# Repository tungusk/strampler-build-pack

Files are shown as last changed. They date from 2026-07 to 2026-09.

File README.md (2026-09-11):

# Strämpler Build Pack

Everything you need to **build your own [CTAG Strämpler](https://github.com/ctag-fh-kiel/ctag-straempler)** —
the open-source ESP32 eurorack sample-streaming module — in its compact
**18 HP Antumbra redesign**. Board files in both Eagle *and* KiCad, complete
BOMs with 2026 sourcing fixes, a ready-to-upload fab/assembly package, and
per-kit ordering guides.

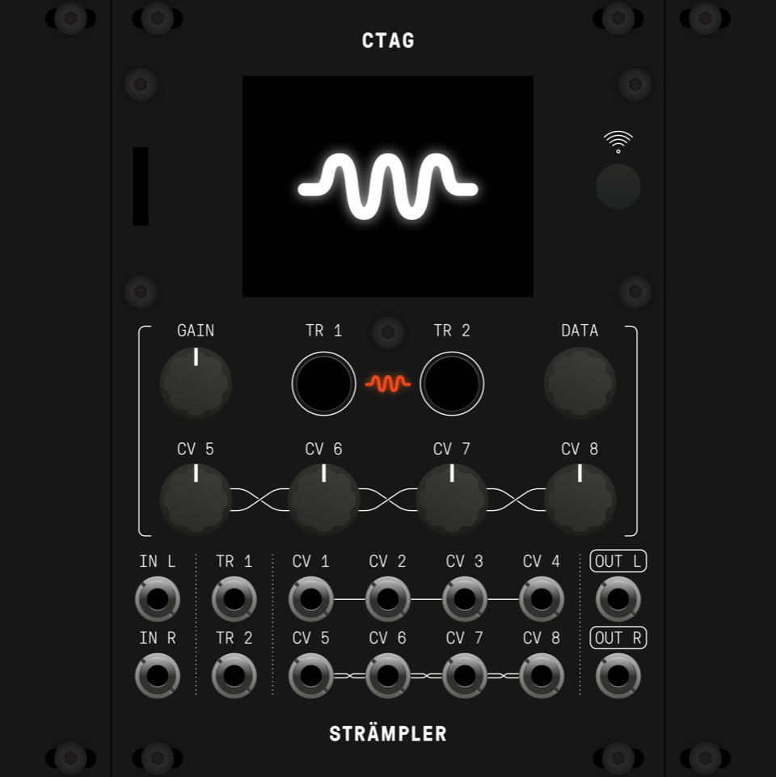
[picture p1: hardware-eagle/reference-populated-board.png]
Antumbra Strämpler


## Why this repo exists

The original design files live inside the firmware repo and are in **Eagle
format — a dead tool** (Autodesk sunset Eagle in 2026). The ready-made
panel/PCB sets that used to be sold are delisted. Several key parts of the
2019 BOM have gone EOL. This pack collects the originals, converts them to
a living format, and documents what it actually takes to build one today.

## What's here

| Path | Contents |
|---|---|
| `hardware-eagle/` | The designer's original Eagle 7.3 files: main board + schematic + FR4 panel (untouched) |
| `hardware-kicad/` | **KiCad 10 conversion** — full linked project (schematic + board + symbol lib), converted panel, 3D verification renders, schematic PDF |
| `bom/` | Official Antumbra BOM (Mouser refs), a schematic-derived cross-check BOM, a **Mouser BOM-tool upload file for one kit**, the non-Mouser parts list, and the CTAG RevD reference BOM |
| `assembly-pcbway/` | Ready-to-upload turnkey assembly package: fab BOM, pick-and-place (CPL), order guide, price estimate |
| `KIT-GUIDE.md` | Ordering bare boards + parts as DIY kits, per-kit costs, build order, licensing |
| `KNOB-OPTIONS-20260911.md` | Knob-cap shopping: what is fitted, the panel's 19.27 mm row gap that caps knob diameter, and the Thonk / AliExpress options screened against it |

## 2026 sourcing notes (the important bits)

- **WM8731 codec: obsolete.** Broker stock only (Rochester Electronics for
  genuine EOL parts). The assembly package marks it DNP for hand-soldering.
- **ESP32-WROVER-B: NRND** → use **ESP32-WROVER-IE** (the **-I**/IPEX
  external-antenna variant is required — the module lives behind a metal panel).
- Jacks/pots/SD from [Thonk](https://thonk.co.uk); TFT + antenna from AliExpress.
- Rough costs: **~$160–195/kit** DIY, **~$350–420** for a fab-assembled build.
  Details in `KIT-GUIDE.md` and `assembly-pcbway/PRICE-ESTIMATE.md`.

## Firmware

- Upstream: [ctag-fh-kiel/ctag-straempler](https://github.com/ctag-fh-kiel/ctag-straempler) (GPL 3.0)
- Extended fork with the multi-machine firmware (drum sampler, looper,
  slicer, granular, glitch, Freesound browser, web teleremote):
  [tungusk/ctag-straempler](https://github.com/tungusk/ctag-straempler), branch `v09-machines`
- Flash with `--flash_size detect`; see the firmware repos for build docs.

## Licensing — read before selling anything

- **Hardware: CC BY-NC-SA 4.0** (unchanged from upstream — see `LICENSE.md`).
  Build for yourself, share these files, remix them: all encouraged.
  **Selling boards/kits/modules requires permission** from the rights
  holders (CTAG and Antumbra). Modifications you distribute must carry the
  same license.
- **Firmware: GPL 3.0** — commercial use allowed with source provision.

## Provenance & changes

Original design © 2019 Robert Manzke, Phillip Lamp, Niklas Wantrupp
([CTAG, Kiel UAS](https://www.creative-technologies.de)); PCB redesign by
David Szebenyi ([Antumbra](https://antumbra.eu)). This pack adds (2026-07,
CC BY-NC-SA 4.0): the KiCad 10.0.4 conversion (`kicad-cli pcb import` for the
boards, GUI Eagle-project import for the schematic; auto-matched layers,
KiCad layer names), generated CPL and fab BOMs, the Mouser kit BOM with EOL
substitutions, verification renders/PDF, and the ordering/cost documentation.
Not affiliated with or endorsed by CTAG or Antumbra — errors are ours, not
theirs. Verify footprints against the Eagle originals before fabbing
modified boards.

## Experimental: E-mu-format panel (2026-09)

`panel-emu/` — a 6" × 6" E-mu Modular style front panel for the main board
with 1/4" Switchcraft jacks, bus-normalled CV/trigger inputs, and a ±12 V
regulator sub-board for the E-mu ±15 V bus. Parametric generator + SVG/DXF
cut and art files + README (BOM, wiring, E-mu conventions). One-off for a
hackerspace system; slow burn.

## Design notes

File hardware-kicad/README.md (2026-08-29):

# Editing the boards (KiCad 10+)

- **Main board + schematic**: open `project/Strampler_redesign_v2_2.kicad_pro`
  — a full linked project (schematic, board, and the Eagle-imported symbol
  library). Footprints are embedded in the board, so it is self-contained.
- **Panel**: open `strampler_panel_v2_2.kicad_pcb` directly in the PCB
  Editor. The artwork is ~34k filled polygons on F.Silkscreen; the copper
  pours are filled zones. It is heavy but edits fine.

After editing, regenerate all fab outputs (gerber zips + centroid) with:

```
./make-fab-files.sh
```

Both gerber sets passed PCBWay audit (2026-07) as generated by that script's
commands.

## Provenance & pitfalls

These files were converted from the Eagle 7.3 originals (`../hardware-eagle/`)
with KiCad 10.0.4. Two importer pitfalls are already fixed here — beware if
you ever re-import from Eagle instead of editing these files:

1. The importer creates **unfilled zones**, which plot as EMPTY gerber
   layers (missing copper, mask and artwork). Fixed by filling copper zones
   and converting non-copper zones to filled `gr_poly` shapes.
2. The importer maps Eagle's t/bRestrict layers to layer `"UNDEFINED"`,
   which KiCad's own parser then refuses to load. The first fix remapped
   them to `User.1` — **which was itself a bug**: `User.1` is not a copper
   layer, so the 1876 tiny restrict rectangles did nothing and the copper
   pours filled straight under the LED light window. The 2026-07 panel run
   came back with a **copper wave** where the original has bare FR4 (found
   2026-08-28 at first-module assembly). **Fixed 2026-08-28:** the 938
   unique rectangles (identical to the F/B.Mask window polygons) were merged
   into one polygon and replaced by a single **keep-out rule area on
   F.Cu + B.Cu** (`copperpour not_allowed`, named "LED light window");
   zones refilled; panel gerbers regenerated. Verified: filled copper ∩
   window = 0 on both layers.

## Main-board audit (2026-08-28) — keep-outs OK, one mask sliver restored

After the panel bug, the main board was checked for the same class of
loss. Eagle's `tRestrict`/`bRestrict` circles (mounting holes of P3 TFT,
jacks, PCB screws) and the `vRestrict` under the crystal all survived as
proper rule areas inside the footprints (`copperpour not_allowed` on
F.Cu/B.Cu; via keep-out on both). Verified with pcbnew: filled copper ∩
every keep-out = 0 (64 pairs). The only dropped item was a 0.15 × 1.3 mm
`tStop` sliver in the `SJ` (solder jumper) package — the mask opening
between SJ1's two pads that makes it bridgeable. Restored as an `fp_rect`
on B.Mask (SJ1 is on the bottom); main gerbers regenerated. The fabbed
2026-07 main boards lack that sliver: SJ1 can still be bridged, it just
takes a blob over the ~0.1 mm mask web. SJ1 joins ESP32 IO19 to TFT
connector pin 9.

## Panel v2_3 (2026-08-29) — M7 pot holes

`strampler_panel_v2_3.kicad_pcb` is the current panel: v2_2 plus the four
CV pot holes and POT1's hole resized 9.2/8.2 → 7.2 mm for M7-bushing pots
(Same Sky PTN091/PTN092 — see build-pack COMPLETION-SHOPPING §POT2–5).
The other 8.2 mm hole is the ENCODER's — deliberately unchanged.
`make-fab-files.sh` builds v2_3; v2_2 is kept as the pre-M7 version
matching the five fabbed (LED-window-defective) panels.

## Refilling zones from the command line

`kicad-cli` has no zone-fill command. After editing a board outside the
GUI (e.g. scripted changes), refill with the bundled Python before
running `make-fab-files.sh`:

```
PY=~/Applications/KiCad/KiCad.app/Contents/Frameworks/Python.framework/Versions/Current/bin/python3
$PY -c "import pcbnew; b=pcbnew.LoadBoard('strampler_panel_v2_2.kicad_pcb'); \
  pcbnew.ZONE_FILLER(b).Fill(b.Zones()); pcbnew.SaveBoard('strampler_panel_v2_2.kicad_pcb', b)"
```

(`SaveBoard` drops a stray `.kicad_pro` next to the panel — delete it.)

Verify against the Eagle originals and the `render-main-*.png` references
before fabbing modified boards. License: CC BY-NC-SA 4.0 (see ../LICENSE.md).

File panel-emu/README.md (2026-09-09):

# E-mu format front panel (experimental, one-off) — 6" × 6", 1/4" jacks

A vintage E-mu Modular style panel for the Strämpler main board, for the
local hackerspace's E-mu system. Not a board-house part: cut it from
aluminum on the mill or from plastic on the laser, then mark or engrave
the artwork. Generated by `gen_emu_panel.py` (parametric — edit the CONFIG
block, rerun, all files regenerate).

| file | what |
|---|---|
| `emu_panel.svg` | true-scale (mm), two groups: `CUT` (red hairline) and `ART` (black text, blue rules) |
| `emu_panel_cut.dxf` | outline + every hole, layer `CUT` — the file for the mill / laser |
| `emu_panel_art.dxf` | text + lines, layer `ART` — for engraving / laser-marking / a print mask |
| `emu_panel.png` | preview |
| `emu_panel_art.svg` / `emu_panel_art.png` | artwork only, transparent (PNG 600 dpi) — the file UV-print vendors take |
| `emu_panel_fpe.fpd` | Front Panel Designer project: cut DXF imported + art PNG placed, 2 mm natural anodized — priced $89.72 on 2026-09-08 |

## Format facts (E-mu Modular, 1970s)

- Modules are **6" high**, widths in **3" steps** (3 / 6 / 12"). The board
  footprint is 91.3 mm ≈ 3.6", so this panel is one 6" × 6" unit.
- Natural bright aluminum, black lettering, **blue accent lines**.
- **Mounting: the hackerspace cabinet has WOOD rails** (Arlo, 2026-09-07),
  so there is no fixed hole pattern to hit — the four corner holes
  (Ø4.2, clearance for #6 wood screws; use 3.6 for #4) just need to land
  on the rail and match the neighbouring modules' inset (0.25" from each
  edge is the placeholder). **Measure the rail height** (panel edge to the
  rail's inner edge, top and bottom): nothing that protrudes behind the
  panel can sit over the rail. The bottom jack rows (OUT L/R and CV 5–8,
  hole centres at y 17, nut edges at y 10.7) and the KYBD switches near
  the top need to clear it — if the rails are taller than ~10 mm those
  rows move inward. Countersink if the neighbours use flat-head screws.

## Panel thickness — the real constraint

The board's pots and encoder pass **through** this panel and are held by
their own nuts, so the panel can't be thicker than their bushings allow:

| part | bushing | max sensible panel |
|---|---|---|
| Same Sky PTN091/PTN092 pots (POT1–5) | M7 × **5 mm** long | **≤ 2.0 mm** (5 − 2.5 mm nut − thread engagement) |
| EC12 encoder (SW1) | M7, ~7 mm | 3 mm |
| Switchcraft 1/4" jacks | 3/8"-32, 0.276" (7 mm) | 3 mm |
| SMA bulkhead (ANT) | 1/4"-36, ~7 mm | 3 mm |

So: **1.5–2.0 mm aluminum** (1/16" = 1.6 mm is ideal, same as the FR4
panel), or 2 mm acrylic at most. 1/8" (3.2 mm) aluminum or 3 mm acrylic
will leave the pot nuts with no thread. If the shop only has 3 mm stock,
counterbore the six pot/encoder holes from the back to ~1.6 mm.

Board-locked cutouts (display window, 4 CV pots, gain pot, encoder, two
buttons, LED, antenna, five M3 panel screws) are copied verbatim from the
Eurorack panel `hardware-kicad/strampler_panel_v2_3.kicad_pcb` and only
translated by `BOARD_ORIGIN`. Countersink the five M3 holes if the panel
is aluminum (they take the panel-to-standoff screws).

Omitted on purpose: the Eurorack rail holes and the fourteen 3.5 mm jack
holes. The SD card slot (2.5 × 13 mm at the left edge) is **kept** — set
`INCLUDE_SD_SLOT = False` to drop it if the card is to stay inside. (The
TFT module's own SD socket is **not wired** to the ESP32; using it would
mean running the SD lines to it.)

## 1/4" jacks — wiring

The board's PJ398SM pads stay unpopulated; each 1/4" jack gets two flying
leads (tip → `IN` pad, sleeve → `GND` pad). The `NORM` (switch) pad is
tied to ground on the board, so **plain 2-lug TS jacks are all that's
needed** — no switching contact. Twist tip/sleeve pairs; audio in/out and
the two V/oct inputs get the shortest, tidiest runs.

| jack | signal | board pad (panel x, y mm) | jack hole (x, y mm) | lead ≈ |
|---|---|---|---|---|
| J5 | TR1 | 75.02, 47.35 | 15.40, 118.60 | 108 mm |
| J6 | TR2 | 75.02, 34.65 | 39.40, 118.60 | 106 mm |
| J7 | CV 1 (V/OCT between the pair) | 87.74, 47.35 | 15.40, 93.20 | 101 mm |
| J8 | CV 2 | 100.40, 47.35 | 39.40, 93.20 | 91 mm |
| J11 | CV 3 (±5V between the pair) | 113.20, 47.35 | 15.40, 67.80 | 115 mm |
| J12 | CV 4 | 125.93, 47.35 | 39.40, 67.80 | 104 mm |
| J2 | L (IN between the pair) | 62.29, 47.35 | 15.40, 42.40 | 62 mm |
| J1 | R (IN) | 62.29, 34.65 | 39.40, 42.40 | 39 mm |
| J4 | L (OUT between the pair) | 138.65, 47.35 | 15.40, 17.00 | 142 mm |
| J3 | R (OUT) | 138.65, 34.65 | 39.40, 17.00 | 116 mm |
| J9 | CV 5 (knob above) | 87.74, 34.65 | 68.65, 17.00 | 41 mm |
| J10 | CV 6 (knob above) | 100.40, 34.65 | 89.87, 17.00 | 36 mm |
| J13 | CV 7 (knob above) | 113.20, 34.65 | 111.08, 17.00 | 33 mm |
| J14 | CV 8 (knob above) | 125.93, 34.65 | 132.29, 17.00 | 34 mm |

Layout (Arlo 2026-09-07): **CV 5–8 jacks in a row across the bottom,
each directly below its knob** (same x as POT2–5), in the strip under the
PCB's bottom edge (the PCB is 108 mm tall inside the 128.5 mm panel
region, so the board region is raised to y = 18 and the jack row sits at
y = 17 with ~5 mm nut clearance to the PCB edge). The other ten jacks are
a 2 × 5 field on the left — TR1/TR2, CV 1/2, IN L/R, OUT L/R, CV 3/4 —
so the panel's bottom row reads CV 3…CV 8 in one line (Arlo 09-07). Blue artwork: an E-mu-style solid blue band 2.5 mm wide bleeding off the
panel edge (the art DXF carries its inner boundary; fill between it and
the panel outline), a rounded
box around the interface block, and ONE L-shaped rounded outline joining
the left jack field to the CV 5–8 row along the bottom (tops of the two
boxes aligned); wordmark "CTAG STRÄMPLER" alone between. Labels (Arlo 09-07): CV jacks read "CV 1"…"CV 8"; the V/OCT, ±5V, IN and OUT
words sit between the two jacks of their row (audio jacks read just L / R); the four attenuator
knobs read CV 5–8 like the jacks below them; trigger jacks are TR1/TR2 and
the two push buttons under the screen are labelled TR1/TR2 too (manual
triggers).

Jack field geometry: left field two columns 24 mm apart, five rows at 24 mm
pitch (tightened from 1" to make room for the bus toggles above); bottom row on the knob spacing (21.2 mm). Ø9.6 holes (3/8"-32
bushing). Plugs clear each other at both pitches. Switchcraft bodies are 0.5" wide × 0.62"
tall behind the panel — orient the lugs toward the board.

## Bus normalling — two ganged KYBD switches, one per column

Decided 2026-09-07: E-mu's two keyboard buses drive the two CV/trigger
pairs independently. Each column of the left field has its own **BUS
1 / off / 2** switch (one "BUS" word centred between the two switches; E-mu called it KYBD) at the top (x 15.4 and 39.4, y 131.5): a **DPDT
ON-OFF-ON** mini toggle (C&K 7203 ~$7, generic MTS-203 ~$1, Ø6.5 hole),
"1" and "2" marked beside it (up = keyboard 1, down = keyboard 2, centre
= that pair un-normalled). A light blue chain line runs straight down
each column centre from the switch through the TR jack to the V/oct
jack, broken around labels and holes, to show what it feeds.

| switch | pole A: VOICE 1/2 → | pole B: GATE 1/2 → |
|---|---|---|
| column 1 (x 15.4) | jack **1** (V/oct, J7) | **TR1** (J5) |
| column 2 (x 39.4) | jack **2** (V/oct, J8) | **TR2** (J6) |

Both on keyboard 1 = a mult (both pairs follow one keyboard; the VOICE
line just sees two high-impedance inputs). One on 1, one on 2 = two
players / keyboard + sequencer, each with its own CV and gate. Wiring per
pole: bus "1" line → up contact, bus "2" line → down contact, common →
that jack's **shunt (normal) lug**; tip lug → board `IN` pad; sleeve →
`GND`. With no plug the shunt closes to the tip and the bus drives the
input; a plug opens it. Four switching jacks (1, 2, TR1, TR2); the other
ten stay plain 2-lug. TR inputs get the keyboard **gate** (high while a
key is held) so gate length reaches the firmware; the bus TRIG pulse
lines are left unused (one-wire swap at the DIP end if ever wanted).

Facts behind this (see the research section): the buses come off a
**16-pin DIP socket** at the module position; E-mu gate/trigger is a
**positive 0/+5 V TTL** signal (7416 open-collector + 1 k pull-up), which
the board's 100 k / NPN trigger input takes directly — **no inverter**;
VOICE is 1 V/oct into CVIN0/1's 180k/47k networks, nothing to scale. Still
open: which DIP pins carry GATE 1/2 (meter it).

## Power conversion — ±15 V bus → ±12 V board (sub-board behind the PCB)

The E-mu bus is ±15 V; the Strämpler's rail caps are 16 V parts, so the
module carries its own linear regulators. **They are not on the panel**:
the cabinet's wood rails sit behind the panel's top and bottom strips,
so there is no depth there. Instead a **small regulator board mounts
behind the PCB** — on the PCB's existing M3 standoff holes with longer
M/F standoffs (or double-sided foam tape onto the PCB back), right next
to the Eurorack power header it feeds. 7812 gets a clip-on TO-220
heatsink (~1.5 W at the ESP32's 0.5 A → ~30 °C rise on a 20 °C/W clip,
fine); the 7912 runs cool. Ribbon from the cabinet's DIP socket to the
sub-board; short twisted leads from the sub-board to the header.

| qty | part | ≈ | notes |
|---|---|---|---|
| 1 | **L7812CV** (TO-220) | $0.60 | with clip-on TO-220 heatsink (e.g. Aavid 574502B00000G, ~$1) |
| 1 | **L7912CV** (TO-220) | $0.60 | tab = INPUT (−15 V): keep it clear of ground; no heatsink needed |
| 4 | M3 M/F standoffs (length = PCB rear clearance, ~10 mm) + M3 screws | | sub-board on the PCB's standoff holes |
| 1 | perfboard ~40 × 25 mm | | the sub-board |
| 2 | 1 µF 50 V ceramic (X7R) | | regulator inputs, close to the pins |
| 2 | 10 µF 25 V (ceramic or electrolytic) | | regulator outputs |
| 2 | 1N4007 | | reverse diodes output→input across each regulator (protects on power-down) |
| 1 | 16-pin DIP plug for ribbon (3M 3416-xxxx style IDC DIP plug) + ~30 cm 16-way ribbon | $2 | the bus pickup |
| 1 | 2 × 5 IDC socket or bare Eurorack power header pins | | into the board's P4 power header (10-pin: −12, GND, +12, +5, CV/gate) |
| — | heat-shrink, 0.5 A fuse holder (optional) | | |

Wiring: DIP pin 7 (+15) → 7812 IN, DIP pin 8 (−15) → 7912 IN, DIP pins 1–4
(GND) → both regulator commons + board GND. 7812 OUT → board
+12, 7912 OUT → board −12 via the Eurorack header (pin order per the
board's P4 silk: the shrouded header is keyed, red stripe = −12). Leave
the bus +5 unused (the board makes its own 3.3 V). Add a 0.5 A fuse in
the +15 lead if the cabinet supply is a vintage 2900/2910 (3 A / 2 A).
**Before first power-up:** meter the DIP socket in the cabinet — the pin
map came from a 1974 drawing and the socket keying is not documented.

Alternative that skips all of this: a separate ±12 V brick for the
module and only VOICE/GATE/TRIG/GND from the DIP.

## Jack sourcing (14 needed, buy 16)

Period-correct is the Switchcraft open-frame family; the panel doesn't
need the switch contact, so the 2-lug versions are the right ones.
Prices are 2026 list-ish from the usual dealers — verify at order time.

Of the 14: **10 × plain 2-lug** (rows below) + **4 × switching 12A/112A**
for the normalled inputs 1, 2, TR1, TR2 (see Bus normalling).

| option | part | type | ≈ each | notes |
|---|---|---|---|---|
| **vintage-correct** | **Switchcraft 11** | open frame, mono, 2 lugs | $3–4 | the classic 70s American-modular jack; Amplified Parts, Mouser 502-11 |
| enclosed, same feel | Switchcraft 111 (111X) | enclosed, mono, 2 lugs | $4 | dust-proof; same bushing |
| switching (not needed) | Switchcraft 12A / 112A | open / enclosed, shunt tip, 3 lugs | $4–5 | only if a future board uses NORM |
| budget | Rean NYS229 / Neutrik NJ2FD | enclosed, mono, solder lugs | $1.5–2 | Mouser/Digi-Key, fine electrically |
| cheapest | generic open-frame TS, AliExpress | | <$1 | check the bushing is 3/8"-32 |

All of these use the **3/8"-32 bushing → Ø9.5 mm hole** (the file uses
9.6 for clearance). Knurled nut + lock washer come with the Switchcrafts.

## E-mu Modular conventions — researched 2026-09-07

Primary source: the *Eµ Systems Modular Technical Manual* (schematics
1972–80, compiled by Rob Keeble; archive.org
`e-mu-modular-technical-manual`, 129 pp). Everything below was read off
the original drawings unless marked otherwise.

**Panels.** 6" high, widths in 3" steps. Vintage Synth Explorer: *"bright
and shiny 1/8" aluminum panels with nice blue lines separating each
module"* — so period panels were **1/8" (3.2 mm)** aluminum, black
lettering, blue lines. (Our pot bushings can't take 3.2 mm — see the
thickness table; counterbore or use 1/16".) The manual is schematics only:
**no mechanical drawings, no mounting-hole pattern** → still measure the
cabinet.

**The bus is a 16-pin DIP socket at every module position** (2900 Power
Supply Module schematic, doc 2900-001-001, 22 Apr 1973: "DIP SOCKETS (FOUR
IDENTICAL)"). Modules plug in with a DIP header on a ribbon. It carries:

| signal | notes |
|---|---|
| VOICE 1, VOICE 2 | the two keyboard CVs, 1 V/oct |
| GATE 1, GATE 2 | per keyboard |
| TRIG 1, TRIG 2 | per keyboard — **gate and trigger are separate lines** |
| SYNC 1, SYNC 2 | VCO sync buses (module-to-module, no PSU source) |
| GND, +15 V, +5 V, −15 V | |

Pin map read off the 2200 VCO module schematic (doc 2200-001-003, left
column 1–8 top→bottom, right column 16–9 top→bottom): **1–4 GND, 7 +15,
8 −15, 9 +5, 16 VOICE 1, 15 VOICE 2, 14 SYNC 1, 13 SYNC 2**. The
gate/trigger pins are among **5, 6, 12, 11, 10** (the VCO doesn't use
them; the 2350 TG drawing is too faint to assign them with confidence).
**Verify at the cabinet with a meter** before wiring: power pins are
unambiguous, VOICE/GATE/TRIG identify themselves when a key is pressed.

**Module convention for keyboard selection.** Every module has ONE
`KYBD 1 / 2` switch (VCO: 2-pole with SYNC 1/2 alongside; 2350 Transient
Generator: a ganged DPDT that selects keyboard 1 or 2 for BOTH its gate
and its trigger, and the module's EXT GATE / EXT TRIGGERING jacks are
**normalled from the selected bus through the jack's switch contact**).
That is exactly the scheme on this panel. To be E-mu-faithful the two
separate toggles would become **one ganged KYBD 1 / off / 2 switch**
feeding jack 1 (← VOICE) and TR1 (← GATE) — a DPDT ON-OFF-ON (C&K 7203,
or a generic MTS-203). **Adopted 2026-09-07, then doubled: a second
identical switch feeds jack 2 + TR2 from the second keyboard bus.**

**Gate / trigger polarity: POSITIVE, 0 / +5 V TTL.** 4000 Keyboard
schematic (doc 4000-001-003, 26 Jun 1973): TRIGGER (J4) and GATE (J3) are
**7416 open-collector outputs with 1 kΩ pull-ups to +5 V**. The 2200
VCO's own GATE INPUT is 100 k into a 2N3904 base with a 1N914 clamp —
the same topology as the Strämpler's TR inputs. **No inverter needed;**
a +5 V gate into our 100 k / NPN input is fine. (Not S-trig.)

**Keyboard cable (for reference):** 12-conductor Burndy, 4000 output
connector: 1 analog GND, 2 digital GND, 3 +15, 4 −15, 5/6 +5, 7 VOICE,
8 GATE, 9 TRIGGER (4920-011-001 gives the wire colours). Firm-wire patch
pins on module rears are "Burndy pins" (4910-K).

**⚠ Power: the E-mu bus is ±15 V, the Strämpler is a ±12 V board.** The
digital side is fine on +15 (Recom R-78E3.3 switcher, 7–28 V in; ADP7118
LDO ≤ 20 V; TL072s happy at ±15). The problem is the rail capacitors:
**C38/C39/C42 are 16 V tantalums** (TCTAL1C226) and **C36 is a 16 V
polymer** — at ±15 V they'd sit at 94 % of rating, far outside tantalum
derating, and the −10 V LM4040 reference's series current also rises.
**Do not feed the board from the ±15 bus directly.** Two clean options:
1. **Regulate on the panel**: 7812 / 7912 (TO-220, small heatsink on the
   7812 — the ESP32 + WiFi side draws ~0.3–0.5 A, ≈1.5 W drop) plus
   four caps on a scrap of perfboard behind the panel; take +15/−15/GND
   from the DIP, leave +5 unused. Check the cabinet supply has ~0.5 A of
   +15 headroom (2900 = 3 A, 2910 = 2 A, 2920 = 1 A per the PSU table).
2. **Separate ±12 V supply** for the module (any Eurorack brick), with
   only VOICE / GATE / TRIG / GND taken from the bus.

**Sources:** manual pages 54 (2200 VCO), 55 (VCO gate input), 76 (2350 TG),
104 (2900 PSU + DIP sockets), 115 (4000 keyboard output stage), 128–129
(4910/4920 cables); [Vintage Synth Explorer](https://www.vintagesynth.com/e-mu/modular-systems)
(1/8" aluminum, blue lines, 2 CV/gate 1 V/oct); [Silicon Breakdown](https://siliconbreakdown.com/e-mu-modular)
(2200: "±15 V @ 50 mA, +5 V @ 10 mA"; "Power Bus Connected Inputs:
Keyboard CV's 1 & 2 & Sync Busses 1 & 2"); [AMSynths](https://amsynths.co.uk/home/synthesizers/emu-systems-modular-2003/)
(6" high, 3/6/12" wide); Mos-Lab reissue (2026) exists but publishes no
mechanical spec.

## Fabrication — one-off vendors (checked 2026-09-08)

Single custom panels are routine in the synth world; no minimums anywhere
below. The generator already splits the design into CUT (outline + holes)
and ART (text + blue lines) — that is exactly the split every vendor wants.
Pick **2 mm** stock (see "Panel thickness" above); all three carry it.

### Front Panel Express — QUOTED 2026-09-08: $63.08 bare / $89.72 printed

US arm of Schaeffer AG (frontpanelexpress.com). CNC-milled anodized Al;
artwork = engraving with hand-applied colour infill **or** full-colour UV
print on the anodize. Quotes exist only inside their free *Front Panel
Designer* app (macOS universal build, `FrontDesign.app`, installed on the
bench Mac 09-08); the webshop just takes the `.fpd`. Below 29 pieces the
app price *is* the quote (their FAQ). Price list dated 06/06/2025, ex tax
and shipping; 5 business days standard.

| item | price |
|---|---|
| Preparing/finishing | $14.99 |
| Material: 2.0 mm aluminum anodized / natural | $12.59 |
| Frame 152.40 × 152.40 mm | $12.34 |
| 2 free contours (display window, SD slot) | $3.42 |
| 43 drill holes ($0.32–0.60 each) | $19.48 |
| 1 tool change | $2.26 |
| **Bare panel total** | **$63.08** |
| UV print, full panel (`emu_panel_art.png`, 152.4 mm square) | $26.64 |
| **Printed panel total** | **$89.72** |

Quantity breaks on the printed panel: 5–9 pcs $80.75, 10–19 $71.78,
20–29 $62.80 each.

Files: **`emu_panel_fpe.fpd`** (the priced design, artwork embedded) and
**`emu_panel_art.png`** (art only, transparent, 600 dpi = 3600 px square).
To redo it from scratch: File ▸ Import ▸ `emu_panel_cut.dxf` (mm, "entire
front panel", defaults) → the import ends in *Front panel properties*:
Aluminum anodized / Natural, **thickness 2.00 mm** (Cancel here discards
the import) → Insert ▸ Print graphic, press **M**, reference 0/0 → Import
`emu_panel_art.png`; reference point bottom-left, 100 % → File ▸ Pricing.
The DXF came in clean: every hole recognised as a drill hole, the display
window and SD slot as free contours, size 152.40 × 152.40.

Not yet decided in the FPD file: countersinks on the five M3 holes,
engraving instead of print, and whether the blue border prints well with
no white under-print on natural anodize (their notes say print stays on
the surface, aluminium shows through light colours — blue should be fine).

### Meface (UK) — likely cheaper, sub-surface print

meface.co.uk. **Sub-surface** digital print on anodized Al, CNC-cut — the
print sits under the anodize, closest match to a period silkscreened E-mu
panel and scratch-proof. Takes any vector file (SVG/PDF) or an `.fpd`.
1.5 / 2 / 2.5 / 3 mm. Fixed price per HP: a 10 HP 4U 2 mm panel was
£13 + VAT → 6"×6" ≈ £40–60 + shipping to the US. No setup charge; one-off
sample with full refund (incl. return postage) if unhappy. Not quoted yet.

### SendCutSend (US) — blank only

Laser-cut 5052 Al blank, ~$15–30; anodizing/powder coat available; **no
engraving, print or silkscreen**. Artwork becomes a second step — CerMark
on the hackerspace's CO2 laser gives durable black text on bare or
clear-anodized Al; the blue lines are hard that way.

Recommendation: Front Panel Express is a known $89.72 with a 5-day turn;
try Meface for a quote if the ~$40 saving matters more than the wait.

## Open items before cutting

1. Mounting: wood rails → confirm rail edge positions + neighbours' screw
   inset/head style, then set `MOUNT_HOLES` / `MOUNT_DIA`.
2. Panel stock thickness (1.6 mm aluminum preferred; period panels were
   1/8" — counterbore the six pot/encoder holes if you go that thick).
3. Artwork method — see "Fabrication — one-off vendors": Front Panel
   Express UV print quoted $89.72 (file `emu_panel_fpe.fpd` ready to
   upload); Meface (sub-surface print) unquoted; CerMark on the hackerspace
   laser only if you go the blank-panel route.
4. **Power**: 7812/7912 sub-board behind the PCB (BOM above); still
   needs the cabinet DIP pinout metered.
5. Bus DIP pinout for GATE/TRIG (pins 5/6/11/12/10): confirm with a meter.
6. ~~Toggle scheme~~ — decided: two ganged KYBD 1/off/2 (DPDT), one per column.

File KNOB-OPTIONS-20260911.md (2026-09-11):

# Knob cap options — browsing notes, 2026-09-11

Shopping for **looks**, not a commit. Nothing ordered. This file exists so the
research does not have to be redone.

---

## What is on the panel now

| Position | Qty/unit | Shaft | Cap fitted |
|---|---|---|---|
| POT1 GAIN (dual-gang) | 1 | 6 mm **knurled T18** | Davies 1900h clone, set screw |
| POT2–5 = CV 5–8 (Same Sky PTN091) | 4 | 6 mm **knurled 18T** | same |
| SW1 DATA (EC12 encoder) | 1 | 6 mm **D-shaft** | separate push-on D-bore cap |

Both bought on AliExpress, order placed 2026-07-26 (see `ORDER-CART-ALI-20260725.md`):

- **Knobs** — item `1005006890019684` → redirects to `3256806703704932`
  (DAIERBUMP, "1900 Davies Style 6.35MM Knob Metal Insert"). **6.35 mm bore,
  brass insert, set screw.** 30 on hand, black. 6 colours offered: white, red,
  green, blue, black, cream. ~$1.09–1.50 per 10.
- **Encoder cap** — item `3256806101256136`, KY-040 style, true 6 mm **D-bore**,
  hard ABS, **no indicator line**, flat top for the push switch. 40 on hand.

> **The set screw is the important part.** A 6.35 mm round bore with a grub
> screw clamps ANY 6 mm shaft — T18 knurled and D alike — so one part can serve
> all six positions. Splined (T18) and D-bore push-on caps cannot: each fits
> only its own shaft profile. When screening alternatives, set-screw parts are
> the flexible ones.

---

## The panel decides what fits

Parsed from `hardware-kicad/strampler_panel_v2_3.kicad_pcb` (do not eyeball this
— parse it):

- **CV 5–8 row** (y −45.83): x = 13.90 / 35.12 / 56.33 / 77.54, drill 7.2 mm
- **Control row** (y −65.10): GAIN (7.2), TR1 (9.5), TR2 (9.5), encoder (8.2)
- **Horizontal pitch: 21.22 mm** (both rows)
- **Row-to-row gap: 19.27 mm**  ← **the binding constraint**

Two adjacent knobs touch when the **sum of their radii** reaches the gap:

- Same knob everywhere → max **19.27 mm** diameter touching, **≈17 mm** for a
  ~2 mm visual gap.
- **Mixed sizes are the escape hatch.** Small knobs on the control row (GAIN +
  DATA) let the four CV knobs grow to **~19 mm**: 2.2 mm clearance horizontally
  at the 21.22 mm pitch, 3.8 mm to the row above. This also restores DATA's
  by-feel distinction (see the 07-25 reasoning in `COMPLETION-SHOPPING-5UNITS.md`)
  through size contrast instead of a different part family.

Standing rules from earlier rounds: **plastic, not aluminium**; **not
soft-touch**; the **encoder wants no indicator line** (an encoder has no
absolute position, so a pointer points at nothing).

---

## Thonk — thonk.co.uk (UK, ships worldwide, prices ex-VAT)

Worth using as the **spec sheet** even if buying elsewhere: every product lists
diameter and height, which Ali listings almost never do.

### The direct equivalent of what is fitted
**Davies 1900h Clone – 6.35 mm Round Shaft** — `/shop/1900h-round/` — £1.30
"High quality brass insert with set screw, 6.4 mm shaft, ABS, 12 mm diameter at
the base and 16 mm tall." **20 colours**: black, dark red, chocolate, green,
white, transparent, orange, light blue, natural, cream, mustard, forest, yellow,
dark blue, pink, violet, light grey, dark grey, red, blue + black NO-LINE.

Same family, other fittings (push-on, so each fits only its own shaft):
- `/shop/1900h-t18/` £0.75 — T18 splined, **pots only**, ~20 colours,
  + Black and Transparent **NO-LINE** at £0.68
- `/shop/1900h-d/` £0.75 — D-bore, **encoder only**, 20 colours,
  + **NO-LINE in black, white, light grey, dark grey, cream** at £0.68
  (red no-line was out of stock)

> **Note for the encoder:** the D-shaft no-line variants would let DATA use the
> same mould family and colour stock as the pots while still having no pointer.
> The listing's warning that "the pointer is on the curved side of the D … not
> suitable for all D-shaft pots" is irrelevant on a no-line knob — there is no
> pointer to misalign. Trade-off: same 12 mm body as the pots, so the by-feel
> distinction is lost unless sizes are mixed.

Bulk on all of the above: 10+ −5%, 25+ −7%, 100+ −10%, 500+ −20%.

### 6.35 mm set-screw alternatives that FIT (≤ ~17 mm)

| Design | Ø | H | £ | character |
|---|---|---|---|---|
| Davies 1900h clone | 12 | 16 | 1.30 | *current* — tall, fluted, skirted |
| **Small Fluted** `/shop/knobs-small-fluted/` | 15 | 10.5 | **0.74** | ribbed barrel, no skirt, much lower |
| **Small Ridged Pointer** `/shop/small-ridged-pointer/` | 13 (14.5 at tip) | 13 | 1.30 | ridged, pointed nose; black/white/lt-grey only |
| **Synth Pointer – Mini** `/shop/synth-pointer-knobs/` | 14 | 11 | 1.05 | Synth Tech / Pittsburgh / L-1 look, same brass insert as the 1900h |
| **Synth Pointer – Small** | 16 | 11 | ~1.2 | same family; 3.3 mm clearance, tight but legal |
| Rogan RB `/shop/rogan-buchla/` | **not stated** | — | 0.22–4.50 | Buchla / Verbos look, USA made — **measure before buying** |

### Ruled out on size

| | Ø | why |
|---|---|---|
| Erica Synths small `/shop/erica-knobs-6-35mm-shaft/` | 19 | 0.27 mm to the row below |
| Small Fluted **Skirt** | 19 | same |
| 'Mini MXR' `/shop/mini-mxr/` (T18 only) | 19 | same — a shame, Thonk colour-match it to the 1900h |
| 'MXR' small / large `/shop/mxr-style-knobs/` | 20 / 25 | **exceeds** the 19.27 gap — would collide |
| Erica medium / large | 24 / 28 | too big |
| Synth Pointer medium / large | 27 / 33 | too big |
| Davies Fine XL Skirted 1600BM `/shop/1600bm/` | **38.1** | genuine Davies, way out |

Ruled out on the standing rules: **Bastl aluminium**, **Sifam Soft Touch encoder
knobs**, **Spectrum soft-touch D-shaft set**.

---

## AliExpress — far more variety, roughly 1/10 the price

Your knob is really a **guitar-pedal knob**, and that category is enormous.
Search that lands well: `6.35mm knob set screw guitar pedal`. Same test applies
— 6.35 mm bore + set screw fits all six positions.

**Pulled up and eyeballed 2026-09-11:**

| Design | Item | Price | Notes |
|---|---|---|---|
| **Smooth barrel cap, 13 × 16 mm** | `3256805934267586` | **$1.09/10 = $0.11 ea** | **Dimensions actually stated.** 13 mm Ø × 16 mm tall ≈ the 1900h footprint (12 × 16), so clearance is a non-question. Smooth, no skirt, no flutes, **no indicator line**. 7 colours: black, green, orange, purple, red, white, yellow. Cleanest and cheapest of the lot. |
| **Davies 1510** | `3256812318817007` | $4.56 / 5–10 pc | NOT a smaller skirted knob as assumed — it is a **duckbill pointer**: flat top, protruding nose, no fluting. ABS, black only in this listing. |
| **Skirted "jazz bass"** | `3256806512237215` | $1.09/5 = $0.22 ea | Wide skirt, fluted cap, dot-and-line indicator. Closest in spirit to the 1900h but broader and flatter. 9 colours incl. red, cream, green, grey, yellow, purple. |
| **Chicken head, clear** | `3256807642556410` | $7.72/16 | Translucent body, black pointer, brass insert. Biggest visual statement. **No dimensions given** — chicken heads run long nose-to-tail and the row gap is 19.27 mm, so measure before buying. |

**Seen in search, not opened:**
- `3256806897372581` — 15× Davies 1510 **style pointer**, 1/4" 6.4 mm
- `3256812045540311` — Davies 1510 **duckbill**, listing says **19 × 1x mm**
- `3256807826974915` — 100 pc **18T** 1900H style — splined, **pots only**
- `3256807544573411` — 10 pc "silver top" (plastic body, metal cap)
- `3256807512572484` / `3256807505096421` — KN-19-14 knurled pedal knob
- `3256806065523459` — Davies 1900 style **aluminium** — fails the no-metal rule
- `3256812885747807` — chrome dome, all metal — same

DAIERBUMP and DaierTek are the same seller family already used, so a re-order
consolidates shipping.

---

## Conclusions

1. **Spec at Thonk, buy on Ali.** Thonk publishes Ø and height on everything;
   Ali mostly gives a photo. With 19.27 mm between rows that spec is the one
   thing that cannot be guessed. Identify the archetype and its real dimensions
   where they are published, then find the same thing for a tenth the price —
   which is exactly the story of the 1900h already fitted.
2. **If one thing gets ordered for looks**, the smooth 13 × 16 barrel
   (`3256805934267586`) is the pick: published dimensions that clear the panel,
   $0.11, and no indicator line — which suits the encoder as well as the pots.
3. **If the pointer stays**, the skirted jazz-bass is the silhouette change.
4. **Mixing sizes is unexplored and cheap** — small on GAIN + DATA, ~19 mm on
   the four CVs. Nothing on the panel forbids it and it solves DATA-by-feel.

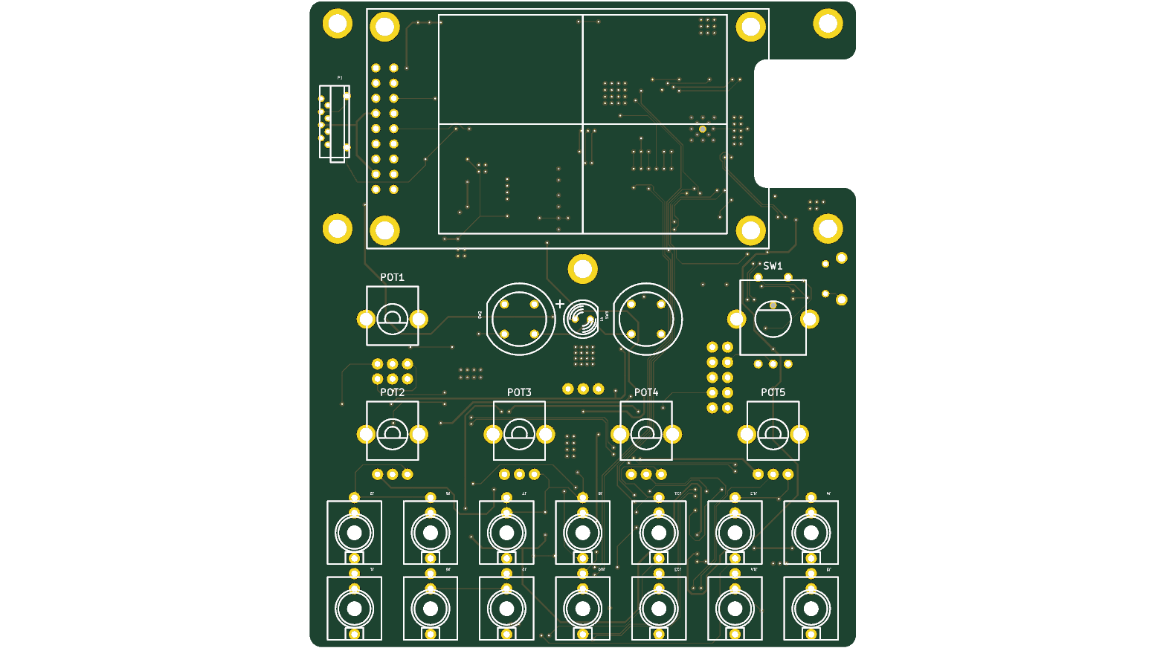
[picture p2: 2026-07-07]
hardware-kicad/render-main-top.png

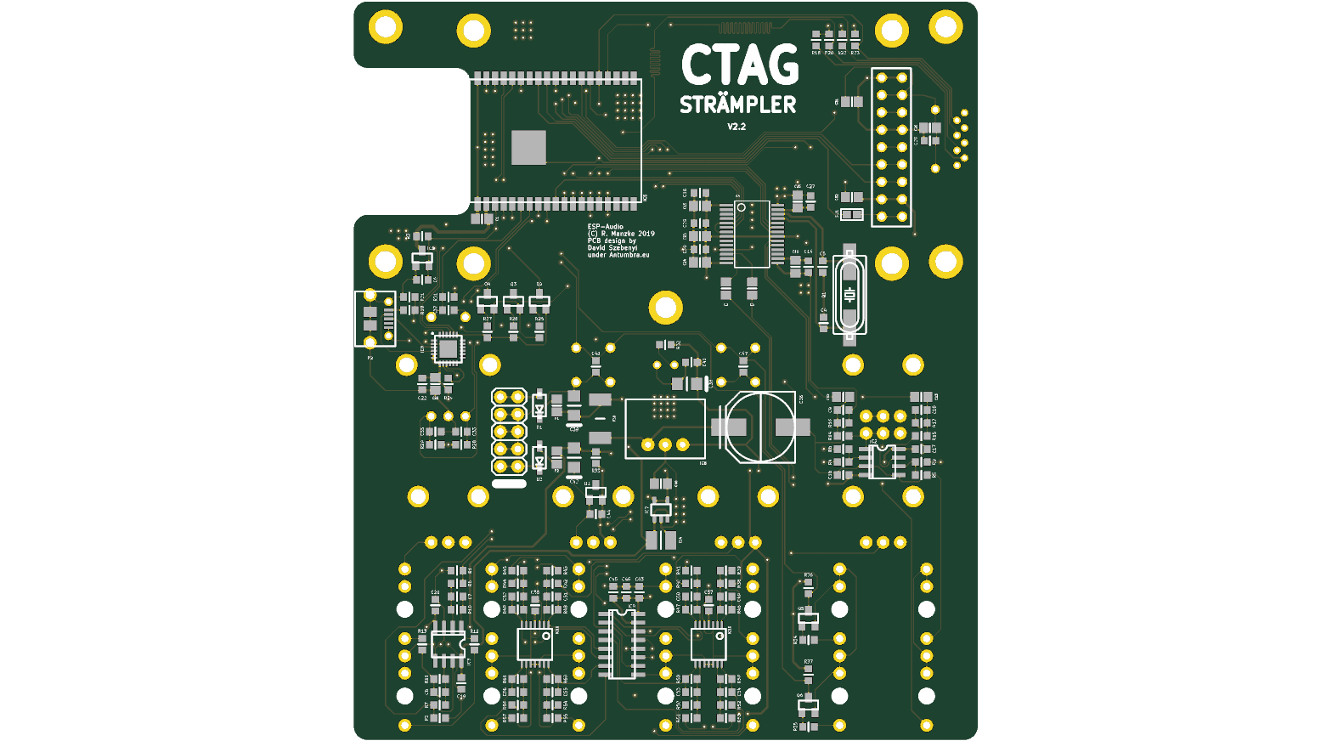
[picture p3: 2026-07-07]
hardware-kicad/render-main-bottom.png

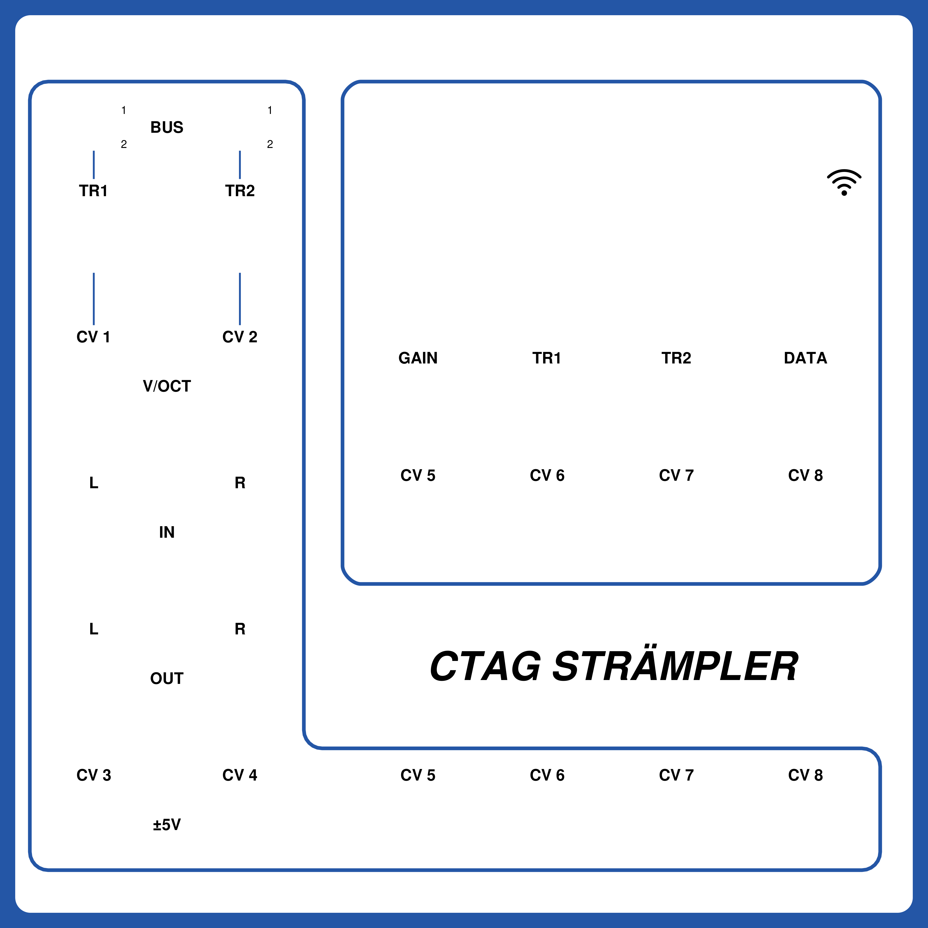
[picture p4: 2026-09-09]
panel-emu/emu_panel_art.png

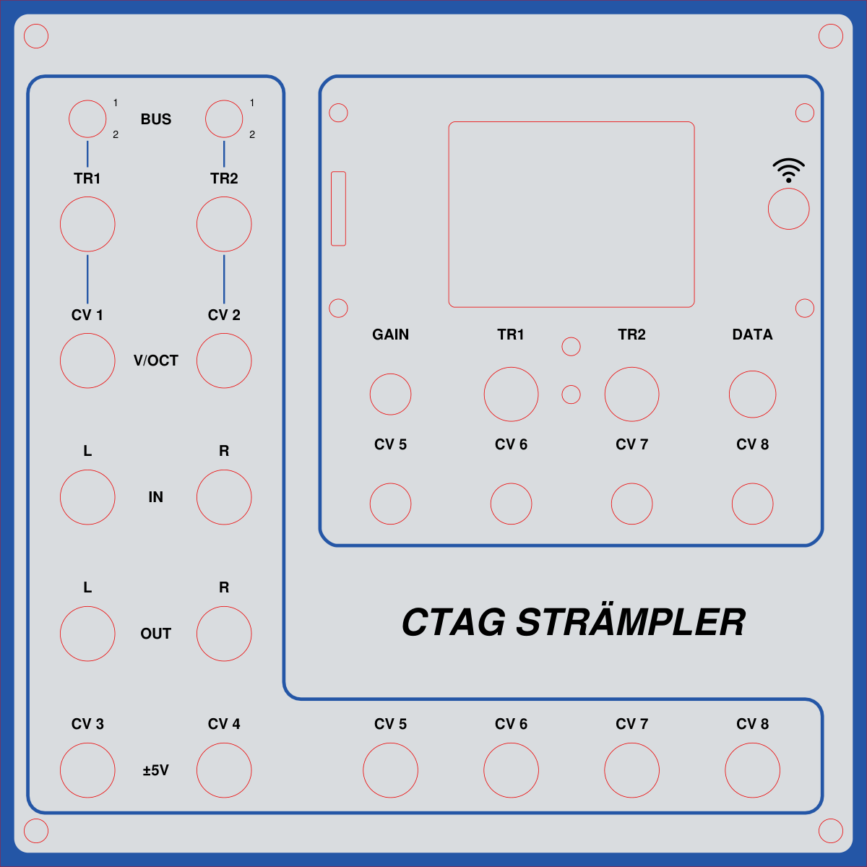
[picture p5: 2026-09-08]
panel-emu/emu_panel.png

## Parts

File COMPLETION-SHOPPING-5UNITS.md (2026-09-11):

# Completion shopping list — 5 units

## ✅ BOTH ORDERS PLACED 2026-07-26

- **AliExpress — 11 lines, $186.02** (jacks, pots, dual-gang, encoders,
  TFTs, antennas + stubs, knobs, encoder caps, standoffs, screws)
- **Mouser — 6 lines, $57.04** (SD holders, tact switches, micro-USB,
  LED, power header, screen connector) — single shipment, all ship-now

Total ≈ **$243** — that's the two module-parts orders. Power cables and
SD cards are still outstanding (see below); neither appears in any BOM.

**Power cables: ORDERED** (ExcelValley 5-pack, 10→16 pin, Amazon).
**SD cards: NOT ordered** — deliberately deferred to nearer final
assembly. Neither item appears in any BOM. Card spec + purchasing notes
below; **brand matters far less than FAT32 and the seller** — Lexar at
~40% under SanDisk is a sound buy for this duty cycle.

## ✅ FIRST MODULE BUILT — 2026-08-28 (soldering lab)

**Result: PASS — boots and makes sound.** Unit #1 of 5, PCBWay-assembled main
board + hand-soldered through-hole. Remaining adjustments are cosmetic /
ergonomic; the electrical build is proven.

What happened, for units 2–5:
- **Flashed from a bare Mac** (no ESP-IDF): `pip install esptool` in a venv,
  micro-USB to the on-board CP2102 (`/dev/cu.usbserial-*`), module on
  **rack +12 V** (USB VBUS does not power the board), then
  `bin/keys-multisample-v1/flash.sh` offsets with `--flash_size detect`
  (chip is 8 MB). Boot log: PSRAM 64 Mbit OK, display init, I2S up, WiFi up.
  Procedure is in the firmware repo `HANDOFF.md` (2026-08-29 entry).
- **White screen on first power-up** — panel got no init. Fixed by
  **reseating the TFT in the Hirose P3 receptacle**; root cause not
  isolated (seating vs. a marginal header pin). Check the 9-pin header is
  fully home before suspecting anything else. Orientation was correct
  (backlight on = VCC/GND/LED right).
- **Jacks**: Ali lot fits, nuts included (audit rows 4).
- **POT1 (GAIN) not fitted** — Ali sent the wrong part; Mouser substitute
  carted (see POT1 section). Audio **input** path is untested until it's in;
  output verified by ear.
- **Panel**: LED light window is copper on this run (see Panel defect
  section) — module works, LED just doesn't show through. Re-fab pending.
- **SJ1 (bottom, IO19↔TFT SDO)** is open, as on the test unit. Not needed
  for operation; bridge it if TFT readback is wanted (firmware `/tftread`).
- No SD card was in for the first boot — firmware tolerates that (logs
  `Failed to initialize the card (263)`, continues). A blank FAT32 card
  self-populates on first boot.

## Power cables & SD cards — sourcing notes (for reorders / kit runs)

### Eurorack power cable, 10-pin (module P4) → 16-pin (bus board)
**Leading pick (in Amazon cart, not yet ordered): [ExcelValley 5-pack,
10→16 pin, 25 cm](https://www.amazon.com/ExcelValley-5-Pack-Eurorack-Modular-Synthesizer/dp/B07N8H544N)**.

Alternatives, cheapest-per-cable last:
| Source | Detail |
|---|---|
| [Arcus Audio](https://arcusaudio.com/product/10-pack-10-eurorack-power-cable-10pin-16pin-with-strain-relief-connectors/) | **10-pack**, 10″, 28AWG, strain relief. US. Best pre-made bulk. |
| [Etsy custom](https://www.etsy.com/listing/477371413/eurorack-power-cable-ribbon-cable-10) | packs of 3/5/10/15/20, choose length, bulk discounts |
| [AI Synthesis](https://aisynthesis.com/product/eurorack-power-cable/) | $5.00 ea, 254 mm, "5+ bulk discount" |
| [Thonk](https://www.thonk.co.uk/shop/eurorack-power-cables/) | £1.66 (15 cm) — cheapest each, but UK→US shipping. Bulk quotes >500. |
| **DIY** | **~$0.50/cable** in parts (ribbon ~$0.50/m, 16-pin IDC ~$0.10, 10-pin ~$0.20) + a **$15–40 IDC crimp tool**. Pays back around **30–50 cables** — i.e. only if kits happen, not for one build. [refs](https://modwiggler.com/forum/viewtopic.php?t=78071) |

⚠️ Red stripe → **-12V**. Our P4 is a shrouded keyed header so a keyed
cable can't reverse; only matters if you ever buy unkeyed.

### microSD card — SPEC (verified against firmware 2026-07-26)

Source of truth: `components/drivers/storage.c` + `sdkconfig.defaults` in
the firmware repo.

| Spec | Requirement | Why |
|---|---|---|
| **Filesystem** | **FAT32 — mandatory** | `CONFIG_FATFS_LFN_NONE=y` and **no exFAT option is enabled**, so FatFS can mount FAT12/16/32 only. An exFAT card will simply fail to mount. |
| **Pre-formatted** | **Yes — the firmware will NOT format it** | `format_if_mount_failed = false`. A blank/exFAT card gives "Failed to mount filesystem", not a rescue. |
| **Capacity** | **32 GB recommended. No hard maximum.** | FAT32 is the only real constraint — *not* capacity. 4–32 GB (SDHC) is FAT32 out of the packet; 64 GB+ (SDXC) ships exFAT and must be reformatted, which is fine if you don't mind doing it. See the note below on why bigger still isn't better. |
| **Filenames** | **8.3 only** | LFN is compiled out. This is *why* every sample id in the system is ≤8 chars. |
| **Max file size** | FAT32 ceiling is 4 GB; repo documents **≤2 GB** | Moot in practice — samples are megabytes. |
| **Speed class** | **Any Class 10 / UHS-I** | Bus is **1-bit SDMMC** at `SDMMC_FREQ_HIGHSPEED`; the audio path needs ~**176 KB/s**. Even 1-bit mode has enormous headroom. Paying for V30/A2 buys nothing. |
| **Contents** | `CONFIG.JSN` from the repo, before first boot | |

**Is there a max size?** No hard limit in the firmware, and none in FAT32
at any capacity you can buy (its ceiling is ~2 TB at these cluster sizes).
A 64/128/256 GB card reformatted to FAT32 should mount fine.

**But bigger is still not better here, for two concrete reasons:**
1. **Nothing above 32 GB has been tested on this hardware.** The only
   proven configuration is what's in the test unit.
2. **Directory walks are a known performance hazard in this firmware.**
   Bench-caught previously: per-index stat probing with a missing
   extension walks the entire FAT directory per call and starved the
   capture queue — *1804 dropped chunks*. Browsers already cap at
   224/512 entries. A bigger volume invites a bigger pool, and the cost
   lands on the audio path, not on idle time.

And there's nothing to gain: 32 GB ≈ **50 hours** of 44.1 k stereo audio.

### microSD card — purchasing
**Not yet ordered.** Lexar sits in an Amazon cart; **B&H is the better
buy** — see the supplier note at the end of this section.

**BUY 32 GB, and the reason is the SD spec, not preference:** 4–32 GB is
**SDHC, which the SD Association defines as FAT32** — exactly what the
firmware wants, straight out of the packet. **64 GB and up is SDXC =
exFAT**, so every card needs reformatting first, and Windows won't make a
FAT32 volume >32 GB without a third-party tool (guiformat / SD Card
Formatter / `mkfs.vfat`). Hold this even if 64 GB is a dollar cheaper.

Everything else is irrelevant here: the machine streams ~**176 KB/s**, so
Class 10 / UHS-I is already ~50× more than it can use — don't pay for
V30/A2. 32 GB ≈ 50 hours of 44.1 k stereo audio.

Brand barely matters at this duty cycle (gentle, read-mostly, rarely
reinserted). **Counterfeits are the only real risk** and they're
brand-independent — buy from a real retailer, not a marketplace
"mixed-brand tested lot". Lexar is legitimate (Micron sold it to Longsys
in 2017); photography forums report more early failures than SanDisk, but
that's sustained-burst camera use, not this. SanDisk Ultra 32 GB
`SDSQUA4-032G-GN6MA` is the belt-and-braces pick if reordering.

### Where to buy cards — B&H, and the reason is counterfeits
**[B&H Photo](https://www.bhphotovideo.com/)** (or [Adorama](https://www.adorama.com/)) — **authorized dealers** buying
direct from the manufacturer, so a counterfeit has no path into their
stock. SanDisk reckons [~1/3 of memory cards on the market are fake](https://www.pocket-lint.com/beware-of-fake-sd-cards/).

⚠️ **"Sold by Amazon" is NOT the safeguard it looks like** — Amazon
**commingles inventory** across every seller of an ASIN, so a third-party
counterfeit [can reach you even buying direct from Amazon](https://www.dpreview.com/forums/threads/buying-sd-cards-from-amazon.4468446/).

⚠️ **Skip "bulk memory card" sites** — checked
[bulkmemorycards.com](https://bulkmemorycards.com/product-category/microsd-cards/microsd-32gb/):
SanDisk Ultra 32 GB runs **$12.65–$15.50**, *above* normal retail, and the
bulk tiers shave only a few percent. No wholesale advantage at our volume.

**Setup:** copy `CONFIG.JSN` from the repo onto each card before first
boot. **If the cards are 64 GB+, reformat to FAT32 first.**

**Test every card on arrival, whatever the source.** A fake reports full
capacity but has less real flash and fails *silently* — you'd discover it
as corrupted samples months in. On macOS:
`brew install f3` then `f3write /Volumes/CARD && f3read /Volumes/CARD`.
~10 min per card, before you commit a library to them.

**⚠️ ON ARRIVAL — do this before soldering the run:** test-fit ONE
Thonkiconn jack and ONE RD902F dual-gang pot on a bare board with
calipers. Those are the only two lines whose footprint could not be
fully proven from listing photos. Both listings carry 90-day free
returns.

## COMPLETENESS AUDIT 2026-07-25 — every part accounted for

Method: kit BOM + `parts-NOT-from-mouser.csv` minus what PCBWay built.

| # | Part | Desig. | Per unit | Source | Status |
|---|---|---|---|---|---|
| 1 | Main PCB + panel | — | 1+1 | PCBWay | ✅ main ×5 OK · ❌ **panels ×5 DEFECTIVE** — LED light window is copper instead of bare FR4 (conversion bug, fixed 2026-08-28; see [Panel defect](#panel-defect--led-light-window-is-copper-2026-08-28)). Re-fab from the regenerated `gerbers-panel-*.zip`. |
| 2 | All SMD passives & ICs | many | — | PCBWay | ✅ assembled |
| 3 | WM8731 codec | IC4 | 1 | PCBWay | ✅ **populated** (not DNP — see below) |
| 4 | Thonkiconn jacks | J1–J14 | 14 | Ali | ✅ 200-pc lot — **received 2026-08-28, knurled nuts included** (confirmed in the bag; no separate nut order needed). **Test-fit on board OK 2026-08-28** — footprint matches. |
| 5 | B10k pots | POT2–5 | 4 | ~~Ali~~ → **Mouser** | ⬆ **UPGRADED 2026-08-29**: Same Sky PTN091-V10115K1B ×25 ordered (metal shaft, M7 bushing — see [POT2–5 section](#pot25-cv-pots--upgrade-to-metal-shaft--threaded-bushing-2026-08-29)); ✅ panel v2_3 has 7.2 mm holes (order re-fab from the v2_3 zip). Ali RV09 ×20 on hand = fallback for 9.2 mm panels. |
| 6 | B100k dual-gang | POT1 | 1 | ~~Ali~~ → **Mouser** | ❌ **WRONG PART received** (right-angle, mono) → reorder, see [POT1 section](#pot1-dual-gang-gain-pot--wrong-part-substitute-2026-08-28) |
| 7 | Encoder | SW1 | 1 | Ali | ✅ 6 |
| 8 | 2.2" ILI9341 TFT | P3 | 1 | Ali | ✅ 6 |
| 9 | Antenna + u.FL pigtail | — | 1 | Ali | ✅ 5 sets + stubs |
| 10 | Knobs, pots (Davies set-screw) | POT1–5 | **5** | Ali | ✅ 30 (25 needed → +5 spare) |
| 10b | **Encoder cap** (separate, see below) | SW1 | 1 | Ali | ✅ 40 |
| 11 | M3×10 F-F standoffs | — | 5 | Ali | ✅ 60 |
| 12 | M3×6 screws | — | 10 | Ali | ✅ 50 |
| 13 | Yamaichi microSD holder | P1 | 1 | Mouser | ✅ 6 |
| 14 | D6R tactile switches | SW2, SW3 | 2 | Mouser | ✅ 12 |
| 15 | Molex micro-USB | P2 | 1 | Mouser | ✅ 6 |
| 16 | 5mm red LED | L1 | 1 | Mouser | ✅ 10 |
| 17 | 2×5 shrouded power header | P4 | 1 | Mouser | ✅ 10 |
| 18 | Hirose screen connector | (TFT) | 1 | Mouser | ✅ 6 — **nearly missed** |
| 19 | Eurorack power cable | — | 1 | **Arlo sources separately** | ⬜ |
| 20 | microSD card (FAT32, ≤2 GB files) | — | 1 | **user-supplied, in no BOM** | ⬜ |

⚠️ **Knob count**: 5 pots (POT1 dual + POT2–5) **plus** the encoder = **6
shafts per unit**. The doc's old "25 needed" line undercounted by missing
the encoder.

**Resolved 2026-07-25 by giving the encoder its own cap** (Arlo's call).

> **Changing the look later?** `KNOB-OPTIONS-20260911.md` screens the Thonk
> and AliExpress ranges against the panel's real geometry — the binding limit
> is the **19.27 mm row-to-row gap**, not the 21.22 mm side pitch.
So the 30 Davies set-screw knobs now cover only the 25 pot positions,
which conveniently restores a +5 spare margin on that line.

### Encoder cap (SW1) — separate part, deliberately distinct
**AliExpress "10PCS For KY-040 … ABS D Half Shaft Hole Caps Knob 6mm"**,
item 3256806101256136, $1.60/10, 4.9★/370 sold. **4 lots = 40 caps
$6.40** (4 was the seller's entire remaining stock — the + control greys
out there).

Why a different cap, not another Davies:
- **The EC12 encoder shaft is a D-shaft** (verified from the listing
  photo — smooth with a flat, NOT knurled). These caps are a true
  **D-bore**, so they key to the flat and need no set screw.
- **No indicator line.** A pointer is meaningless on an encoder — it has
  no absolute position, so a Davies pointer would spin and point at
  nothing. Arlo's requirement, and it's the functionally correct choice.
- **Hard ABS, not soft-touch** (Arlo: "not soft touch eew").
- Flat top suits the encoder's **push switch**; smaller diameter than the
  ~18 mm Davies makes DATA findable by feel among six knobs.

Rejected along the way: aluminum (Arlo wants plastic); WISINVI 10.5×17 mm
and KAIHCHIP 11×13.5 mm D-bore plastics (both have indicator lines); the
WISINVI 10×12 mm knurled aluminum (**"Flower Shaft"** = splined bore,
would wobble on a D-shaft).

Everything else on this page is background/history.

---

## Panel defect — LED light window is copper (2026-08-28)

Found at first-module assembly: the wavy line between TR1/TR2 that lines
up with the LED (L1) is a **copper trace** on the fabbed panels. On the
original Antumbra panel it is a **gap in the solder mask over bare FR4**
so the LED shines through the board.

**Cause:** the Eagle→KiCad conversion parked the Eagle `tRestrict`/
`bRestrict` copper keep-outs on KiCad's non-copper `User.1` layer, so the
mask window was plotted correctly but the copper pours filled underneath
it. Details in `hardware-kicad/README.md` (pitfall 2).

**Fix (committed):** keep-outs merged into one F.Cu+B.Cu rule area,
zones refilled, `gerbers/gerbers-panel-strampler_panel_v2_2.zip`
regenerated and verified (copper ∩ window = 0 on both layers).

**✅ ARRIVED 2026-09-07 (JLCPCB v2_3 run):** LED light window is correct —
no copper in front of L1, the fix is confirmed on real boards. HASL instead
of ENIG made the run much cheaper and, as predicted, changes nothing (no
exposed copper on the panel). Mask-shade verdict vs PCBWay/Pusherman still
to be recorded.

**Action: ✅ ORDERED 2026-08-30 — at JLCPCB, not PCBWay** (5× panels from
`gerbers-panel-strampler_panel_v2_3.zip`, ~$19 shipped: $9.70 boards +
$9.08 Global Standard Direct Line, 8–13 business days). This is a
**solder-mask shade trial**: the PCBWay run was confirmed matte black but
reads lighter than the Pusherman reference; JLCPCB's current "Black" is a
proprietary semi-matte hybrid (they discontinued pure matte black as
scratch-prone), so it may land between. Spec: 1.6 mm, black mask, white
silk, HASL (finish is invisible — no exposed copper anywhere on the
panel), no order-number mark (JLC's free default). **On arrival: compare
shade vs the PCBWay matte panels and the Pusherman panel — the winner
prints the production run; Pusherman remains the known-good fallback for
the exact reference look.** The 5 defective panels are
usable only as-is with no LED show-through (or scrape the copper off the
window by hand — it's exposed, ~8 mm², both sides).

---

## POT1 dual-gang (GAIN pot) — WRONG PART, substitute (2026-08-28)

**The Ali "RD902F-B100K" lot (order 2026-07-25, #3) delivered a
right-angle MONO pot.** Caught at first-module assembly. The listing's
pin rows were never photo-confirmed (noted at the time) — that was the gap.

**What the board needs** (`POT_DUAL_THONK`, verified against KiCad + the
Alpha RD902F-40 factory drawing): 9 mm **vertical** (shaft ⟂ board),
**2 gangs**, two rows of 3 pins, **2.5 mm pin pitch**, rows at **7.5 and
10.0 mm** from the mount line, 6 mm shaft, M7 bushing.

⚠️ **Correction to the footprint note below:** the board's two Ø2.2 mm
holes at ±4.4 mm are **not** an Alpha feature. Alpha's own drawings (dual
RD902F-40 *and* single RD901F-40) show flat anti-rotation tabs ~11.3 mm
apart. No 9 mm pot's tabs land in those holes — **clip the tabs and let
the panel nut hold the pot.** Same for POT2–5. Select pots by pin grid
only; ignore the mount holes.

### Mouser substitute — ORDER THIS

| Mouser # | MPN | Mfr | Price | Stock (08-28) |
|---|---|---|---|---|
| **179-PTN092V100115K1A** | PTN092-V100115K1A | Same Sky (ex-CUI) | $2.45 / $1.97 @10 | 135 |

9.5 mm vertical, 2-gang, 100 kΩ, 15 mm 6 mm **knurled T18** shaft (fits
the Davies set-screw knobs), M7×0.75. PCB layout is pin-for-pin the Alpha
RD902F pattern (2.5 mm grid, rows 7.5/10). Tabs at 11.5 mm → clip.
Need 5 → **order 8** (spares).

**Caveat — taper is A (log), not B (linear).** Mouser and Digi-Key have
no stock of the linear `PTN092-V100115K1B`. Acceptable: the schematic
wires POT1 as a rheostat (wiper tied to one end, in series with R8/R9
into the codec input), so taper only changes knob feel, and log is the
natural feel for a gain control. If linear is a must, buy the exact part
from Thonk instead: **Alpha 9mm Vertical T18 Dual Gang, B100K**
(RD902F-40-15R1-B100K), £1.99 ex-VAT —
https://www.thonk.co.uk/shop/alpha-9mm-pots-vert-t18-dual-gang/

### Ruled out on Mouser (don't re-check)
- **Bourns PTD902-xxxx-B104** (linear, well stocked, looks perfect): pin
  pitch is **5.0 mm** within each row. Does not fit.
- **Alps RK09L** dual 100k linear: only the *horizontal* variant stocked;
  snap-in type anyway. RK09K / RK097 / Bourns PTV09: single-gang only.
- **Alpha (Taiwan)** on Mouser carries no RD90x at all.

Sources: Bourns PTD90 datasheet · Same Sky PTN09X datasheet (2024-09-12) ·
Alpha RD902F-40 / RD901F-40 drawings hosted by Thonk.

---

## Bench results 2026-09-04 — Mouser pots arrived, SJ1 bridged, input path PASSES

**Mouser order received.** Findings on the first module (the .85 unit):

- **POT1 (PTN092 dual-gang) FITTED and WORKING.** Two adjustments:
  (1) body sits tall in the bottom box — **file off the anti-rotation tab**
  on the bushing face (soft zinc; keep filings out of the pot, shaft down);
  (2) assembly order: **install jacks+pots LOOSE, fit panel, snug nuts,
  THEN solder** — the panel jigs every bushing to true height, so exact
  body height stops mattering. Both belong in KIT-GUIDE for units 2–5.
  Panel v2_4 candidate: add the anti-rotation locating holes (hidden under
  the nuts) so no filing is needed.
- **Audio INPUT path VERIFIED** (was the last untested electrical path):
  signal in, `vu[0]/vu[1]` swept ~1→253 (full range) with the gain pot,
  L/R matched within a count or two the whole sweep (both gangs alive and
  balanced). Ear-level listen still owed (line-in tuner or Tape monitor).
- **SJ1 BRIDGED on this unit → GRAM readback WORKS.** `/tftread`: pixel
  test 4/4 bit-exact at a 10 MHz read clock. **`id_ok` is false and always
  will be on this panel lot** (clone controller ignores 0xD3; RDDID
  nonstandard too) — **the QA criterion for units 2–5 is `pixel_ok`, not
  the overall verdict** (it reads "PARTIAL" because of the ID). Unit 1's
  SJ1 remains open (by choice).
- **PTN091 single-gang (POT2–5): NOT YET TESTED** — look like they fit,
  none installed yet (current panels have 9.2 mm CV holes; the M7 bushing
  wants the v2_3 panels in fab). First install = first test; expect the
  same anti-rotation tab to file unless the tab-hole lands in v2_4.

## POT2–5 CV pots — upgrade to metal shaft + threaded bushing (2026-08-29)

The Ali RV09 clones (row 5) work electrically but feel cheap: plastic
shaft, no bushing, nothing fixing them to the panel (unlike the encoder's
M7 nut). **ORDERED 2026-08-29: Same Sky PTN091-V10115K1B ×25, Mouser
179-PTN091V10115K1B, $1.32 @ 25 = $33 (shipping paid, under the $60
free-ship line).** Need 20 (4 × 5 units) + 5 spares.

Why this part:
- Single-gang sibling of the POT1 sub (PTN092-V100115K1A) — same family,
  same bushing/shaft geometry across the panel, one vendor.
- **Aluminum knurled 18T + slotted shaft** (datasheet materials table),
  15 mm — matches the original Alpha length, existing Davies knobs fit.
- **M7×0.75 zinc threaded bushing + nut** — panel-mounts like the encoder.
  Note: 15 mm shaft carries the 5 mm bushing (7 mm only on 20/25 mm
  shafts) — fine through the 1.6 mm panel, same as the POT1 sub.
- 10 kΩ linear, standard 2.5 mm 3-pin row; clip the mount tabs, panel nut
  holds it (same rule as POT1). Test-fit on arrival as usual.

**✅ PANEL CHANGE DONE 2026-08-29 — panel v2_3.** New
`hardware-kicad/strampler_panel_v2_3.kicad_pcb` (v2_2 kept unchanged as
the pre-M7 version): the four CV pot holes 9.2 → **7.2 mm**, and POT1's
hole 8.2 → **7.2 mm** (hole identification by position match against the
main board: POT1 = the POT_MEDIUM at panel (13.903, −65.096); the OTHER
8.2 at (77.544, −65.096) is the ENCODER — untouched, current encoders
thread it fine; the 2× 9.5 are SW2/SW3). Zones refilled, gerbers
regenerated + verified: drill table has no 9.2 left (7.2 ×6, 8.2 ×1),
edge/silk byte-identical to v2_2, mask differs by exactly the 5 resized
openings, copper diff = zone refill only, LED window still copper-free.
**Order the 5 panels from `gerbers/gerbers-panel-strampler_panel_v2_3.zip`.**
The Ali RV09s (20 on hand) remain the fallback for the 5 defective 9.2 mm
panels if they're ever scraped-and-used.

---

## Pending small hardware (2026-08-31) — display firming + hex jack nuts

### Display corner standoffs (firm up the TFT)
The MSP2202 module hangs off only the Hirose header — the known
white-screen/seating weak point. Main board + module both have 4 corner
mount holes (main board drill 3.1 mm plated ≈3.0 finished; 61.2×34.1 mm
rectangle). The unused card-slot can on the module's back sets a floor on
the gap of a couple of mm. **MEASURE FIRST at a corner hole on the working
unit (calipers or drill-shank gauge), then pick ONE:**
- **M3 nylon hex standoff F-F × <measured>** + M3×6 nylon screws both ends
  — fits our 3.0 mm holes for certain. Qty 30 standoffs + 60 screws
  (6 units incl. retrofit of unit 1 + spares). Ali parametric listing:
  aliexpress.com/item/32996308968.html (pick M3 + length).
- **Dual-lock snap support, 3.2 mm hole class** (barbed both ends,
  tool-free; RS 030-4195 shows the geometry; Ali: search "dual lock PCB
  support 3.2mm") — nicer assembly but our plated 3.0 mm bore is ~0.2 mm
  under nominal; barbs may seat snug or may refuse. Heights come in coarse
  steps (6.4/7.9/9.5) and can't be shimmed. Try-it item; ~$2/100.
  (The common Ali "RC" snap series is 4.0 mm-hole — does NOT fit.)
Both together cost ~$4 — ordering one lot of each and letting the bench
decide is legitimate.

### Non-knurled hex nuts for the jacks (J1–J14)
Arlo wants hex instead of the knurled nuts that shipped with the jack lot;
**silver confirmed** (Bananuts/black ruled out 2026-09-01).
**Thread is M6 × 0.5 (extra-fine)** — standard M6×1.0 and fine M6×0.75 DO
NOT fit; it must be a jack-specific 8mm-across-flats nut (generic DIN439
M6×0.5 exists on Ali but is 10mm AF — barely clears the 12.7mm jack grid,
ruled out on looks/wrenchability).
**DECIDED: Qingpu factory hex nut — SKU WQP-HN (NB: WQP-KN is the KNURLED one!), qty 200, $0.10 ea at Danesi = $20** — matches the full
200-jack stock (84 fitted across 6 units incl. unit 1 retrofit; the rest
keeps every spare jack buildable in the house style, saves a second
shipping later). Source: Danesi Designs (Scott Danesi, Chicago —
danesidesigns.com/products/wqp-kn-qingpu-hexjack-nut-m6-x-0-5mm),
~$0.15–0.25 ea; equal fallback: Amplified Parts / CE Distribution
(same Qingpu part). The Ali jack seller (NingSheng) does NOT carry nuts
(checked 2026-09-01).

## Board rev candidates — HYPOTHETICAL ONLY (no respin planned)

Collected "if we ever respin" ideas. **The 5 assembled main boards in hand
are fine; nothing here is a commitment or a schedule.** A respin has fixed
costs (fab + assembly setup + re-validation), so it should batch everything
below — do not spend one of these ideas alone.

### Main board
- **USB-C replaces micro-B** for the CP2102 flash/serial port. 12-pin
  USB-2.0-only receptacle (TYPE-C-31-M-12 class, ~$0.10), two 5.1 kΩ
  pull-downs on CC, D+/D− unchanged. While in there: check whether the
  CP2102 runs from VBUS or 3.3 V — bus-powering the bridge would allow
  flashing with no rack power (nicer kit-assembly workflow; today rack
  +12 V is required). Assembly note: the current micro-B (Molex
  105017-0001, P2) is a HYBRID footprint — SMD signal pads + 4 TH shield
  legs — which is why PCBWay's reflow-only job skipped it. USB-C offers
  the same choice: hybrid-with-TH-stakes (strong, stays a hand-solder
  step) vs pure-SMD (reflowable at PCBWay, mechanically weaker). For an
  occasional programming port the anchored hybrid is in character.
- **Display mounting holes 3.1 → 4.0 mm** (and unplated) to accept
  dual-lock snap-in PCB supports (RC-style, tool-free) instead of M3
  hardware. Note the TFT module's own ~3 mm corner holes remain the other
  half of the problem — only helps if the module side is solved too.
- **SJ1**: optionally replace with a wired-through trace (bridge is now
  the standard build step anyway; original CTAG wired MISO permanently).
  Or keep the jumper — costs nothing and preserves the isolation option.
- Already fixed in KiCad but absent from the 2026-07 fabbed boards
  (any refab inherits them automatically): SJ1 mask sliver, main-board
  keep-out audit results.

### Kit-ready assembly (process change, not a layout change)
If boards are ever built for OTHER people, add the machine-doable TH parts
to the PCBWay job: micro-USB, SD holder, 2× tact switches, power header,
display socket — ~50 joints/board, est. **$15–40 extra** on the run (2026-07
reference: assembly was only $29.00 of the $370.65 / 5-board order) plus
sourcing markup or consignment handling. Shrinks the kit builder's work to
purely the panel sandwich (jacks/pots/encoder/LED — which MUST stay hand
work for the panel-jig solder order). Not worth it for self-built units:
those six parts are ~10 min in the same soldering session.

### Panel
- Anti-rotation locating holes for the pots were considered and DROPPED
  (2026-09-05): filing the PTN09X tab worked out fine on unit 2, so the
  file-the-tab step stays in the assembly order. v2_3 remains the panel.

# Original list — AliExpress-first (no Thonk)

For the 5 PCBWay-assembled boards (ordered 2026-07-17, all SMD done, codec
populated). Everything below is through-hole / bolt-on. Quantities include
spares. Footprint data verified against the KiCad board
(`hardware-kicad/project/Strampler_redesign_v2_2.kicad_pcb`).

## AliExpress cart

| Part | Need | Order | Notes |
|---|---|---|---|
| **WQP-PJ398SM jack** (J1–J14) | 70 | 80 | Qingpu's own AliExpress storefront, ~$0.25–0.35 ea. Listing MUST say PJ398SM / WQP-PJ398SM with clear photos — the PJ301M-12 lookalike has a different footprint and will not fit. |
| **B10k pot, Alpha 9mm vertical** (POT2–5) | 20 | 24 | RD901F style / "RV09" clones. 6mm knurled T18 shaft (match knobs). |
| **B100k DUAL-gang pot, 9mm vertical** (POT1) | 5 | 8 | ⚠️ Footprint check: two 3-pin rows, 2.5mm pin pitch, rows 2.5mm apart. Standard Alpha RD902F dual pattern — compare listing photo before buying. **Ali lot delivered a right-angle mono pot — superseded by Mouser 179-PTN092V100115K1A, see POT1 section above.** (The "mount legs at ±4.4mm" claim was wrong: Alpha tabs are ~11.3mm apart and get clipped.) |
| **EC12E rotary encoder w/ push switch** (SW1) | 5 | 8 | Footprint `ALPS_EC12E_SW`: A/B/C at 2.5mm pitch one side, D/E switch pins opposite (5mm apart), tabs at ±6.1mm — standard EC12. Pick shaft (knurled T18 or D) to match your knob choice + panel clearance. |
| **2.2" 240×320 SPI TFT, ILI9341** (P3, MSP2202) | 5 | 6 | Original link: aliexpress.com/item/32607741715.html — MSP2202 module, footprint verified on board. |
| **IPEX/u.FL WiFi antenna** | 5 | 8 | Original link: aliexpress.com/item/4001275208954.html. Cheap — spares. |
| **microSD breakout** (P1) | 5 | 6+ | ⚠️ THE risky one — see section below before ordering. |
| **Knobs** | 25 | 30 | For 6mm knurled T18 shafts (4 pots + encoder per unit; dual-gang = 1 knob). Davies 1900h clones etc. |
| **M3 10mm F-F standoffs** | 25 | 30 | Assortment kits fine. |
| **M3 6mm screws** | 50 | 60 | |
| **Eurorack power cables 10-pin→16-pin** | 5 | 5 | Not in any BOM — don't forget. |

Rough Ali total: **$110–140** for all five units.
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

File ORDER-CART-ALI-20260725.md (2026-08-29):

# AliExpress cart — verified listings, 2026-07-25 session

Companion to `COMPLETION-SHOPPING-5UNITS.md`. Every listing below was opened
and photo/SKU-checked in-browser this session (Claude + Arlo). Prices are the
**signed-out "welcome deal"** numbers — expect the regular price after login
(regular shown in parens where seen). Welcome deals also carry "max 1 per
shopper" caps that may lift or vanish once signed in.

**Outcome vs the plan: everything sourced on Ali except the Eurorack power
cables. No Thonk order needed** — the SD sniffer and the dual-gang pot (the
two flagged risks) both found verified listings.

## The cart

| # | Part | Listing | SKU to pick | Qty | ~Price |
|---|---|---|---|---|---|
| 1 | Jacks (Thonkiconn/PJ-301M, mono + knurled nuts) | aliexpress.us/item/2251832766984352.html (Shenzhen NingSheng, 5.0★/60 sold) | 200-pc lot | **1 lot = 200 pcs** | $39.83 ($42.25) |
| 2 | B10k pots, RV09 vertical, knurled 18mm shaft | aliexpress.us/item/3256806764561680.html (Jinboli, 4.9★/137 sold) | **B10K B103** | **3 lots × 10 = 30** | $2.39/lot ($2.93) |
| 3 | Dual-gang B100k, Taiwan Alpha RD902F | aliexpress.us/item/3256811723023981.html (Franchise Switch, 5★/417 sold) | RD902F-B100K, D-shaft 15mm | **2 lots × 5 = 10** | $18.50/lot |
| 4 | EC12 encoder w/ push switch, 24 det | aliexpress.us/item/3256807315397735.html (Tongxuan, 4.8★/323 sold) | **20mm** (knurled) | **4 lots × 2 = 8** | $0.99/lot ($2.68) |
| 5 | 2.2" ILI9341 TFT (MSP2202) — ORIGINAL BOM link, still alive | aliexpress.us/item/2251832421426963.html (EQV Official, 5★) | — | **6** | $5.99 + $4.80 ship |
| 6 | 2.4GHz antenna + u.FL pigtail set | aliexpress.us/item/3256807801327960.html (XYANT, 4.9★/900+ sold) | **"SMA Male to IPEX1"** (antenna+pigtail set) | **4 lots × 2 = 8** | $0.99/lot ($2.58) |
| 7 | microSD sniffer breakout (SparkFun clone) | aliexpress.us/item/3256809057269319.html (Great IT, 4.9★/600+ sold) | **10PCS** pack | **1 × 10** | ~$2/10 welcome ($4.92/5 reg) |
| 8 | Knobs, Davies 1900h clone, SET SCREW | aliexpress.com/item/1005006890019684.html (DAIERBUMP, 4.8★/600+ sold) | 6mm bore | **3 lots × 10 = 30** | $1.33/lot ($14.26?) |
| 9 | M3 10mm F-F standoffs ×30 + M3 6mm screws ×60 | any assortment kit — search "M3 brass standoff kit" | — | 1 kit | ~$5-8 |

Rough total: **$85–110** signed-in, well under the doc's $110–140 estimate.

## Verification notes (what was actually checked)

- **Jacks (#1):** photos show the WQP mono profile — box body, threaded
  collar, knurled nuts included, 2 signal pins + wide ground tab. Thonk's own
  page confirms PJ301M-12 / PJ398SM / WQP518MA are all interchangeable
  Thonkiconns (tab material differs only). $0.20/pc vs Thonk £0.38.
  Residual risk: photos can't prove sub-mm footprint; 200-lot leaves margin.
- **Dual pot (#3):** exact Alpha MPN **RD902F-B100K** in title, green Taiwan
  Alpha body "0B100K" visible. Gallery's other shots are recycled stock
  photos — pin rows NOT visually confirmed; MPN + genuine-Alpha look is the
  evidence. D-shaft ("half-axle") → use set-screw knobs (#8 covers this).
  **❌ 2026-08-28: RECEIVED WRONG PART — right-angle MONO pot.** The
  unconfirmed pin rows were exactly the failure. Replaced by Mouser
  179-PTN092V100115K1A; see `COMPLETION-SHOPPING-5UNITS.md` → POT1 section.
- **Encoder (#4):** 5 pins + push, EC12 = ALPS EC12E pattern; a review
  confirms correct quadrature phasing. 20mm SKU photo = knurled shaft.
- **SD sniffer (#7):** zoomed photo shows the 8 **staggered** card-edge
  fingers + DAT/CLK/CMD/CD labels = SparkFun sniffer clone geometry the
  KiCad footprint expects (1.1mm pitch stagger). The doc's ⚠️ item — PASSED.
- **B10k pots (#2):** 18mm shaft vs Alpha 15mm — knobs sit ~3mm prouder,
  cosmetic only. Pin/mount layout is standard RV09 vertical.
- **Antenna (#6):** set = folded rod (SMA male) + u.FL(IPEX-1)→SMA-female
  bulkhead pigtail 15cm. Plugs into the WROVER-IE's u.FL; rod can
  panel/case-mount on the bulkhead.

## NOT on AliExpress

- **Eurorack power cables 10-pin→16-pin ×5** — two searches found nothing
  eurorack-specific. Get from Thonk/Tayda/Amazon, or existing case spares,
  or DIY (2×5 + 2×8 IDC + ribbon).

## Unchanged from the main doc

- **LCSC add-on** still as written in `COMPLETION-SHOPPING-5UNITS.md`:
  D6R00F1LFS tacts ×12, Molex 105017-0001 USB-B ×6, 5mm red LED ×10,
  2×5 shrouded header ×10, WM8731SEDS/RV spares ×2-3.
- WM8731 main stock: already populated on the PCBWay boards.

## CART SIGNED OFF 2026-07-25 — est. $197.95, awaiting Arlo's checkout click

Arlo accepted the jack-lot risk explicitly; duals bumped back to 2 lots
(10 pcs) as the one insurance line. Claude: comfortable with every line as
carted. On arrival: test-fit ONE jack + ONE dual on a bare board with
calipers BEFORE soldering the run (both risks resolve in 10 minutes;
90-day free returns cover a miss).

Revised per Arlo mid-session: spares trimmed to lean, and the hinged XYANT
antennas swapped for **straight slim antennas** (Arlo: "I like the straight
stubby antennas better than the giant ones with the hinge").

Final 10 lines:
jacks 200pc ×1 $41.83 · RV09 B10K ×2 (20, exact) $2.49 ·
RD902F-B100K ×2 (10 = 5+5, deliberate insurance on the MPN-only line) $18.50 · EC12 20mm ×3 (6 = 5+1) $2.68 ·
TFT ×6 (5+1, fragile in transit) $5.99 ·
**MGCKTD straight 3dBi antenna + U.FL→RP-SMA pigtail, 5-SET pack ×1 $6.65**
(aliexpress.us/item/3256805483874281.html, 5★/316 sold — replaces XYANT;
kept mainly for its 5 U.FL→RP-SMA bulkhead pigtails, whips = spares) ·
**2.4G mini STRAIGHT stub antennas RP-SMA ×3 packs = 6 pcs $1.47/2pc**
(aliexpress.us/item/3256807938705105.html, 4.9★/500+ — Arlo prefers the
stubby look; screw onto the MGCKTD pigtail bulkheads. NOTE: the 915MHz
LoRa lookalike Arlo first found is the WRONG BAND — always check 2.4GHz) ·
~~SD sniffer 10PCS~~ **REMOVED — WRONG PART** (see below) ·
knobs BLACK ×3 (30; 25 needed) $4.49 ·
M3×10 F-F standoffs 60pc ×1 $6.61 · **M3×6 screws 304SS 50pc ×1 $1.88**
(aliexpress.us/item/2251832785290389.html, SKU M3 50pcs + 6mm).
**Subtotal $150.85 + $19.36 ship − $2 = est. $168.21.**
Knobs are 6.35mm-bore set-screw — grub screw clamps 6mm shafts fine.

## ✅ ORDER PLACED 2026-07-26 — AliExpress 11 lines, $186.02

(Mouser's companion order, 6 lines / $57.04, placed the same day — see
`COMPLETION-SHOPPING-5UNITS.md`.) Encoder caps went out at **1 lot**
(10 caps) after Arlo trimmed from 4. Everything below is the sourcing
record for reference / reorders.

## Ali cart as verified = 11 lines, est. total $190.82 (pre-trim)

(Was 10 lines / $184.42 before the encoder-cap addition below.)

**+ ENCODER CAP (added 07-25):** "10PCS For KY-040 … ABS D Half Shaft
Hole Caps Knob 6mm", item 3256806101256136, $1.60/10 × **4 lots = 40
caps, $6.40** (4 = the seller's whole remaining stock). Hard ABS, true
6mm **D-bore**, **no indicator line**, flat top for the push switch —
see `COMPLETION-SHOPPING-5UNITS.md` for why the encoder gets its own cap
and which candidates were rejected. Knock-on: the 30 Davies knobs now
cover only 25 pot positions, restoring a +5 spare there.

## Earlier verified state — 10 lines, $184.42

Re-read line by line 2026-07-25 after Arlo asked "does that make both
carts ready?": antenna stubs **Straight-2pcs-RP SMA** ×3 (=6) · TFT ×6 ·
RD902F-B100K ×2 (=10) · RV09 **B10K B103** ×2 (=20) · PJ-301M jacks ×1
(=200) · MGCKTD antenna **5set** ×1 · M3×6 screws 50pc ×1 · M3×10
standoffs 60pc ×1 · knobs **Black** ×3 (=30) · EC12 **20mm** ×3 (=6).
All 10 lines selected/checked.

⚠️ **The SD-sniffer removal had to be done TWICE.** The first delete
(earlier the same day) silently did not apply — the line was still in the
cart at re-check, and only a second attempt with the confirm dialog took.
Total fell $197.37 → $184.42, exactly the $12.95. **Both AliExpress and
Mouser cart deletes need a confirm dialog and can silently no-op —
always re-read the cart to verify a removal.**

**SD CORRECTION (later 07-25): the Ali sniffer 10-pack was REMOVED — wrong
part.** Arlo caught it against his test unit (vertical slot). Correct P1 =
**Yamaichi PJS008U-3000 vertical microSD holder**.

**SOURCE IT FROM MOUSER, NOT THONK** (checked 07-25): Mouser
945-PJS008U-3000-0, **$1.17 ea @qty10, 10,877 in stock**, authorized
Yamaichi distributor, parametrics confirm 8-contact / 1.10 mm / through-hole
/ "Ver Dip Mnt". Thonk is £3.59 incl VAT (~$4.55) — 3x the price. Digi-Key
has ZERO stock (marketplace, no backorders). Full table in
`COMPLETION-SHOPPING-5UNITS.md`.

## THONK — ABANDONED 2026-07-25 (Arlo's call)

A cart was staged (6 Yamaichi + 5 power cables, £31.49) then dropped:
SD holders go to Mouser at 1/3 the price, and Arlo sources power cables
separately ("nice but not actually part of the module"). Nothing to buy
from Thonk. Cable reference if ever needed: Thonk "Eurorack Power Cables",
**10-16 Pin** variants (module end = the 2×5 P4 header, bus end = 16-pin),
Micro 8cm £1.50 / Short 15cm £1.66 / Long 25cm £1.91 / XL 0.5m £2.52,
volume discount from 5 up.

## MOUSER ORDER (the second order — see COMPLETION-SHOPPING-5UNITS.md)

SD holders + tacts + Molex micro-USB + LED + 2×5 header. WM8731 spares
DROPPED (PCBWay already populated all 5 codecs — see that doc). Rough
parts total ~$40 before shipping/tariffs.

**NOT moved to Mouser: everything already in the Ali cart.** Mouser would
be 5–10× on jacks/pots/encoders/knobs/TFT (e.g. jacks $0.20 ea on Ali vs
$2–3 at Mouser), and the Ali cart is already verified and signed off.
Reversible if Arlo ever wants single-vendor sourcing at that premium.

## Process notes
- Avoid listings tagged "FREE GIFT / with any purchase" — they open promo
  funnels, not product pages.
- AliExpress search is part-number-blind for PJ398SM/WQP518MA; the winning
  queries were "PJ301M-12 3.5mm jack", "RD902F B100K", "EC12 rotary encoder
  push switch 20mm", "microSD sniffer TF card extender adapter board".

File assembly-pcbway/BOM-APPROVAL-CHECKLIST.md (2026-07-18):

# PCBWay BOM approval checklist — pre-payment gate

## ✅ ORDERED 2026-07-17

Paid on quote **T-1N8W1065663A**: subtotal **$430.00** (main-board turnkey
$370.65 + panel qty 5 matte-black ENIG $59.35) + **$150.00 duty (34.9%,
DDP)** + DHL freight — **shipped DHL DDP** (duty prepaid, PCBWay's broker
clears; no carrier surprise invoice). All 5 main boards assembled, codec
populated. Everything below was verified before payment.

---

Quote **T-1N8W1065663A**, revised **$370.65 / 5 units** (component $284.44 +
assembly $29.00 + PCB $57.21), all 5 boards assembled, codec populated.
**BOM rev 2 confirmed 2026-07-16** — full-file diff vs rev 1 showed exactly
one cell changed (IC4 "DO NOT POPULATE" note removed).

## Why no CSV is needed

PCBWay assembles from the BOM revision *you approve*, not from the email
thread. The rep edits their working copy and sends it back for confirmation —
an unambiguous email line is as good as an attached file. The one thing that
actually gates production is which document carries your approval.

## Resolved (verified 2026-07-16, BOM rev 2)

- [x] **IC4 populate landed.** Line item 40: designator IC4, MPN
      **WM8731SEDS/RV** @ $17.44/pc ($87.20/5), sourced by PCBWay from LCSC,
      DNP note removed, qty ×5 — all boards get the codec.
- [x] **Revised quote went UP by a plausible amount.** +$107.02 vs the 07-08
      quote = codec $87.20 + the two previously-unpriced cap lines $19.82.
      No suspicious "free codec" line.
- [x] **Cap substitutions landed with correct 16V MPNs:**
      - C38/C39/C42 → AVX **TAJA226M016RNJ** (22µF 16V 1206, our named sub;
        `016` = 16V)
      - C36 → Panasonic **EEE-FK1C102SV** (verified 1000µF 16V,
        10.0×10.8mm — AEC-Q200 sibling of the FK1C102P we named; 10mm can
        fits case-G pads, 0.6mm taller is a non-issue)
- [x] **WROVER sub correct:** ESP32-WROVER-IE-N8R8, **IPEX variant**
      re-confirmed in the approval reply, accepted @ $7.47.
- [x] **Codec authenticity decision made:** boards get LCSC-sourced
      WM8731SEDS/RV (the best real source — Rochester has NO stock, see
      SOURCING-NOTES). Optional hedge: order a few spare /RV from LCSC
      directly with the sidecar orders.

## Final engineer pass (Arlo, on the order page, before paying)

Package = the fixed KiCad-plotted gerber zips (`gerbers/` — the
`--check-zones` ones), BOM rev 2 as returned by PCBWay, and
`SOURCING-NOTES.md`.

- [x] **Cart BOM verified = rev 2** (2026-07-17: Arlo re-downloaded the
      order-cart files to ~/Downloads/Filez; the cart .xls is CELL-IDENTICAL
      to the confirmed rev 2 — byte diff was .xls metadata only). Full audit
      re-run on the cart copy: IC4 populated (no DNP anywhere), subs
      TAJA226M016RNJ / EEE-FK1C102SV in Actual-Purchase, IPEX note on IC5,
      every line unit×qty×5 exact, component sum $284.44, grand total
      $370.645. BOM↔CPL cross-check clean (all 141 BOM refs placed; the 33
      CPL-only refs are the intentional hand-build kit parts).
- [x] **Cart gerbers verified = the FIXED plots** (same re-download): both
      main-board zips byte-identical to ours (B.Cu 959KB, pours filled);
      panel zip differs ONLY in plot timestamp + project name
      ("panel-final", plotted 16:54 vs our 17:10) — all 9 layers
      geometry-identical to the audit-passing plot.
- [ ] Total on the payment page is **$370.65** — the quote UI had a
      price-ratchet bug before; if the number moved, re-quote clean, don't
      pay a drifted figure.
- [ ] Panel order: matte black, ENIG.
- [ ] Ship-to address + shipping tier sanity check.

## Final gate

- [ ] Pay against the rev 2 BOM / $370.65 quote. Then fire the sidecar
      orders: Thonk (jacks/pots/SD/knobs ~£50) or Qingpu direct,
      AliExpress ILI9341 TFT + IPEX antenna, encoder/USB-B/switches,
      optionally spare WM8731SEDS/RV from LCSC.

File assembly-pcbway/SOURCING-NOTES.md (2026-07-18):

# Sourcing notes — codec + panel components (2026-07-07)

## WM8731 codec (IC4) — the critical part

Stock reality (checked 2026-07-07 via OEMsTrade aggregation):
- **Rochester Electronics: NO stock listed** (despite being the usual
  genuine-EOL route — don't count on them for this part).
- **LCSC: 592 x WM8731SEDS/RV @ $8.38–13.31** — the best real source.
  LCSC is JLCPCB's sister distributor, reputable, same ecosystem as the
  Chinese fabs. `/RV` = tape-and-reel packaging of the SAME SSOP28 chip
  as `/V` (tube). Fully interchangeable.
- HK brokers (IC Components, YIC) list `/RV` at ~$1.53 — **fake-risk tier**,
  a $1.50 obsolete Wolfson codec is usually a remarked blank. Avoid.
- Mouser: /V discontinued, /RV backorder with long lead. Not practical.

**Preferred plan:** ask PCBWay (during BOM review) to source the codec from
LCSC and populate IC4 — see message template below. Boards then arrive
fully SMD-complete, no SSOP28 hand-soldering, and every board carries its
own irreplaceable codec.

**Fallback:** order 7 pcs WM8731SEDS/RV from lcsc.com yourself (~$70 for 5
units + spares) and hand-solder (flux + drag, SSOP28 is very doable).

## Message template for PCBWay BOM review (paste into the order chat)

> Regarding BOM item IC4 (WM8731, currently marked DO NOT POPULATE):
> please quote sourcing **WM8731SEDS/RV** from **LCSC** (approx. 590 pcs
> in stock as of July 2026, ~$8–13/pc) and populate IC4 on all assembled
> boards. Note: WM8731SEDS/RV is the tape-and-reel packaging of
> WM8731SEDS/V — same die, same SSOP28 package, fully interchangeable.
> If you can source it, please remove the DNP flag for IC4 and update the
> quote. If LCSC stock is gone, keep IC4 as DNP.

Where to send it: PCBWay account → Orders → the assembly order → order
message thread / online chat with your service rep (BOM review questions
arrive there or by email — reply in the same thread).

## Jacks & pots — Thonk vs direct

"Thonkiconn" is Thonk's nickname for the **Qingpu WQP-PJ398SM** vertical
mono 3.5 mm jack (~GBP 0.62 at Thonk, ~$0.25–0.35 from Qingpu's own
AliExpress storefront — same manufacturer, same part). For 5 units you
need 70 jacks (order ~80): ~GBP 43 at Thonk vs ~$25 direct, slower ship.

**Footprint warning:** the board is laid out for the PJ398SM pattern
(2 signal pins + wide ground lug). The visually similar PJ301M-12 style
has a DIFFERENT footprint and will not fit. Only buy listings explicitly
marked PJ398SM / WQP-PJ398SM with clear photos.

Pots are standard Alpha 9mm verticals (RD901F style): B10k x4 + B100k
dual-gang x1 per unit — Thonk, Tayda, or Ali all carry them.

## PCBWay quote response (2026-07-08) — quote T-1N8W1065663A, 5 units

Quote received: **$263.63 / 5 units** (component $177.42 + assembly $29.00 +
PCB $57.21), codec EXCLUDED (IC4 still DNP in this quote). ESP32-WROVER-IE-
N8R8 accepted & populated ($7.47) with the IPEX-required note honored.

**Two parts PCBWay flagged out of stock** — subs decided (both 16V, ratings
decoded from the original MPNs since the value column omits voltage):

- **C38 C39 C42 (qty 3) — 22µF 16V tantalum, 1206 (case A).** Original AVX
  TCTAL1C226M8R (`1C`=16V). Subs given: **KEMET T491A226M016AT** or **AVX
  TAJA226M016RNJ** (or any in-stock low-ESR polymer, same size/rating).
  These positions are rail decoupling — MnO2 tant is fine.
- **C36 (qty 1) — 1000µF 16V SMD electrolytic, case "Panasonic G"
  (10×10.2mm).** Original Chemi-Con APXG160ARA102MJA0G (`160`=16V). Subs:
  **Panasonic EEE-FK1C102P** or **Nichicon UWT1C102MNL1GS**. MUST stay 16V +
  10×10.2mm — 25V pushes to a taller/wider can that won't fit case G pads.

**Reply sent to PCBWay:** substitute-your-choice-equivalent for both caps
(named parts as acceptable) + the codec-populate request from the template
above (source WM8731SEDS/RV from LCSC, populate IC4, remove DNP; keep DNP if
LCSC stock gone). Expect the revised total to rise ~$40–65 if they populate
the codec. Awaiting revised quote.

## Per-unit completion cost (if PCBWay populates the codec)

Assembled board (amortized) + jacks/pots direct + TFT + antenna + misc
hardware ≈ **$70–80 per unit** on top of the PCBWay order. Boards keep
forever; buy completion parts only for the units you actually build.

## Revised quote (2026-07-16) — APPROVED at $370.65 / 5 units

Component $284.44 + assembly $29.00 + PCB $57.21 = **$370.65** (+$107 vs the
07-08 quote: WM8731 $87.20 + the two previously-unpriced cap lines $19.82).

- **IC4**: sourced as **WM8731SEDS/RV** @ $17.44/pc ($87.20/5). ⚠️ The BOM
  still carried the old "DO NOT POPULATE" instruction on item 40 — reply told
  PCBWay to populate IC4 on all 5 boards and remove the note.
- **C38/C39/C42**: purchased as **TAJA226M016RNJ** (our named AVX sub, 16V
  case A). Accepted.
- **C36**: purchased as **EEE-FK1C102SV** — verified 1000µF 16V,
  10.0mm dia × 10.8mm (DigiKey). Same 10mm can as case G (0.6mm taller,
  clearance non-issue); it's the current AEC-Q200 sibling of the
  EEE-FK1C102P we named. Accepted. Rep (Remi) couldn't string-match
  "APXG160A102MJA0G" — that's the ORIGINAL Chemi-Con part C36 replaces;
  told them to ignore.
- ESP32-WROVER-IE-N8R8 IPEX-variant note re-confirmed in the reply.
- All BOM quantities are ×5 → **all 5 boards fully assembled**.

Quote approved in the order thread; awaiting production start.
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

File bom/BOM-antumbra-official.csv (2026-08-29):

Name | Qty | Value | Index | Specs | Package | Mouser reference | Note
SMD parts:
Resistor | 1 | 10 | R30 |  | 2512 | 279-CRGP2512F10R
Resistor, 1% | 1 | 68 | R32 |  | 0603 | 603-AC0603FR-0768RL
Resistor, 1% | 1 | 220 | R33 |  | 0603 | 652-CR0603FX-2200ELF
Resistor, 1% | 2 | 1k | R12 R13 |  | 0603 | 652-CR0603FX-1001ELF
Resistor, 1% | 2 | 3.3k | R8 R9 |  | 0603 | 652-CR0603-FX3301ELF
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

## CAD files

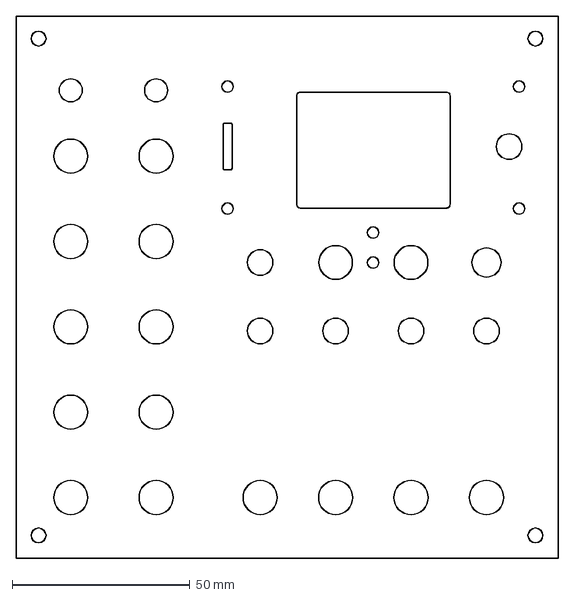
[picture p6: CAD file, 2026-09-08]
panel-emu/emu_panel_cut.dxf
152.4 x 152.4 mm

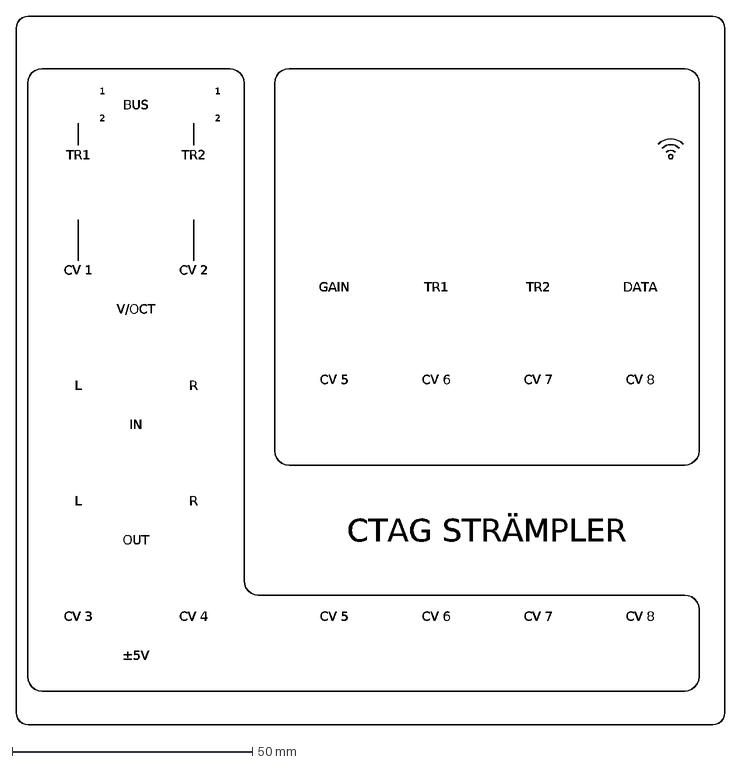
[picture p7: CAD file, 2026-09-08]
panel-emu/emu_panel_art.dxf
CV 5
CV 6
CV 7
CV 8
GAIN
DATA
TR1
TR2
CV 1
CV 2
L
R
CV 3
CV 4
V/OCT
IN
OUT
±5V
1
2
BUS
CTAG STRÄMPLER

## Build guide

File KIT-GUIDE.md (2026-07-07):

# Strämpler DIY kit pack — bare boards + parts, NO assembly (2026-07-06)

For putting together **build kits** of the Antumbra CTAG Strämpler: bare
PCBs + panel + a complete parts kit per build. All SMD is hand-solderable
(0603 passives, SOIC/TSSOP/SSOP ICs, one QFN — the CP2102N — and the
castellated ESP32 module). See "Licensing & selling" at the bottom before
selling anything.

## 0. Board formats — Eagle AND KiCad

`boards/` holds the original Eagle 7.3 files; `boards-kicad/` holds KiCad 10
conversions (made with `kicad-cli pcb import --format eagle`, KiCad 10.0.4,
2026-07-07) plus verification renders. **Eagle was sunset by Autodesk in
2026** — the KiCad files are the living, forkable format; the Eagle files
remain the designer's originals. Statistics from the import: main board 174
footprints / 2001 tracks / 263 vias / 4 zones; panel 32 footprints / 38210
art zones. The schematic (`.sch`) imports via the KiCad GUI:
File → Import Non-KiCad Project → EAGLE (kicad-cli cannot do schematics).

## 1. Boards (any fab; PCBWay shown since it takes Eagle natively)

pcbway.com → PCB Instant Quote:
- `boards/Strampler_redesign_v2_2.brd` — main board, 91.3 x 108 mm, 2-layer,
  1.6 mm, HASL fine for hand-soldering (ENIG easier for the QFN). Qty 5 or 10.
- `boards/strampler_panel_v2_2.brd` — panel, 93.9 x 130.1 mm, 2-layer, 1.6 mm,
  matte black + ENIG for the classic Antumbra look. Same qty.
- No assembly service on either. ~$25–35 per design per 5 pcs + shipping.
- (JLCPCB is a few dollars cheaper but needs gerbers converted from the
  Eagle files first — PCBWay quotes the .brd directly.)

## 2. Mouser parts — one cart per kit

Upload `mouser-bom-ONE-KIT.csv` at mouser.com → BOM Tool. Quantities are for
ONE kit — set the multiplier to your kit count in the BOM tool. 43 lines,
~$45–60 per kit at qty-1 pricing. Notes:
- IC5 is entered by MPN `ESP32-WROVER-IE-N8R8` — verify the tool matches the
  **-IE (IPEX antenna)** variant, NOT the plain -E; the module lives behind a
  metal panel and needs the external antenna.
- Some 2019 Mouser SKUs may be superseded — accept the tool's suggested
  equivalents for passives (1% resistors, X5R/X7R ceramics).
- The designer's original cart also exists (may be stale):
  https://www.mouser.com/ProjectManager/ProjectDetail.aspx?AccessID=9c1a090daf

## 3. Parts NOT at Mouser — `parts-NOT-from-mouser.csv`

Per kit:
- **Thonk** (thonk.co.uk): 14x Thonkiconn PJ398SM, 4x B10k pot, 1x B100k
  dual-gang pot, uSD breakout, knobs — ~£45–55.
- **AliExpress**: 2.2" 240x320 SPI TFT (ILI9341) ~$8; IPEX WiFi antenna ~$3.
- **Rotary encoder** (Bourns PEC11-style w/ switch), 2x5 male header,
  M3 10mm F-F standoffs x5 + M3 6mm screws x10 — any supplier.
- **WM8731SEDS/V x1 (+ spare recommended)** — obsolete. Rochester
  Electronics for genuine EOL stock (~$6–12); UTSource/eBay cheaper with
  fake risk. THE critical part: without it there is no audio.

## 4. Per-kit cost, roughly

| | |
|---|---|
| Boards (main + panel, amortised at qty 5) | $12–18 |
| Mouser cart | $45–60 |
| Thonk | £45–55 (~$60–70) |
| TFT + antenna + encoder + misc hardware | ~$25 |
| WM8731 (+spare) | $12–25 |
| **Per kit** | **≈ $160–195** |

## 5. Kit contents checklist (what goes in each bag)

1 main PCB, 1 panel, the Mouser bag, the Thonk bag, TFT, antenna, encoder,
WM8731, hardware (standoffs/screws/header). Builder needs: firmware from
github.com/ctag-fh-kiel/ctag-straempler (or the tungusk fork for the
machines build), flashed over USB with `--flash_size detect`; an SD card
(FAT32, <=2GB files) with the CONFIG.JSN from the repo.

Build order: SMD (ICs first, WM8731 SSOP28 with flux+drag), then power-up
smoke test (3.3V rails), then through-hole loosely, panel on, align, solder.

## 6. Licensing & selling (checked 2026-07-06 — not legal advice)

Two licenses apply (LICENSE file in the firmware repo):
- **Firmware: GPL 3.0** — commercial use allowed; you must provide source to
  buyers (the public repo/fork satisfies this; forks must stay GPL).
- **Hardware: CC BY-NC-SA 4.0** — the **NonCommercial** clause means building
  boards from the design files **to sell** is NOT permitted without separate
  permission from the rights holders: CTAG (Robert Manzke, Phillip Lamp,
  Niklas Wantrupp — creative-technologies.de) and Antumbra (antumbra.eu /
  @antumbra_modular) for the redesign layout.

Practical gradations as commonly understood:
- Selling YOUR OWN existing module secondhand: fine (personal property).
- Kits/builds for friends at cost: the gray zone NC tolerates in practice;
  keep it small-scale and non-profit.
- Building to sell at a profit: squarely prohibited without a yes from both
  CTAG and Antumbra first.

Permission looks gettable: CTAG's README asks people to "help build and
spread the hardware module", and Pusherman openly sold panel/PCB sets. A
short email describing what you'd sell is the way in.

Also: **ShareAlike** — any board/panel modifications you distribute must be
published under the same license. Freesound access is per-user (each owner
needs their own API key); that's not something you can license to buyers.

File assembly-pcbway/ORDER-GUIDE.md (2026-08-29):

# PCBWay order guide — Antumbra CTAG Strämpler (2026-07-06)

Two items to order: the **main board (PCB + turnkey SMD assembly, 2 assembled)**
and the **panel (bare PCB, no assembly)**. Hardware license CC BY-NC-SA 4.0 —
personal/non-commercial build.

## 1. Main board — PCB + assembly

Go to pcbway.com → *PCB Instant Quote* → *Quick-order PCB*.

- Upload **`gerbers-main-Strampler_redesign_v2_2.zip`** (RS-274X gerbers +
  Excellon drills, plotted from the KiCad conversion — PCBWay's uploader
  rejects raw Eagle .brd files).
- PCB specs: 2 layers, 1.6 mm FR4, HASL or ENIG (ENIG nicer under the QFN/SSOP),
  any solder-mask colour. Quantity: 5 (their PCB minimum — assemble 2, 3 spares).
- Tick **Assembly Service**: Turnkey, **Assemble 2**, ONE side (all SMD is on
  the BOTTOM side — 144 bottom / 30 top placements in the CPL; the top-side
  refs are through-hole and NOT for assembly).
- Upload `BOM-PCBWay-assembly.csv` (40 SMD lines) and
  **`CPL-kicad-origin.csv`** when the assembly form asks (this position file
  is exported from the same KiCad board as the gerbers, so origins match;
  `CPL-Strampler_redesign_v2_2.csv` is the older Eagle-coordinate version).

### BOM notes PCBWay must see (paste into the order remarks)
- ~~**IC4 / WM8731: DO NOT POPULATE.** Obsolete part; customer hand-solders later.~~
  **SUPERSEDED — this did NOT happen.** BOM rev 2 (approved 2026-07-16)
  REMOVED the DNP note: PCBWay populated IC4 = WM8731SEDS/RV @ $17.44/pc,
  ×5, LCSC-sourced. See `BOM-APPROVAL-CHECKLIST.md`. All 5 boards ship
  with the codec already soldered — no hand-soldering, no spares needed.
  (`BOM-PCBWay-assembly.csv` still carries the stale DNP note too.)
- **IC5: ESP32-WROVER-IE-N8R8** substitutes the discontinued WROVER-IB.
  The **IPEX/-I (external antenna) variant is required** — the module sits
  behind a metal panel; the PCB-antenna variant (non-I) will not work.
- All other Supplier P/Ns are Mouser references from the designer's BOM
  (2019) — approve reasonable equivalents for passives if any ref is stale,
  1% tolerance on resistors, X7R/X5R on ceramics.
- The CPL lists ALL footprints incl. through-hole (jacks/pots/encoder);
  assemble only the designators present in the BOM.

## 2. Panel — bare PCB

Separate quick-order: upload **`gerbers-panel-strampler_panel_v2_2.zip`**
(**passed PCBWay audit 2026-07**). Note for anyone regenerating from the
KiCad conversion: KiCad's Eagle importer produces UNFILLED zones, which plot
as empty layers — the first plot failed audit with "lack of copper layer",
and the silkscreen artwork was missing too. This zip is post-fix (copper
pours filled, the 34k-rect artwork converted to filled shapes). Uploading
the raw Eagle `.brd` via PCBWay's "other formats" engineer-conversion route
may also work but is untested.

⚠️ **Rev 2026-08-28 — use the CURRENT zip.** The 2026-07 zip (which passed
audit and was fabbed) had a second conversion bug: the LED light window
(wavy line at L1) was plotted as a mask opening over *filled copper*
instead of bare FR4, so the LED can't shine through. Fixed in the KiCad
panel (copper keep-out rule area) and the zip regenerated; the 2026-07
panels are defective. See `hardware-kicad/README.md` pitfall 2.
- 2 layers (it's just FR4 with plating/art), 1.6 mm, **matte black + ENIG**
  is the classic Antumbra look. Qty 5 (minimum).
- No assembly.

## 3. Parts the fab does NOT supply (order alongside)

From **Thonk**: 14× Thonkiconn PJ398SM jacks, 4× B10k pot, 1× B100k dual-gang
pot, SD card reader (μSD breakout per BOM), knobs. From **AliExpress**:
2.2" 240×320 SPI TFT (ILI9341), IPEX WiFi antenna. Elsewhere: rotary encoder,
USB-B (Mouser 538-105017-0001), 2× D6R00F1LFS tactile switches, 5 mm red LED,
2x5 male header, screen connector (Mouser 798-MDF79S254DSA55), M3 standoffs
+ screws. **WM8731SEDS/V ×2** from a broker (Rochester Electronics is the
legit-stock route; UTSource/eBay cheaper but inspect for fakes).

## 4. After delivery

Hand-solder order: WM8731 (SSOP28, flux + drag), then TH parts loosely, fit
the panel, align, then solder. Flash firmware per the repo README/CLAUDE.md
(`--flash_size detect`; a WROVER-E with 8 MB flash matches the current unit).

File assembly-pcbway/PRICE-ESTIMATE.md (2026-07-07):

# Price estimate — PCBWay turnkey order (2026-07-06)

Assembled option: 2 assembled main boards (SMD only, WM8731 DNP), 5 bare
main PCBs total, 5 panels. Boards measured from the Eagle files:
main 91.3 x 108.0 mm, panel 93.9 x 130.1 mm (18 HP).

| Item | Estimate (USD) |
|---|---|
| Main PCB, 2-layer, qty 5 (assemble 2) | 25–35 |
| Assembly setup + stencil + labour (2 boards, ~144 SMD each, one side) | 70–90 |
| Turnkey parts, 2 board sets (incl. ~15% sourcing markup) | 85–100 |
| Panel, qty 5, matte black + ENIG | 40–60 |
| DHL shipping | 25–35 |
| **PCBWay total** | **≈ 250–320** |

Parts cost is dominated by: R-78E3.3 regulator (~$10/board), MCP3208 (~$4),
ESP32-WROVER-IE (~$4), CP2102N (~$2.50). Plain green HASL panel saves ~$25.
Assembling 1 instead of 2 saves only ~$50 (setup dominates).

## Not covered by PCBWay (per finished module)

| Item | Estimate |
|---|---|
| Thonk: 14x Thonkiconn, 5 pots, SD breakout, knobs | £45–55 |
| AliExpress: ILI9341 2.2" TFT + IPEX antenna | ~$11 |
| Encoder, USB-B, tact switches, LED, headers, standoffs | ~$15 |
| WM8731 x2 (broker: Rochester genuine ~$6–12 ea; UTSource/eBay cheaper, fake risk) | $12–25 |

**All-in, one finished module + one spare assembled board: ~$350–420.**

Exact turnkey numbers come from PCBWay's human BOM review, usually <24 h
after upload (see ORDER-GUIDE.md).

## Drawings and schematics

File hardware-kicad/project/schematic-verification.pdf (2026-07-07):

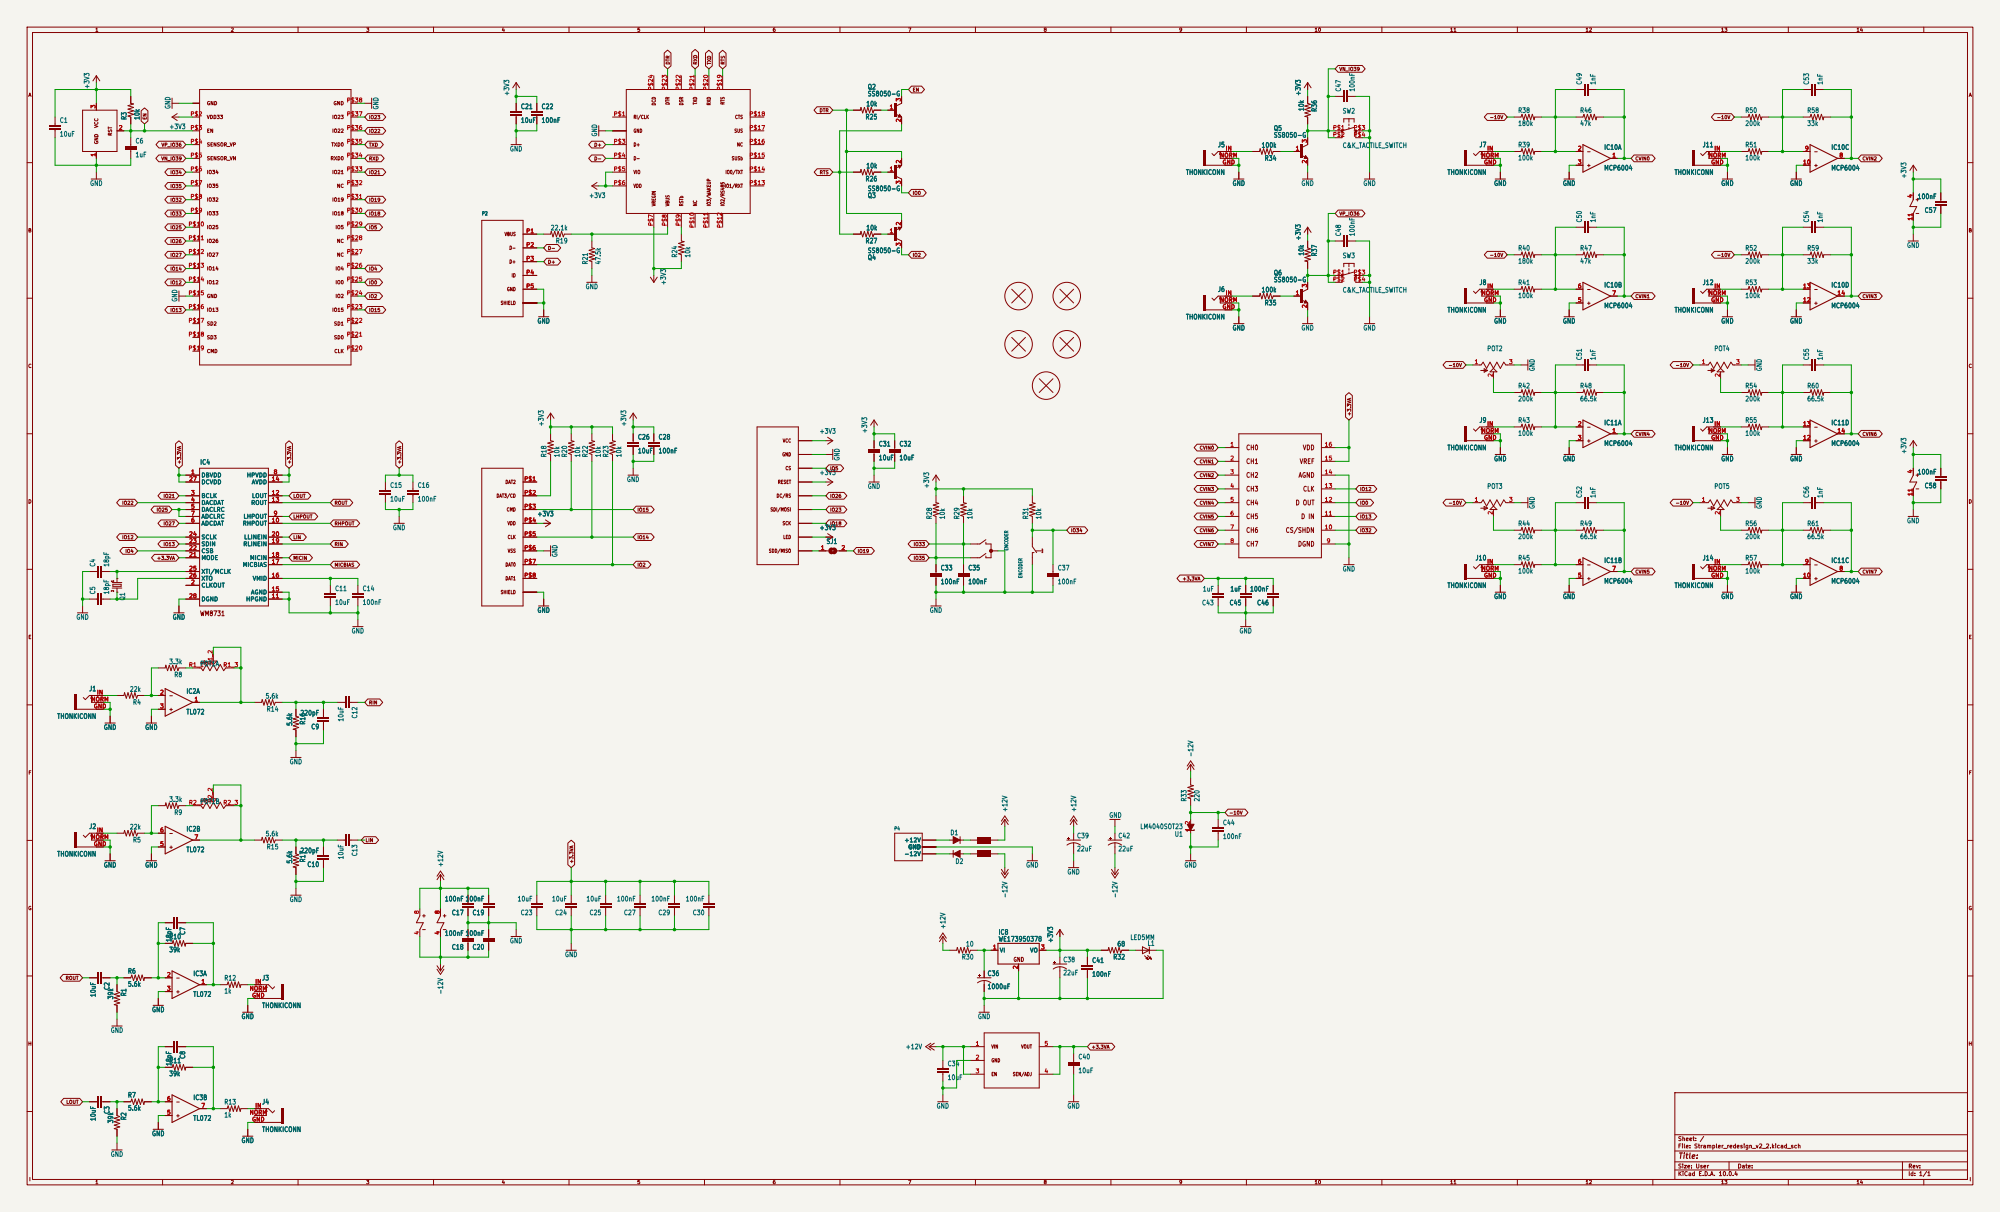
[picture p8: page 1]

VCC
GND
CS RESET DC/RS

Size: User | Rev: | I Date:
KiCad E.D.A. 10.0.4 | Id: 1/1

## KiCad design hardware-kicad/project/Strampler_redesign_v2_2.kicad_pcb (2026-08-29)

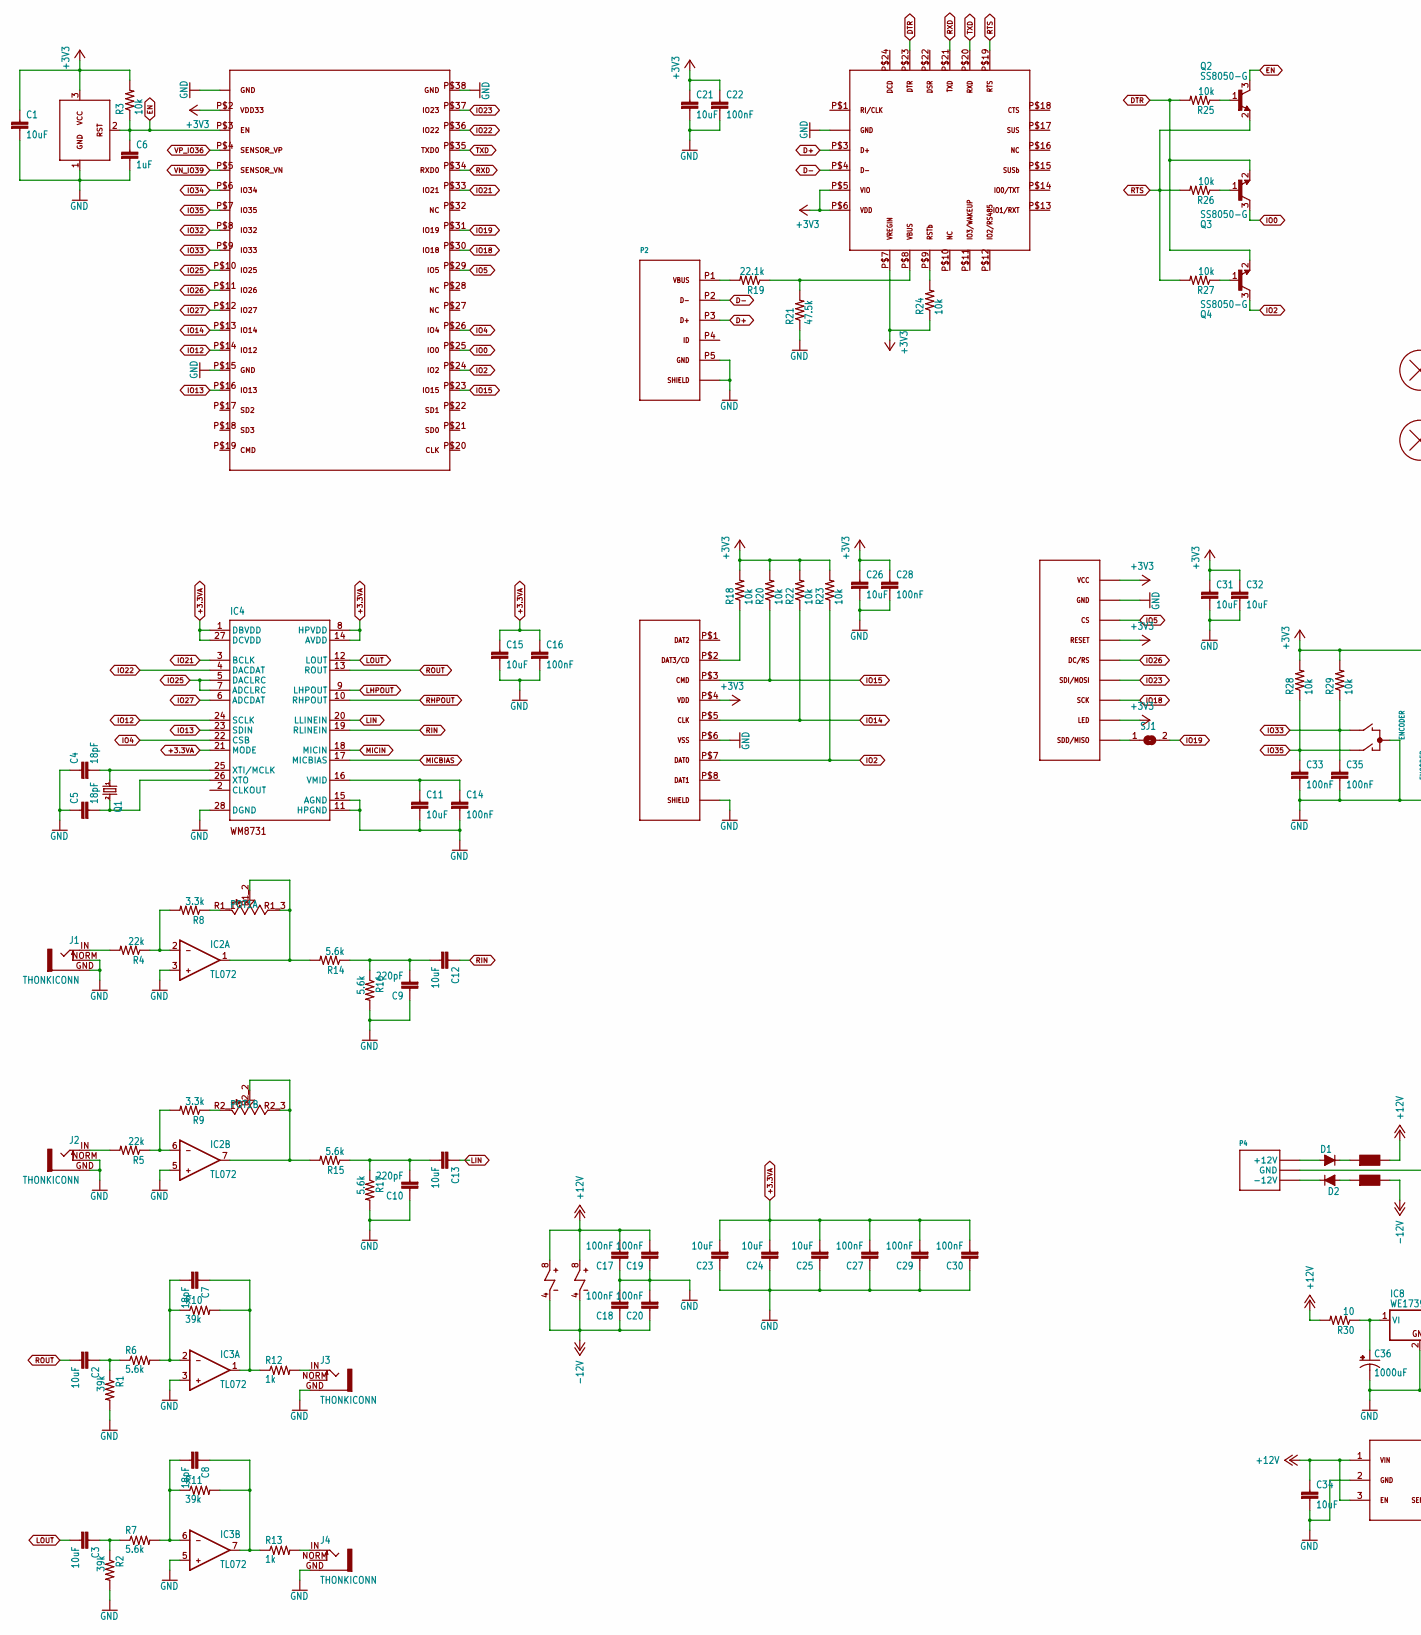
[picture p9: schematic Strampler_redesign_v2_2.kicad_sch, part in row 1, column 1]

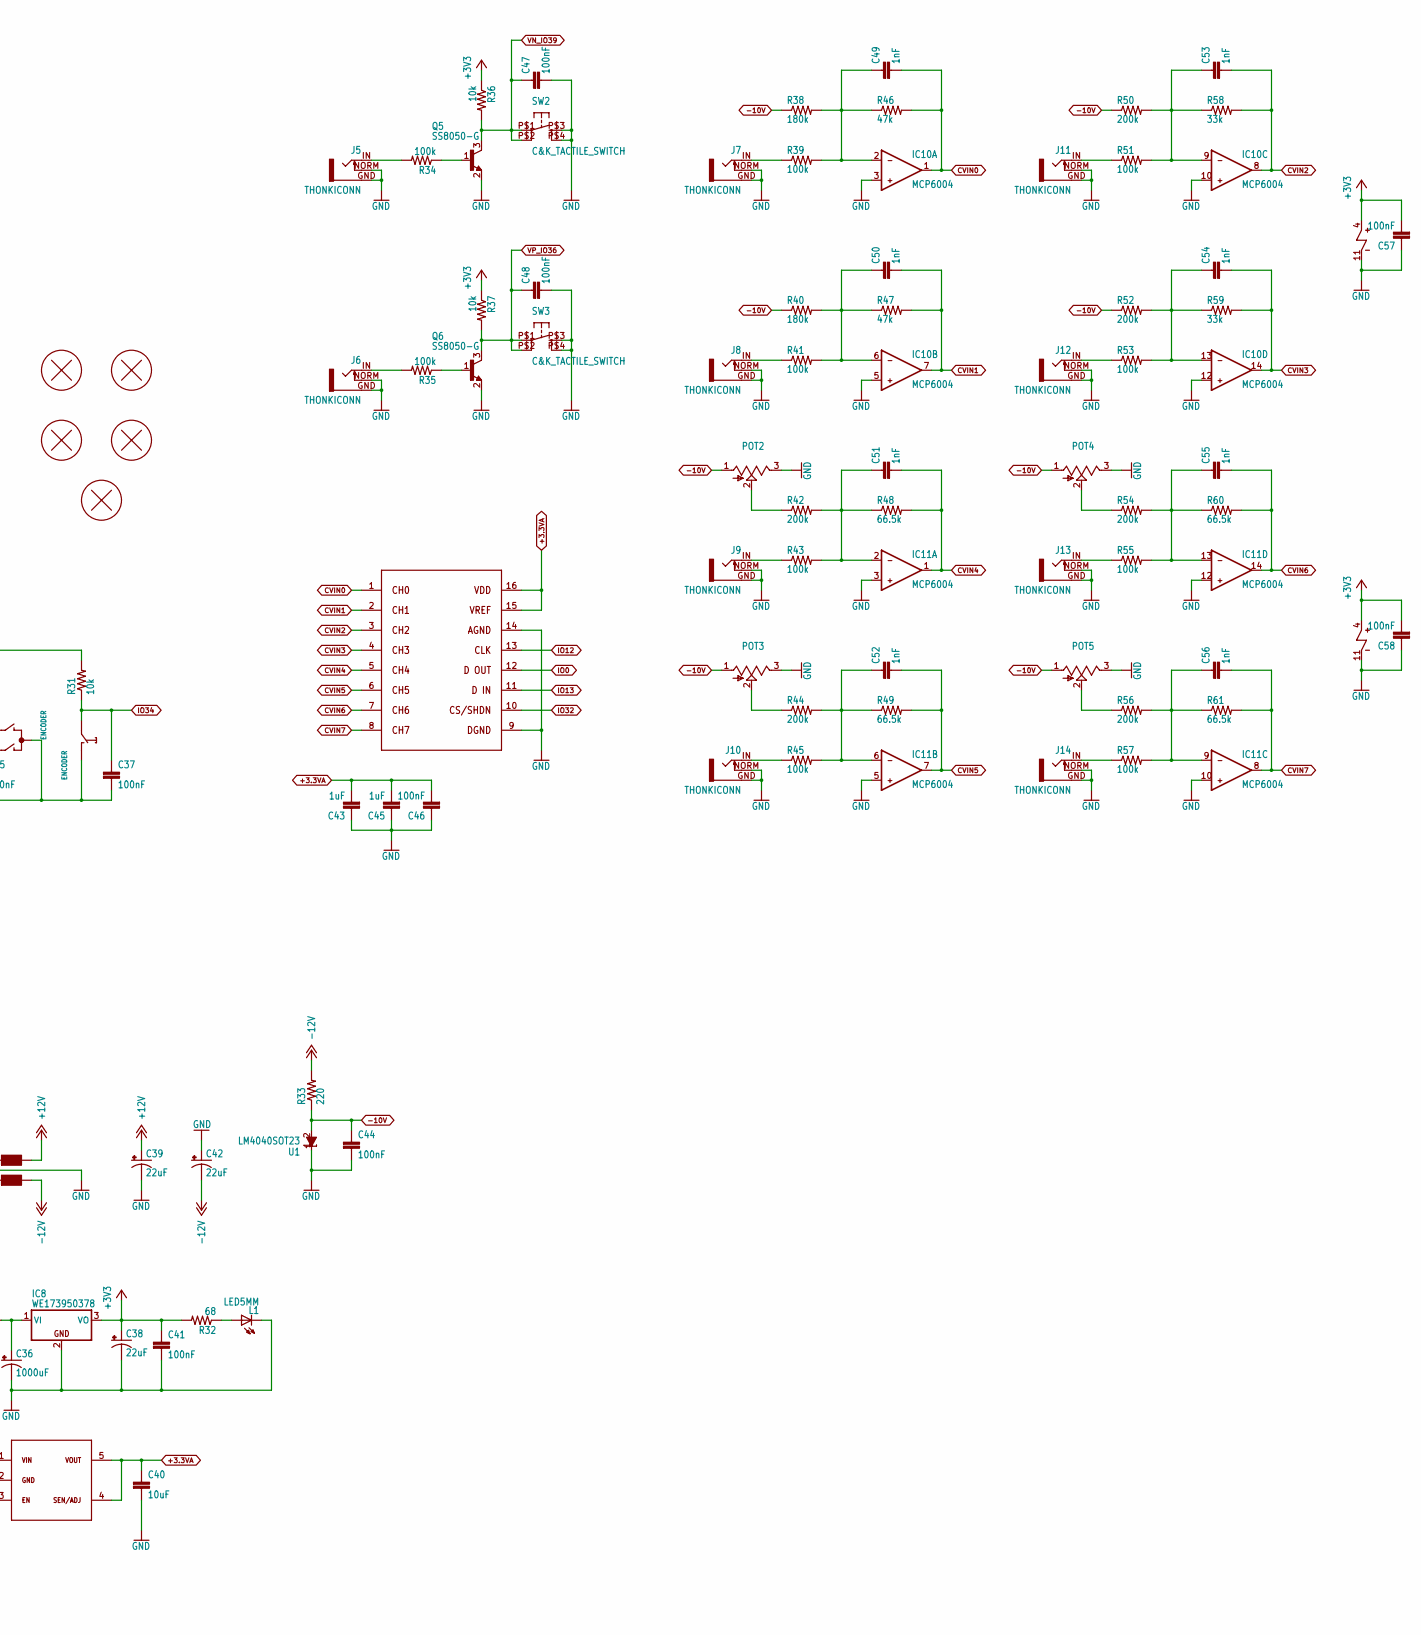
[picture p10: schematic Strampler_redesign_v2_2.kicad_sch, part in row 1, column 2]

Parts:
C1, C2, C3, C11, C12, C13, C15, C21, C23, C24, C25, C26, C31, C32, C40: 10uF; R0805
C4, C5, C7, C8: 18pF; RESISTOR_0603
C6, C43, C45: 1uF; RESISTOR_0603
C9, C10: 220pF; RESISTOR_0603
C14, C16, C17, C18, C19, C20, C22, C27, C28, C29, C30, C33, C35, C37, C41, C44, C46, C47, C48, C57, C58: 100nF; RESISTOR_0603
C34: 10uF; R1210
C36: 1000uF; PANASONIC_G
C38, C39, C42: 22uF; 1206_POL
C49, C50, C51, C52, C53, C54, C55, C56: 1nF; RESISTOR_0603
D1, D2: DIODE; SOD123
F1, F2: FERRITE-BEAD0805; R0805
H1, H2, H3, H4, H5: PCB_SCREW
IC1: MIC803; SOT23
IC2, IC3: TL072; SOIC8
IC4: WM8731; SSOP28
IC5: ESP32-WROVER-B
IC6: CP2102N
IC7: ADP7118; SOT23-5L
IC8: WE173950378; WE78
IC9: MCP3208; SOIC16
IC10, IC11: MCP6004; TSSOP14
J1, J2, J3, J4, J5, J6, J7, J8, J9, J10, J11, J12, J13, J14: THONKICONN; PROTOJACK
L1: LED5MM; LED_5MM
P1: SD-CARD; SD-CARD-THONK
P2: USB-B; USB-B-MOLEX-1050170001
P3: MSP2202_DISPLAY
P4: POWER_SIMPLE10; POWER_10
POT1: POT_DUAL_THONK
POT2, POT3, POT4, POT5: POT_VERTICAL; ALPS_POT_VERTICAL
Q1: CRYSTAL; HC49UP
Q2, Q3, Q4, Q5, Q6: SS8050-G; SOT23
R1, R2, R10, R11: 39k; RESISTOR_0603
R3, R18, R20, R22, R23, R24, R25, R26, R27, R28, R29, R31, R36, R37: 10k; RESISTOR_0603
R4, R5: 22k; RESISTOR_0603
R6, R7, R14, R15, R16, R17: 5.6k; RESISTOR_0603
R8, R9: 3.3k; RESISTOR_0603
R12, R13: 1k; RESISTOR_0603
R19: 22.1k; RESISTOR_0603
R21: 47.5k; RESISTOR_0603
R30: 10; R2512
R32: 68; RESISTOR_0603
R33: 220; RESISTOR_0603
R34, R35, R39, R41, R43, R45, R51, R53, R55, R57: 100k; RESISTOR_0603
R38, R40: 180k; RESISTOR_0603
R42, R44, R50, R52, R54, R56: 200k; RESISTOR_0603
R46, R47: 47k; RESISTOR_0603
R48, R49, R60, R61: 66.5k; RESISTOR_0603
R58, R59: 33k; RESISTOR_0603
SJ1: SJ
SW1: ENCODER; ALPS_EC12E_SW; MPN EC12E2424407
SW2, SW3: C&K_TACTILE_SWITCH
U1: LM4040SOT23; SOT23

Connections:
+3.3VA: C15.1, C16.1, C23.2, C24.2, C25.2, C27.2, C29.2, C30.2, C40.1, C43.2, C45.2, C46.2, IC4.1 (DBVDD), IC4.8 (HPVDD), IC4.14 (AVDD), IC4.21 (MODE), IC4.27 (DCVDD), IC7.4, IC7.5, IC9.15, IC9.16
+3V3: C1.1, C21.1, C22.1, C26.1, C28.1, C31.1, C32.1, C38.2 (+), C41.1, C57.2, C58.2, IC1.3, IC5.P$2, IC6.P$5, IC6.P$6, IC6.P$7, IC8.3 (VO), IC10.4, IC11.4, P1.P$4, P3.LED, P3.LED1, P3.RESET, P3.RESET1, P3.VCC, P3.VCC1, R3.2, R18.2, R20.2, R22.2, R23.2, R24.1, R28.2, R29.2, R31.2, R32.2, R36.1, R37.1
+12V: C17.2, C19.2, C34.1, C39.2 (+), F1.1, IC2.8, IC3.8, IC7.1, IC7.3, R30.2
-10V: C44.1, POT2.1 (A), POT3.1 (A), POT4.1 (A), POT5.1 (A), R33.1, R38.1, R40.1, R50.1, R52.1, U1.2 (A)
-12V: C18.1, C20.1, C42.1 (-), F2.1, IC2.4, IC3.4, R33.2
CVIN0: C49.2, IC9.1, IC10.1, R46.2
CVIN1: C50.2, IC9.2, IC10.7, R47.2
CVIN2: C53.2, IC9.3, IC10.8, R58.2
CVIN3: C54.2, IC9.4, IC10.14, R59.2
CVIN4: C51.2, IC9.5, IC11.1, R48.2
CVIN5: C52.2, IC9.6, IC11.7, R49.2
CVIN6: C55.2, IC9.7, IC11.14, R60.2
CVIN7: C56.2, IC9.8, IC11.8, R61.2
D+: IC6.P$3, P2.P3
D-: IC6.P$4, P2.P2
DTR: IC6.P$23, Q3.2 (E), Q4.2 (E), R25.2
EN: C6.1, IC1.2, IC5.P$3, Q2.3 (C), R3.1
GND: C1.2, C4.1, C5.1, C6.2, C9.1, C10.1, C11.2, C14.2, C15.2, C16.2, C17.1, C18.2, C19.1, C20.2, C21.2, C22.2, C23.1, C24.1, C25.1, C26.2, C27.1, C28.2, C29.1, C30.1, C31.2, C32.2, C33.2, C34.2, C35.2, C36.-, C37.2, C38.1 (-), C39.1 (-), C40.2, C41.2, C42.2 (+), C43.1, C44.2, C45.1, C46.1, C47.2, C48.2, C57.1, C58.1, IC1.1, IC2.3, IC2.5, IC3.3, IC3.5, IC4.11 (HPGND), IC4.15 (AGND), IC4.28 (DGND), IC5.GND, IC5.GND2, IC5.P$1, IC5.P$15, IC5.P$38, IC6.GND, IC6.GND2, IC6.P$2, IC7.2, IC8.2 (GND), IC9.9, IC9.14, IC10.3, IC10.5, IC10.10, IC10.11, IC10.12, IC11.3, IC11.5, IC11.10, IC11.11, IC11.12, J1.GND, J1.NORM, J2.GND, J2.NORM, J3.GND, J4.GND, J5.GND, J5.NORM, J6.GND, J6.NORM, J7.GND, J7.NORM, J8.GND, J8.NORM, J9.GND, J9.NORM, J10.GND, J10.NORM, J11.GND, J11.NORM, J12.GND, J12.NORM, J13.GND, J13.NORM, J14.GND, J14.NORM, L1.K (C), P1.P$6, P1.P$9, P1.P$10, P2.P5, P2.P$1, P2.P$2, P2.P$8, P2.P$9, P2.P$10, P2.P$11, P3.GND, P3.GND1, P4.3 (GND), P4.4 (GND), P4.5 (GND), P4.6 (GND), P4.7 (GND), P4.8 (GND), POT2.3 (B), POT3.3 (B), POT4.3 (B), POT5.3 (B), Q5.2 (E), Q6.2 (E), R1.2, R2.2, R16.2, R17.2, R21.1, SW1.C, SW1.D (1), SW2.P$3 (3), SW2.P$4 (4), SW3.P$3 (3), SW3.P$4 (4), U1.1 (C)
IO0: IC5.P$25, IC9.12, Q3.3 (C)
IO2: IC5.P$24, P1.P$7, Q4.3 (C), R23.1
IO4: IC4.22 (CSB), IC5.P$26
IO5: IC5.P$29, P3.CS, P3.CS1
IO12: IC4.24 (SCLK), IC5.P$14, IC9.13
IO13: IC4.23 (SDIN), IC5.P$16, IC9.11
IO14: IC5.P$13, P1.P$5, R22.1
IO15: IC5.P$23, P1.P$3, R20.1
IO18: IC5.P$30, P3.SCK, P3.SCK1
IO19: IC5.P$31, SJ1.2
IO21: IC4.3 (BCLK), IC5.P$33
IO22: IC4.4 (DACDAT), IC5.P$36
IO23: IC5.P$37, P3.SDI/MOSI, P3.SDI/MOSI1
IO25: IC4.5 (DACLRC), IC4.7 (ADCLRC), IC5.P$10
IO26: IC5.P$11, P3.DC/RS, P3.DC/RS1
IO27: IC4.6 (ADCDAT), IC5.P$12
IO32: IC5.P$8, IC9.10
IO33: C35.1, IC5.P$9, R29.1, SW1.B
IO34: C37.1, IC5.P$6, R31.1, SW1.E (2)
IO35: C33.1, IC5.P$7, R28.1, SW1.A
LHPOUT: IC4.9 (LHPOUT)
LIN: C13.1, IC4.20 (LLINEIN)
LOUT: C3.2, IC4.12 (LOUT)
MICBIAS: IC4.17 (MICBIAS)
MICIN: IC4.18 (MICIN)
unnamed: IC6.P$9, R24.2
unnamed: IC6.P$8, R19.1, R21.2
unnamed: Q2.1 (B), R25.1
unnamed: P2.P1, R19.2
unnamed: P1.P$2, R18.1
unnamed: Q3.1 (B), R26.1
unnamed: P3.SDD/MISO, P3.SDD/MISO1, SJ1.1
unnamed: J5.IN, R34.2
unnamed: Q4.1 (B), R27.1
unnamed: J6.IN, R35.2
unnamed: Q5.1 (B), R34.1
unnamed: Q6.1 (B), R35.1
unnamed: J7.IN, R39.1
unnamed: J11.IN, R51.1
unnamed: C53.1, IC10.9, R50.2, R51.2, R58.1
unnamed: J8.IN, R41.1
unnamed: C49.1, IC10.2, R38.2, R39.2, R46.1
unnamed: POT3.2 (W), R44.1
unnamed: C50.1, IC10.6, R40.2, R41.2, R47.1
unnamed: J12.IN, R53.1
unnamed: C54.1, IC10.13, R52.2, R53.2, R59.1
unnamed: POT2.2 (W), R42.1
unnamed: J9.IN, R43.1
unnamed: C51.1, IC11.2, R42.2, R43.2, R48.1
unnamed: J13.IN, R55.1
unnamed: C55.1, IC11.13, R54.2, R55.2, R60.1
unnamed: J10.IN, R45.1
unnamed: C52.1, IC11.6, R44.2, R45.2, R49.1
unnamed: J14.IN, R57.1
unnamed: C56.1, IC11.9, R56.2, R57.2, R61.1
unnamed: J1.IN, R4.2
unnamed: IC2.2, R4.1, R8.2
unnamed: D1.+, P4.9 (+12V), P4.10 (+12V)
unnamed: POT1.R1_1 (A), R8.1
unnamed: POT5.2 (W), R56.1
unnamed: IC2.1, POT1.R1_2 (W), POT1.R1_3 (B), R14.2
unnamed: C9.2, C12.2, R14.1, R16.1
unnamed: POT4.2 (W), R54.1
unnamed: J2.IN, R5.2
unnamed: IC2.6, R5.1, R9.2
unnamed: POT1.R2_1 (A), R9.1
unnamed: IC2.7, POT1.R2_2 (W), POT1.R2_3 (B), R15.2
unnamed: C5.2, IC4.26 (XTO), Q1.2
unnamed: C4.2, IC4.25 (XTI/MCLK), Q1.1
unnamed: C10.2, C13.2, R15.1, R17.1
unnamed: C7.1, IC3.1, R10.2, R12.1
unnamed: D1.-, F1.2
unnamed: C7.2, IC3.2, R6.2, R10.1
unnamed: C2.1, R1.1, R6.1
unnamed: C36.+, IC8.1 (VI), R30.1
unnamed: J3.IN, R12.2
unnamed: D2.-, P4.1 (-12V), P4.2 (-12V)
unnamed: C8.1, IC3.7, R11.2, R13.1
unnamed: C8.2, IC3.6, R7.2, R11.1
unnamed: C11.1, C14.1, IC4.16 (VMID)
unnamed: C3.1, R2.1, R7.1
unnamed: J4.IN, R13.2
unnamed: D2.+, F2.2
unnamed: L1.A, R32.1
RHPOUT: IC4.10 (RHPOUT)
RIN: C12.1, IC4.19 (RLINEIN)
ROUT: C2.2, IC4.13 (ROUT)
RTS: IC6.P$19, Q2.2 (E), R26.2, R27.2
RXD: IC5.P$34, IC6.P$21
TXD: IC5.P$35, IC6.P$20
VN_IO39: C47.1, IC5.P$5, Q5.3 (C), R36.2, SW2.P$1 (1), SW2.P$2 (2)
VP_IO36: C48.1, IC5.P$4, Q6.3 (C), R37.2, SW3.P$1 (1), SW3.P$2 (2)

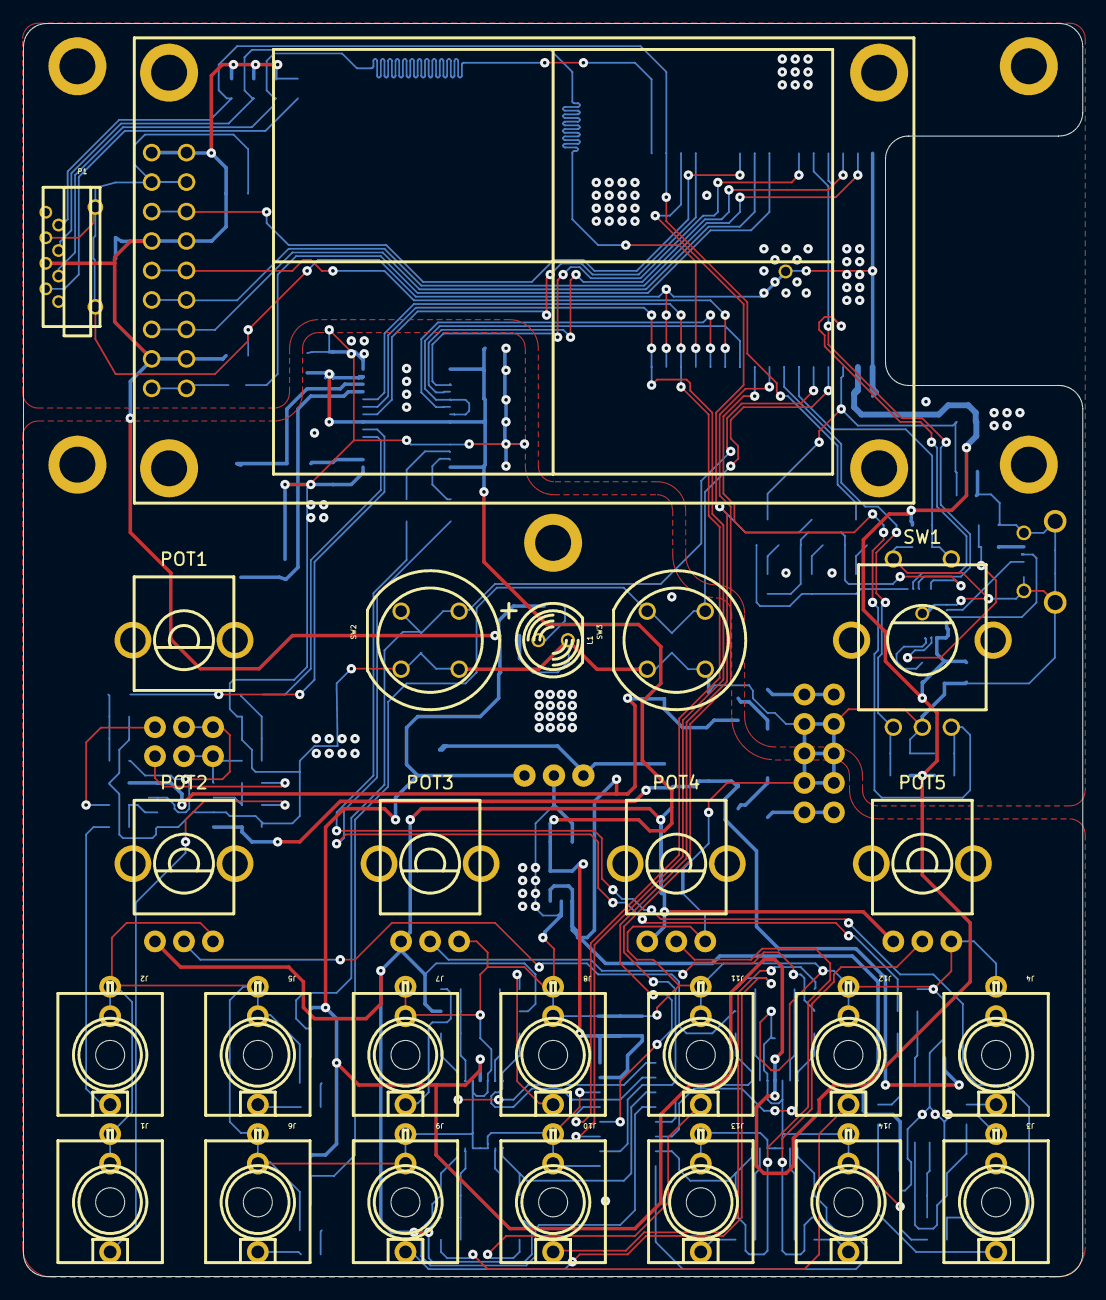
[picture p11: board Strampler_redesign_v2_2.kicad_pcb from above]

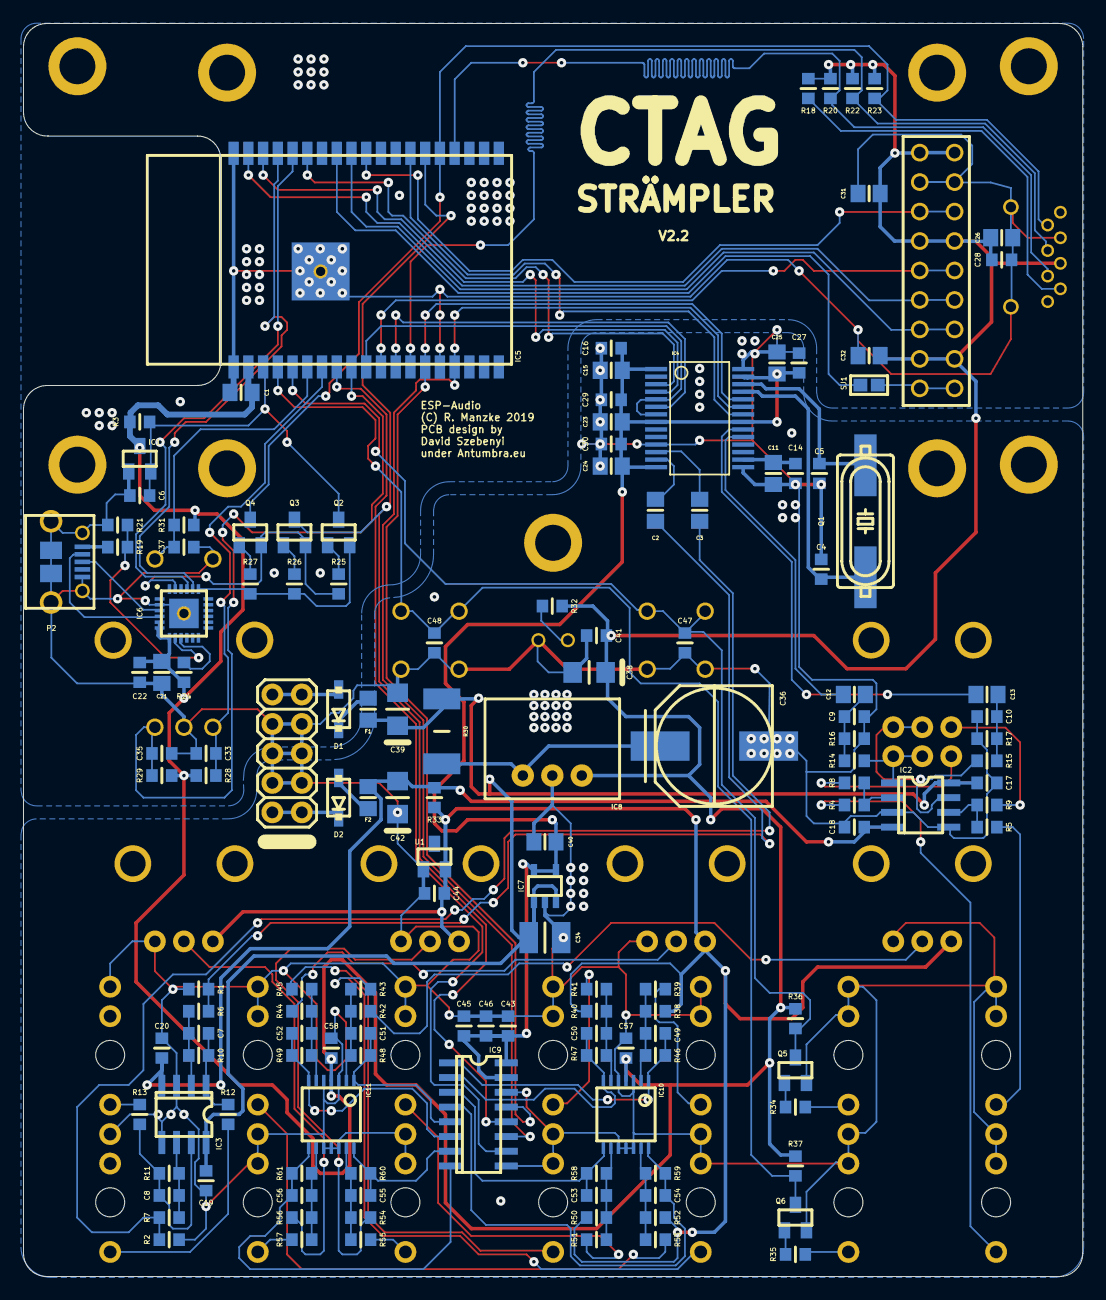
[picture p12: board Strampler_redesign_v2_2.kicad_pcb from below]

Board: 2 copper layers, 91.3 x 108.0 mm, 174 parts (144 on the bottom side), 106 nets.

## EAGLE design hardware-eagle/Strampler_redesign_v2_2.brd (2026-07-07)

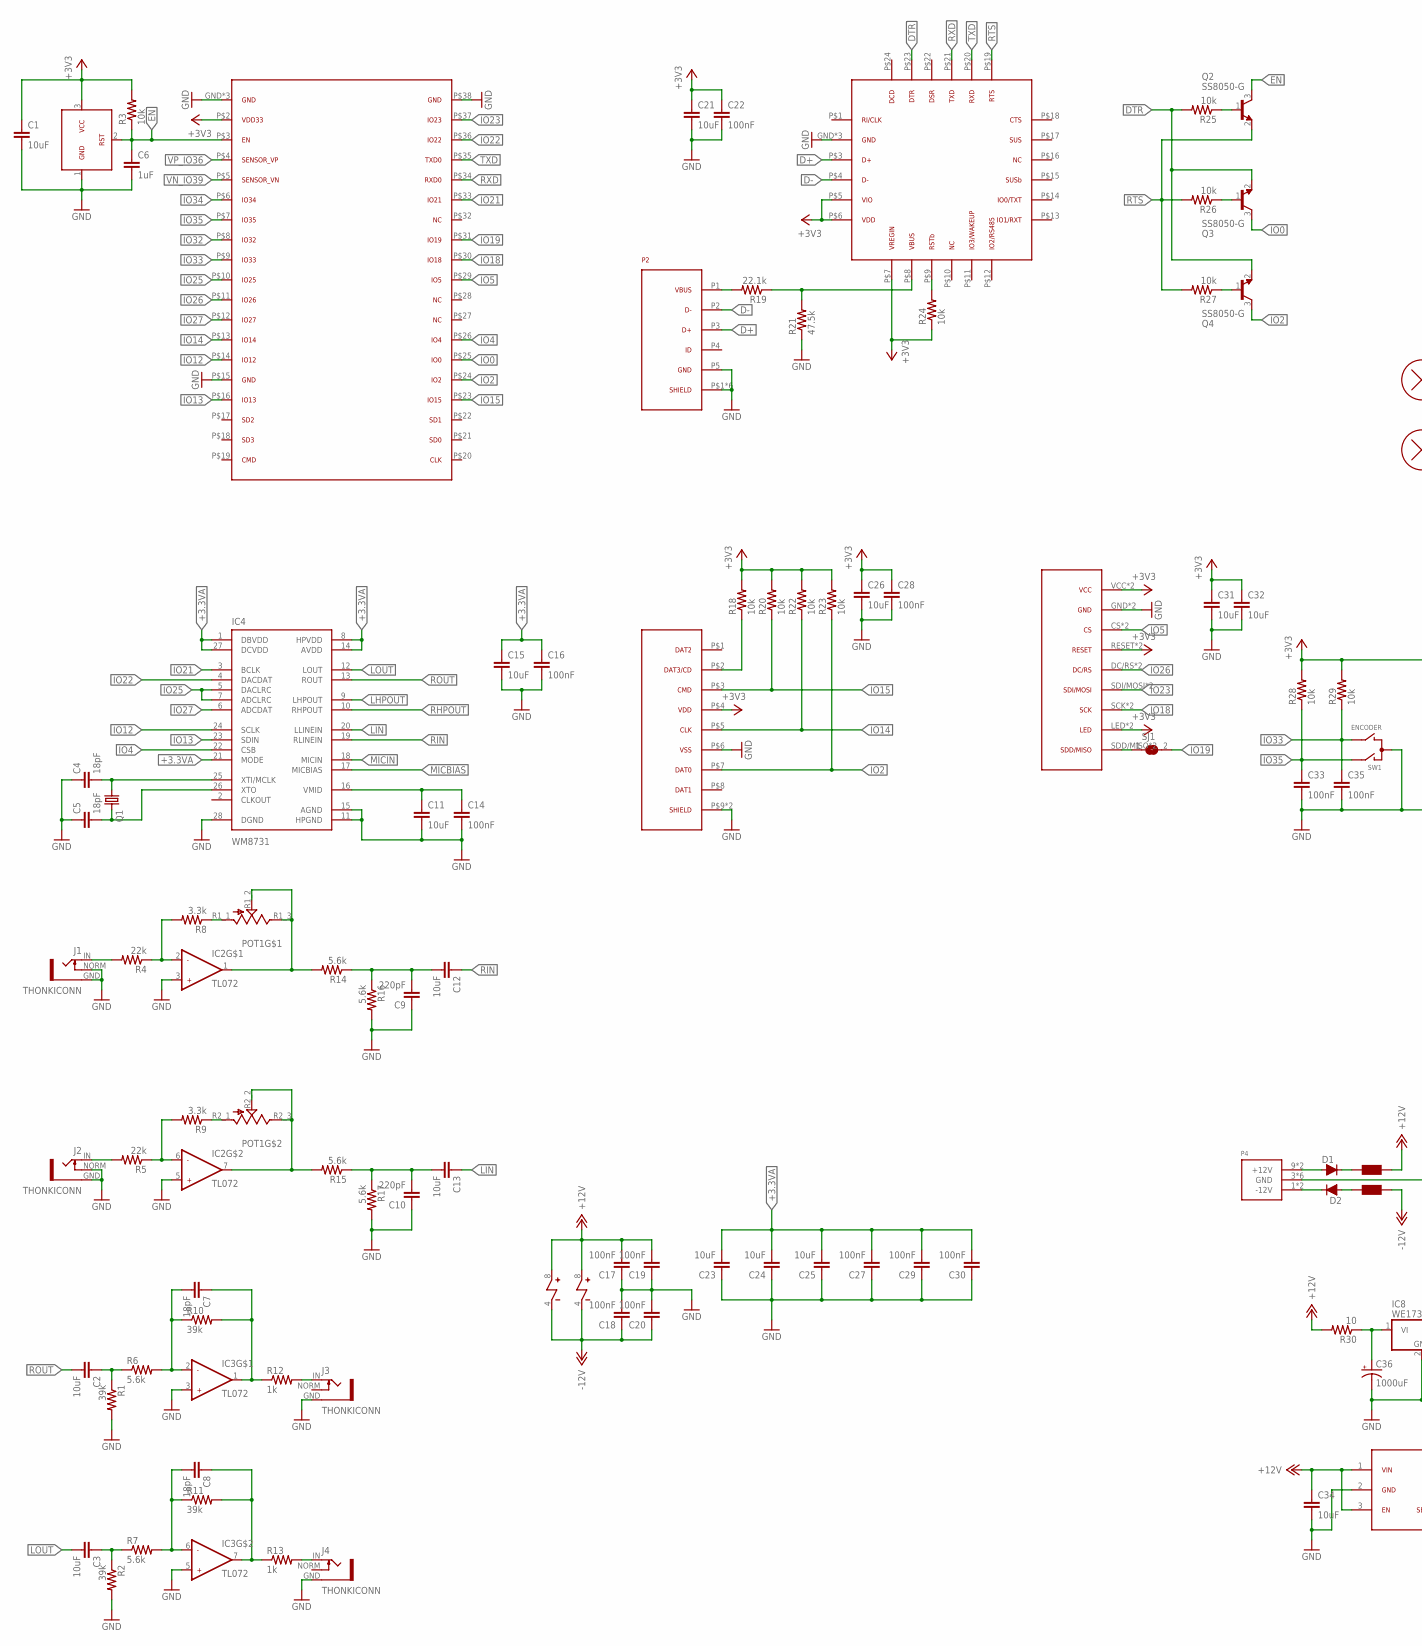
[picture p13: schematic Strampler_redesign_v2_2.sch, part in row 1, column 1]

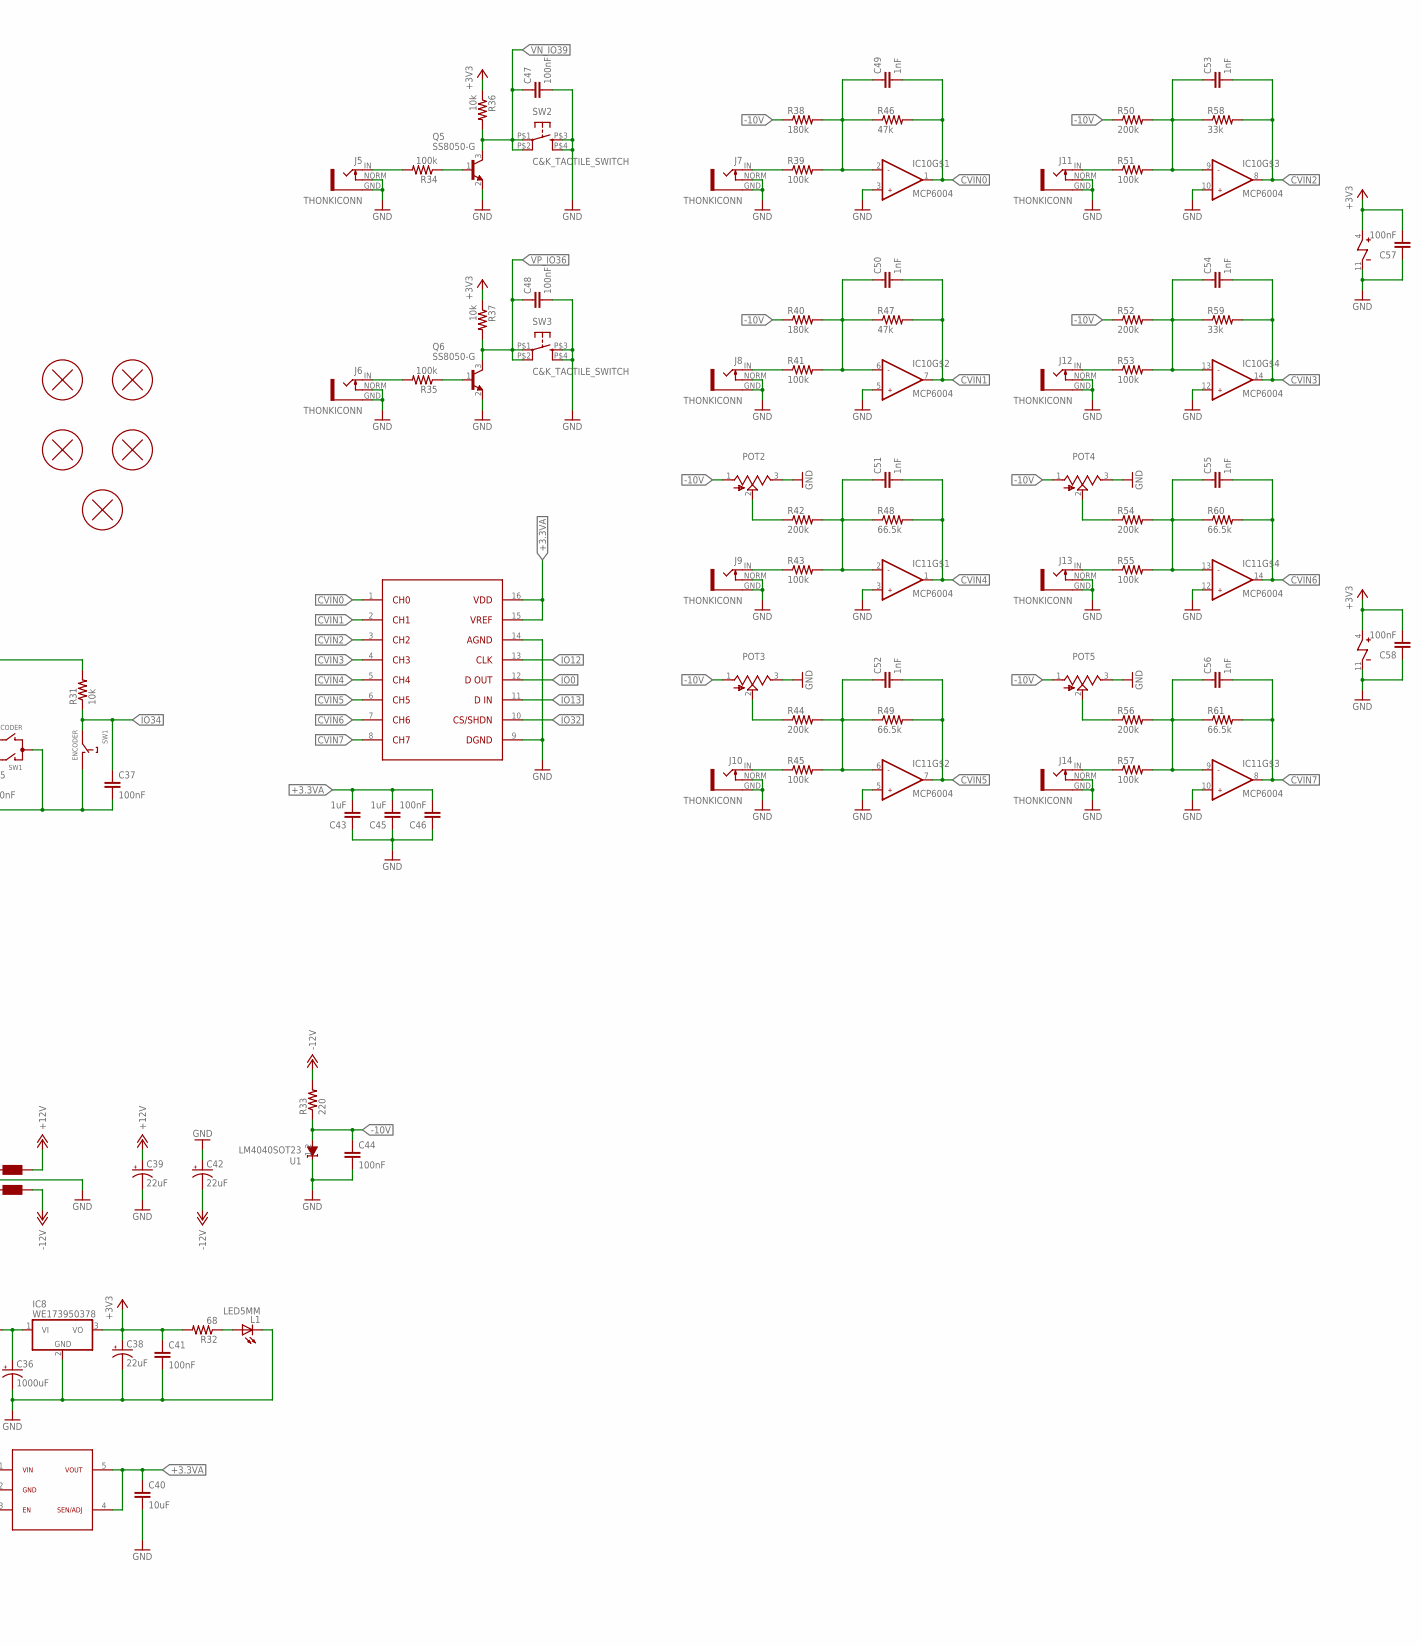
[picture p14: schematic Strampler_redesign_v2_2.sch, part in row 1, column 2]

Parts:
C1, C2, C3, C11, C12, C13, C15, C21, C23, C24, C25, C26, C31, C32, C40: 10uF; R0805
C4, C5, C7, C8: 18pF; RESISTOR_0603
C6, C43, C45: 1uF; RESISTOR_0603
C9, C10: 220pF; RESISTOR_0603
C14, C16, C17, C18, C19, C20, C22, C27, C28, C29, C30, C33, C35, C37, C41, C44, C46, C47, C48, C57, C58: 100nF; RESISTOR_0603
C34: 10uF; R1210
C36: 1000uF; PANASONIC_G
C38, C39, C42: 22uF; 1206_POL
C49, C50, C51, C52, C53, C54, C55, C56: 1nF; RESISTOR_0603
D1, D2: DIODE; SOD123
F1, F2: FERRITE-BEAD0805; R0805
H1, H2, H3, H4, H5: PCB_SCREW
IC1: MIC803; SOT23
IC2, IC3: TL072; SOIC8
IC4: WM8731; SSOP28
IC5: ESP32-WROVER-B
IC6: CP2102N
IC7: ADP7118; SOT23-5L
IC8: WE173950378; WE78
IC9: MCP3208; SOIC16
IC10, IC11: MCP6004; TSSOP14
J1, J2, J3, J4, J5, J6, J7, J8, J9, J10, J11, J12, J13, J14: THONKICONN; PROTOJACK
L1: LED5MM; LED_5MM
P1: SD-CARD; SD-CARD-THONK
P2: USB-B; USB-B-MOLEX-1050170001
P3: MSP2202_DISPLAY
P4: POWER_SIMPLE10; POWER_10
POT1: POT_DUAL_THONK
POT2, POT3, POT4, POT5: POT_VERTICAL; ALPS_POT_VERTICAL
Q1: CRYSTAL; HC49UP
Q2, Q3, Q4, Q5, Q6: SS8050-G; SOT23
R1, R2, R10, R11: 39k; RESISTOR_0603
R3, R18, R20, R22, R23, R24, R25, R26, R27, R28, R29, R31, R36, R37: 10k; RESISTOR_0603
R4, R5: 22k; RESISTOR_0603
R6, R7, R14, R15, R16, R17: 5.6k; RESISTOR_0603
R8, R9: 3.3k; RESISTOR_0603
R12, R13: 1k; RESISTOR_0603
R19: 22.1k; RESISTOR_0603
R21: 47.5k; RESISTOR_0603
R30: 10; R2512
R32: 68; RESISTOR_0603
R33: 220; RESISTOR_0603
R34, R35, R39, R41, R43, R45, R51, R53, R55, R57: 100k; RESISTOR_0603
R38, R40: 180k; RESISTOR_0603
R42, R44, R50, R52, R54, R56: 200k; RESISTOR_0603
R46, R47: 47k; RESISTOR_0603
R48, R49, R60, R61: 66.5k; RESISTOR_0603
R58, R59: 33k; RESISTOR_0603
SJ1: SJ
SW1: ENCODER; ALPS_EC12E_SW
SW2, SW3: C&K_TACTILE_SWITCH
U1: LM4040SOT23; SOT23

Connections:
+3.3VA: C15.1, C16.1, C23.2, C24.2, C25.2, C27.2, C29.2, C30.2, C40.1, C43.2, C45.2, C46.2, IC4.1 (DBVDD), IC4.8 (HPVDD), IC4.14 (AVDD), IC4.21 (MODE), IC4.27 (DCVDD), IC7.4, IC7.5, IC9.15, IC9.16
+3V3: C1.1, C21.1, C22.1, C26.1, C28.1, C31.1, C32.1, C38.2 (+), C41.1, C57.2, C58.2, IC1.3, IC5.P$2, IC6.P$5, IC6.P$6, IC6.P$7, IC8.3 (VO), IC10.4, IC11.4, P1.P$4, P3.LED, P3.LED1, P3.RESET, P3.RESET1, P3.VCC, P3.VCC1, R3.2, R18.2, R20.2, R22.2, R23.2, R24.1, R28.2, R29.2, R31.2, R32.2, R36.1, R37.1
+12V: C17.2, C19.2, C34.1, C39.2 (+), F1.1, IC2.8, IC3.8, IC7.1, IC7.3, R30.2
-10V: C44.1, POT2.1 (A), POT3.1 (A), POT4.1 (A), POT5.1 (A), R33.1, R38.1, R40.1, R50.1, R52.1, U1.2 (A)
-12V: C18.1, C20.1, C42.1 (-), F2.1, IC2.4, IC3.4, R33.2
CVIN0: C49.2, IC9.1, IC10.1, R46.2
CVIN1: C50.2, IC9.2, IC10.7, R47.2
CVIN2: C53.2, IC9.3, IC10.8, R58.2
CVIN3: C54.2, IC9.4, IC10.14, R59.2
CVIN4: C51.2, IC9.5, IC11.1, R48.2
CVIN5: C52.2, IC9.6, IC11.7, R49.2
CVIN6: C55.2, IC9.7, IC11.14, R60.2
CVIN7: C56.2, IC9.8, IC11.8, R61.2
D+: IC6.P$3, P2.P3
D-: IC6.P$4, P2.P2
DTR: IC6.P$23, Q3.2 (E), Q4.2 (E), R25.2
EN: C6.1, IC1.2, IC5.P$3, Q2.3 (C), R3.1
GND: C1.2, C4.1, C5.1, C6.2, C9.1, C10.1, C11.2, C14.2, C15.2, C16.2, C17.1, C18.2, C19.1, C20.2, C21.2, C22.2, C23.1, C24.1, C25.1, C26.2, C27.1, C28.2, C29.1, C30.1, C31.2, C32.2, C33.2, C34.2, C35.2, C36.-, C37.2, C38.1 (-), C39.1 (-), C40.2, C41.2, C42.2 (+), C43.1, C44.2, C45.1, C46.1, C47.2, C48.2, C57.1, C58.1, IC1.1, IC2.3, IC2.5, IC3.3, IC3.5, IC4.11 (HPGND), IC4.15 (AGND), IC4.28 (DGND), IC5.GND, IC5.GND2, IC5.P$1, IC5.P$15, IC5.P$38, IC6.GND, IC6.GND2, IC6.P$2, IC7.2, IC8.2 (GND), IC9.9, IC9.14, IC10.3, IC10.5, IC10.10, IC10.11, IC10.12, IC11.3, IC11.5, IC11.10, IC11.11, IC11.12, J1.GND, J1.NORM, J2.GND, J2.NORM, J3.GND, J4.GND, J5.GND, J5.NORM, J6.GND, J6.NORM, J7.GND, J7.NORM, J8.GND, J8.NORM, J9.GND, J9.NORM, J10.GND, J10.NORM, J11.GND, J11.NORM, J12.GND, J12.NORM, J13.GND, J13.NORM, J14.GND, J14.NORM, L1.K (C), P1.P$6, P1.P$9, P1.P$10, P2.P5, P2.P$1, P2.P$2, P2.P$8, P2.P$9, P2.P$10, P2.P$11, P3.GND, P3.GND1, P4.3 (GND), P4.4 (GND), P4.5 (GND), P4.6 (GND), P4.7 (GND), P4.8 (GND), POT2.3 (B), POT3.3 (B), POT4.3 (B), POT5.3 (B), Q5.2 (E), Q6.2 (E), R1.2, R2.2, R16.2, R17.2, R21.1, SW1.C, SW1.D (1), SW2.P$3 (3), SW2.P$4 (4), SW3.P$3 (3), SW3.P$4 (4), U1.1 (C)
IO0: IC5.P$25, IC9.12, Q3.3 (C)
IO2: IC5.P$24, P1.P$7, Q4.3 (C), R23.1
IO4: IC4.22 (CSB), IC5.P$26
IO5: IC5.P$29, P3.CS, P3.CS1
IO12: IC4.24 (SCLK), IC5.P$14, IC9.13
IO13: IC4.23 (SDIN), IC5.P$16, IC9.11
IO14: IC5.P$13, P1.P$5, R22.1
IO15: IC5.P$23, P1.P$3, R20.1
IO18: IC5.P$30, P3.SCK, P3.SCK1
IO19: IC5.P$31, SJ1.2
IO21: IC4.3 (BCLK), IC5.P$33
IO22: IC4.4 (DACDAT), IC5.P$36
IO23: IC5.P$37, P3.SDI/MOSI, P3.SDI/MOSI1
IO25: IC4.5 (DACLRC), IC4.7 (ADCLRC), IC5.P$10
IO26: IC5.P$11, P3.DC/RS, P3.DC/RS1
IO27: IC4.6 (ADCDAT), IC5.P$12
IO32: IC5.P$8, IC9.10
IO33: C35.1, IC5.P$9, R29.1, SW1.B
IO34: C37.1, IC5.P$6, R31.1, SW1.E (2)
IO35: C33.1, IC5.P$7, R28.1, SW1.A
LHPOUT: IC4.9 (LHPOUT)
LIN: C13.1, IC4.20 (LLINEIN)
LOUT: C3.2, IC4.12 (LOUT)
MICBIAS: IC4.17 (MICBIAS)
MICIN: IC4.18 (MICIN)
unnamed: IC6.P$9, R24.2
unnamed: IC6.P$8, R19.1, R21.2
unnamed: Q2.1 (B), R25.1
unnamed: P2.P1, R19.2
unnamed: P1.P$2, R18.1
unnamed: Q3.1 (B), R26.1
unnamed: P3.SDD/MISO, P3.SDD/MISO1, SJ1.1
unnamed: J5.IN, R34.2
unnamed: Q4.1 (B), R27.1
unnamed: J6.IN, R35.2
unnamed: Q5.1 (B), R34.1
unnamed: Q6.1 (B), R35.1
unnamed: J7.IN, R39.1
unnamed: J11.IN, R51.1
unnamed: C53.1, IC10.9, R50.2, R51.2, R58.1
unnamed: J8.IN, R41.1
unnamed: C49.1, IC10.2, R38.2, R39.2, R46.1
unnamed: POT3.2 (W), R44.1
unnamed: C50.1, IC10.6, R40.2, R41.2, R47.1
unnamed: J12.IN, R53.1
unnamed: C54.1, IC10.13, R52.2, R53.2, R59.1
unnamed: POT2.2 (W), R42.1
unnamed: J9.IN, R43.1
unnamed: C51.1, IC11.2, R42.2, R43.2, R48.1
unnamed: J13.IN, R55.1
unnamed: C55.1, IC11.13, R54.2, R55.2, R60.1
unnamed: J10.IN, R45.1
unnamed: C52.1, IC11.6, R44.2, R45.2, R49.1
unnamed: J14.IN, R57.1
unnamed: C56.1, IC11.9, R56.2, R57.2, R61.1
unnamed: J1.IN, R4.2
unnamed: IC2.2, R4.1, R8.2
unnamed: D1.+, P4.9 (+12V), P4.10 (+12V)
unnamed: POT1.R1_1 (A), R8.1
unnamed: POT5.2 (W), R56.1
unnamed: IC2.1, POT1.R1_2 (W), POT1.R1_3 (B), R14.2
unnamed: C9.2, C12.2, R14.1, R16.1
unnamed: POT4.2 (W), R54.1
unnamed: J2.IN, R5.2
unnamed: IC2.6, R5.1, R9.2
unnamed: POT1.R2_1 (A), R9.1
unnamed: IC2.7, POT1.R2_2 (W), POT1.R2_3 (B), R15.2
unnamed: C5.2, IC4.26 (XTO), Q1.2
unnamed: C4.2, IC4.25 (XTI/MCLK), Q1.1
unnamed: C10.2, C13.2, R15.1, R17.1
unnamed: C7.1, IC3.1, R10.2, R12.1
unnamed: D1.-, F1.2
unnamed: C7.2, IC3.2, R6.2, R10.1
unnamed: C2.1, R1.1, R6.1
unnamed: C36.+, IC8.1 (VI), R30.1
unnamed: J3.IN, R12.2
unnamed: D2.-, P4.1 (-12V), P4.2 (-12V)
unnamed: C8.1, IC3.7, R11.2, R13.1
unnamed: C8.2, IC3.6, R7.2, R11.1
unnamed: C11.1, C14.1, IC4.16 (VMID)
unnamed: C3.1, R2.1, R7.1
unnamed: J4.IN, R13.2
unnamed: D2.+, F2.2
unnamed: L1.A, R32.1
RHPOUT: IC4.10 (RHPOUT)
RIN: C12.1, IC4.19 (RLINEIN)
ROUT: C2.2, IC4.13 (ROUT)
RTS: IC6.P$19, Q2.2 (E), R26.2, R27.2
RXD: IC5.P$34, IC6.P$21
TXD: IC5.P$35, IC6.P$20
VN_IO39: C47.1, IC5.P$5, Q5.3 (C), R36.2, SW2.P$1 (1), SW2.P$2 (2)
VP_IO36: C48.1, IC5.P$4, Q6.3 (C), R37.2, SW3.P$1 (1), SW3.P$2 (2)

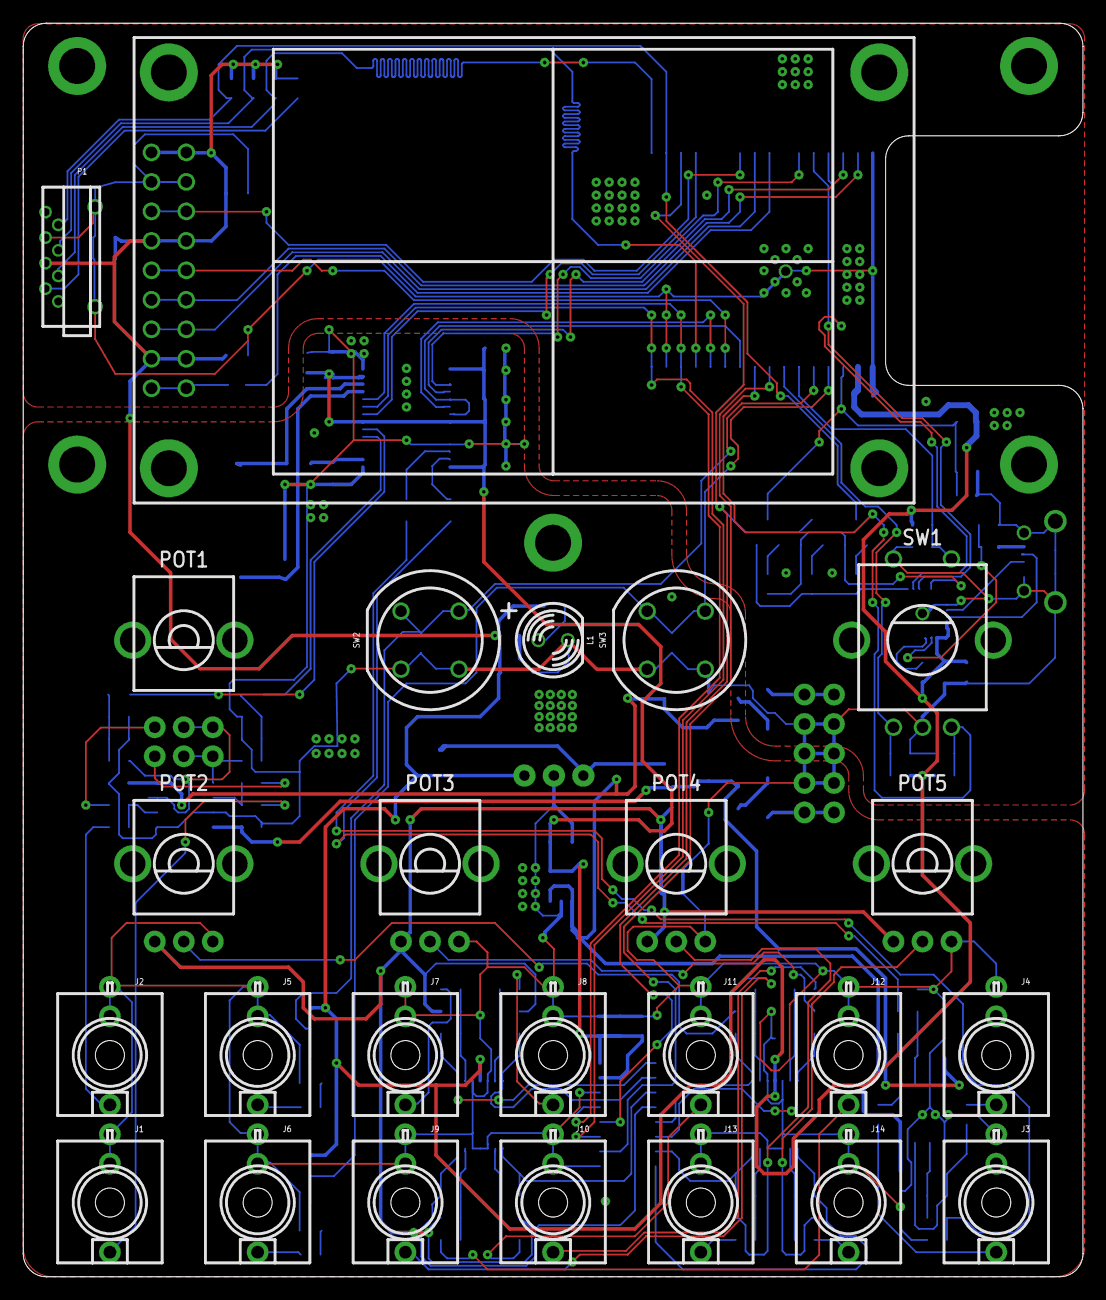
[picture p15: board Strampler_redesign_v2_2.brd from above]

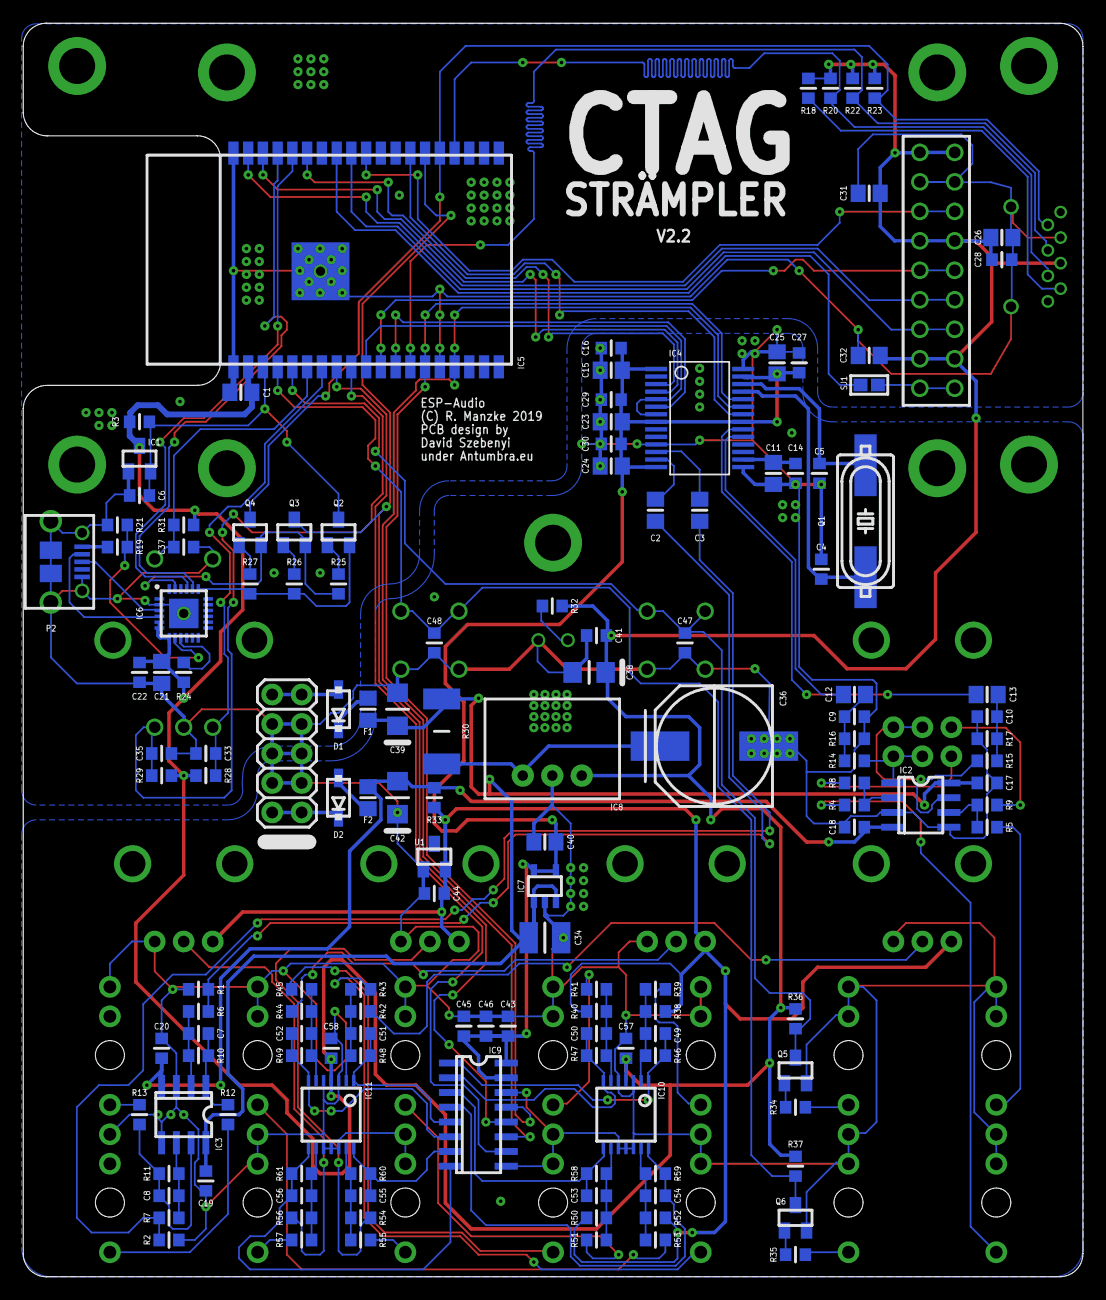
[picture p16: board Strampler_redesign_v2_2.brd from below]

Board: 2 copper layers, 91.3 x 108.0 mm, 174 parts (144 on the bottom side), 106 nets.

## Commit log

2026-07-07 Strämpler build pack: Eagle + KiCad boards, BOMs, fab/assembly + kit guides
    Antumbra 18HP redesign of the CTAG Strämpler, packaged for building in
    2026: original Eagle 7.3 files, KiCad 10 conversion (linked project with
    schematic), official + generated BOMs with EOL substitutions
    (WROVER-IE, WM8731 DNP), PCBWay turnkey package (fab BOM + CPL + guide +
    price estimate), and DIY kit ordering guide. CC BY-NC-SA 4.0, attribution
    to CTAG (Manzke/Lamp/Wantrupp) and Antumbra (Szebenyi).
    [BOM-PCBWay-assembly.csv, BOM-antumbra-official.csv, BOM-antumbra-official.xlsx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]
2026-07-07 Add RS-274X gerbers + drills (PCBWay rejects raw Eagle .brd)
    - gerbers/ : fab-ready zips for main board and panel, plotted with
    kicad-cli 10 from the KiCad conversions, plus a KiCad-origin
    position file for assembly
    - fix the converted panel: the Eagle importer put the t/bRestrict
    keep-out rectangles on layer "UNDEFINED", which KiCad's parser
    rejects on re-load; remapped to User.1
    - order guide updated to upload the gerber zips
    [strampler_panel_v2_2.kicad_pcb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]
2026-07-07 Fix panel gerbers: fill copper pours, convert art zones to filled shapes
    PCBWay's audit caught empty copper: the Eagle importer produces UNFILLED
    zones, which plot as nothing — copper pours, mask openings AND the 34k-rect
    silkscreen artwork were all missing from the first plot. Copper zones are
    now filled (pcbnew ZONE_FILLER) and all non-copper zones converted to
    filled gr_poly shapes via the pcbnew API. Panel .kicad_pcb updated to the
    fixed board; gerber zip regenerated (front silk now 4.4 MB of art).
    [strampler_panel_v2_2.kicad_pcb]
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2026-07-08 Order guide correction: the fixed gerber zip is what passed panel audit
2026-07-08 CRITICAL: regenerate main-board gerbers with zone refill (--check-zones)
    The first main-board gerbers were plotted from the GUI-saved board whose
    4 copper pour zones were UNFILLED — tracks and pads plotted (so the fab
    audit passed) but the ground pours were silently absent (B.Cu 126KB->959KB
    after refill). make-fab-files.sh now always plots with --check-zones.
    Panel zip regenerated by the same script for consistency.
    If you uploaded the pre-fix main zip to a fab: REPLACE IT before production.
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2026-07-18 Pre-payment audit of PCBWay cart re-download: BOM cell-identical to rev2, gerbers = fixed plots, line math exact
    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
2026-07-26 Completion parts ORDERED: 3 orders, ~$243 — plus 5 sourcing corrections
    All five units' completion parts are now on order across three suppliers.
    Thonk was dropped entirely (Mouser carries the SD holder at 1/3 the price).
    AliExpress $186.02 11 lines jacks, pots, dual-gang, encoders, TFTs,
    antennas + stubs, knobs, encoder caps,
    standoffs, screws
    Mouser $57.04 6 lines SD holders, tact switches, micro-USB,
    LED, power header, screen connector
    Amazon -- 2 lines ExcelValley 10->16 power cables, Lexar uSD
    Five parts were wrong or missing before this pass; each was ca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
2026-07-26 Add the gerber-vs-Eagle geometry checker used in the 2026-07-21 audit
    Independent cross-check that the KiCad-plotted gerbers and drills sent to
    PCBWay match the original Eagle .brd geometry — it parses the Eagle board
    directly rather than trusting KiCad, so a KiCad import error cannot hide
    itself. This is what the 07-21 audit ran (verdict: PASSED, sent files match
    the originals).
    Has been sitting untracked since that audit; committing so it survives.
    Claude-Session: https://claude.ai/code/session_011Vn5hk3EANtj3NfpP3EYjZ
2026-07-26 Correct: power cables + SD cards are NOT ordered, only a saved cart
    The previous commit recorded the Amazon items as "ORDERED 2026-07-26".
    Wrong — Arlo had a saved cart, not a placed order. Only the two module-parts
    orders (AliExpress $186.02, Mouser $57.04) are actually placed.
    Also adds the card-supplier guidance that prompted the correction:
    * Buy from B&H or Adorama — authorized dealers buying direct from the
    manufacturer, so counterfeits have no path into stock. SanDisk estimates
    ~1/3 of memory cards on the market are fake.
    * "Sold by Amazon" is NOT the safeguard it appears to be: Amazon commingles
    inventory across all sellers of an ASIN, so a third-party counterfe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
2026-07-26 SD card spec verified against firmware; cables ordered, cards deferred
    Adds a spec table for the card, checked against components/drivers/storage.c
    and sdkconfig.defaults rather than assumed:
    * FAT32 is mandatory. CONFIG_FATFS_LFN_NONE=y and no exFAT option is
    enabled, so FatFS mounts FAT12/16/32 only — an exFAT card just fails.
    * The card must arrive formatted. format_if_mount_failed = false.
    * 8.3 filenames only, which is where the 8-char sample id rule comes from.
    * Bus is 1-bit SDMMC at high speed; the audio path needs ~176 KB/s, so any
    Class 10 is far more than enough.
    On maximum size: there isn't one in the firmware, and FAT32 reaches ~2TB at
    these cluster sizes, so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
2026-08-29 POT1 dual-gang: Ali lot was wrong part; add Mouser substitute PTN092-V100115K1A
    The AliExpress "RD902F-B100K" lot delivered a right-angle mono pot. Board
    needs 9mm vertical 2-gang, 2.5mm pin grid, rows at 7.5/10mm. Mouser has no
    exact Alpha-pattern 100k linear; closest stocked drop-in is Same Sky
    PTN092-V100115K1A (179-PTN092V100115K1A, log taper, identical pin grid).
    Also corrects the footprint note: the ±4.4mm round holes are not an Alpha
    feature (Alpha tabs are ~11.3mm apart) — clip the tabs, panel nut holds it.
    Bourns PTD902 ruled out (5.0mm pin pitch).
    Claude-Session: https://claude.ai/code/session_01Qo7RDsze7j4vUdzMHyKW3a
    [BOM-antumbra-official.csv, mouser-bom-ONE-KIT.csv, parts-NOT-from-mouser.csv]
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2026-08-29 Panel: LED light window was copper — fix keep-out, refill, regenerate gerbers
    The Eagle→KiCad import parked tRestrict/bRestrict (938 rects each) on the
    non-copper User.1 layer, so the F/B.Mask window at the LED plotted correctly
    but the copper pours filled under it. The 2026-07 panel run came back with a
    copper wave instead of bare FR4 (original panel: mask gap, LED shines through).
    - Merge the 938 unique slivers (identical to the mask window polygons) into
    one polygon; replace the 1876 dead User.1 zones with a single keep-out rule
    area on F.Cu+B.Cu (copperpour not_allowed).
    - Refill zones (pcbnew ZONE_FILLER); verified filled copper ∩ window = 0 on
    both layers.
    - Regenerate ger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
    [strampler_panel_v2_2.kicad_pcb]
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2026-08-29 Main board: audit keep-outs after panel bug (all OK); restore SJ1 mask sliver
    Checked the main-board conversion for the same class of loss as the panel.
    All Eagle restrict areas (mounting-hole copper keep-outs, crystal via
    keep-out) survived as real rule areas; pcbnew verification shows filled
    copper ∩ keep-out = 0 across 64 zone/keep-out pairs. DRC "items_not_allowed"
    hits are each hole's own pad inside its own keep-out (as in Eagle).
    One dropped feature: the tStop sliver in the SJ package (mask opening between
    SJ1's pads, IO19 <-> TFT pin 9). Restored on B.Mask; main gerbers regenerated
    (copper layers differ only by sub-micron refill jitter under 10.0.5).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
    [Strampler_redesign_v2_2.kicad_pcb]
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2026-08-29 Panel v2_3: CV pot holes + POT1 hole -> 7.2mm for M7 bushings; gerbers regenerated + verified
    4x POT_LARGE_HOLE 9.2 -> 7.2 (POT2-5) and POT1's POT_MEDIUM 8.2 -> 7.2
    (position-matched against the main board; the other 8.2 is the encoder,
    untouched). Zones refilled; drill table clean (no 9.2 left); edge/silk
    byte-identical to v2_2; mask differs by exactly the 5 resized openings;
    LED window still copper-free. Order panels from the v2_3 zip.
    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
    [strampler_panel_v2_3.kicad_pcb]
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2026-09-02 Hex nut SKU correction: WQP-HN (WQP-KN = knurled); $0.10 ea confirmed
    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
2026-09-05 Board-rev note: micro-B is hybrid SMD+TH (why reflow skipped it); USB-C carries the same hybrid-vs-pure-SMD trade
    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
2026-09-08 Panels: JLCPCB v2_3 run arrived 2026-09-07 — LED window correct, HASL fine
    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
2026-09-08 panel-emu: experimental 6" E-mu-format front panel with 1/4" jacks (SVG/DXF generator + README)
    One-off for the hackerspace's E-mu system. Board-locked cutouts translated
    from panel v2_3; 14 Switchcraft 3/8"-32 jack holes in a 2x7 field wired
    back to the PJ398SM pads; SD slot and rail holes omitted. Mounting holes
    are placeholders until the cabinet is measured; panel must be <=2 mm for
    the PTN09 pot bushings.
    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
    [emu_panel_art.dxf, emu_panel_cut.dxf]
2026-09-08 panel-emu: keep the SD card slot
    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
    [emu_panel_art.dxf, emu_panel_cut.dxf]
2026-09-08 panel-emu: jack field as horizontal pairs (IN, TRIG, CV1-8, OUT top to bottom)
    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
    [emu_panel_art.dxf, emu_panel_cut.dxf]
2026-09-08 panel-emu: jack field moved to the left, board on the right
    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
    [emu_panel_art.dxf, emu_panel_cut.dxf]
2026-09-08 panel-emu: rounded blue boxes for the jack field and wordmark; vertical divider removed
    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
    [emu_panel_art.dxf, emu_panel_cut.dxf]
2026-09-08 panel-emu: blue box around the interface block instead of the wordmark
    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
    [emu_panel_art.dxf, emu_panel_cut.dxf]
2026-09-08 panel-emu: CV 5-8 jacks in a row under their knobs; 2x5 left field at 1" pitch; three rounded boxes
    Board region raised to y=18 so the 1/4" row clears the PCB's bottom edge
    (PCB is 108 mm tall in the 128.5 mm region); box bottoms clear the corner
    mount holes.
    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
    [emu_panel_art.dxf, emu_panel_cut.dxf]
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2026-09-08 panel-emu: wordmark centred in its band, subtitle dropped
    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
    [emu_panel_art.dxf, emu_panel_cut.dxf]
2026-09-08 panel-emu: wordmark alone, centred vertically in its band
    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
    [emu_panel_art.dxf, emu_panel_cut.dxf]
2026-09-08 panel-emu: IN L/R moved to the row above OUT
    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
    [emu_panel_art.dxf, emu_panel_cut.dxf]
2026-09-08 panel-emu: left box top aligned with the interface box; triggers labelled TR1/TR2
    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
    [emu_panel_art.dxf, emu_panel_cut.dxf]
2026-09-08 panel-emu: CV said once per group, numbered jacks, unlabelled attenuator knobs
    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
    [emu_panel_art.dxf, emu_panel_cut.dxf]
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2026-09-08 panel-emu: bus-normalled jack 1 + TR1 with KBD/TRIG A-off-B toggles (E-mu keyboard/trigger buses)
    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
    [emu_panel_art.dxf, emu_panel_cut.dxf]
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2026-09-08 panel-emu: ±12 V regulation designed onto the panel (7812/7912 tab holes + BOM), toggle-to-jack indicator lines, toggle labels above
    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
    [emu_panel_art.dxf, emu_panel_cut.dxf]
2026-09-08 panel-emu: cabinet has wood rails — mounting holes sized for wood screws, pattern free
    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
    [emu_panel_art.dxf, emu_panel_cut.dxf]
2026-09-08 panel-emu: one ganged KYBD 1/off/2 switch (3PDT) normals jack 1, TR1 and TR2 from VOICE/GATE/TRIG
    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
    [emu_panel_art.dxf, emu_panel_cut.dxf]
2026-09-08 panel-emu: drop the indicator lines; switch label names its targets
    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
    [emu_panel_art.dxf, emu_panel_cut.dxf]
2026-09-08 panel-emu: KYBD switch is DPDT — jack 1 + TR1 only, TR2 stays plain
    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
    [emu_panel_art.dxf, emu_panel_cut.dxf]
2026-09-08 panel-emu: two KYBD switches, one per column (jack 1+TR1, jack 2+TR2), four switching jacks
    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
    [emu_panel_art.dxf, emu_panel_cut.dxf]
2026-09-08 panel-emu: light chain line down each column from KYBD switch through TR to the V/oct jack
    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
    [emu_panel_art.dxf, emu_panel_cut.dxf]
2026-09-08 panel-emu: regulators off the panel (wood rail behind the top strip) — sub-board behind the PCB; rail-height check for the bottom rows
    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
    [emu_panel_art.dxf, emu_panel_cut.dxf]
2026-09-08 panel-emu: labels — CV on every CV jack, V/OCT and ±5V between the pairs, buttons labelled TR1/TR2
    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
    [emu_panel_art.dxf, emu_panel_cut.dxf]
2026-09-08 panel-emu: IN / OUT between the L/R pairs
    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
    [emu_panel_art.dxf, emu_panel_cut.dxf]
2026-09-08 panel-emu: row words at jack-label size; chain lines drop the label-to-hole stubs
    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
    [emu_panel_art.dxf, emu_panel_cut.dxf]
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2026-09-08 panel-emu: WiFi glyph under the antenna hole (SVG paths + DXF arcs)
    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
    [emu_panel_art.dxf, emu_panel_cut.dxf]
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2026-09-08 panel-emu: L-shaped jack box joining the left field and the CV 5-8 row; E-mu-style blue edge border
    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
    [emu_panel_art.dxf, emu_panel_cut.dxf]
2026-09-08 panel-emu: solid blue edge band bleeding to the panel edge
    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
    [emu_panel_art.dxf, emu_panel_cut.dxf]
2026-09-08 panel-emu: CV 3/4 on the bottom row (CV 3-8 read across the bottom); italic wordmark
    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
    [emu_panel_art.dxf, emu_panel_cut.dxf]
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
